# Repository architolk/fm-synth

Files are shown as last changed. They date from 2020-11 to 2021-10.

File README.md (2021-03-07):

# dXFM2

A FM synthesizer with a lot of knobs and no menu!

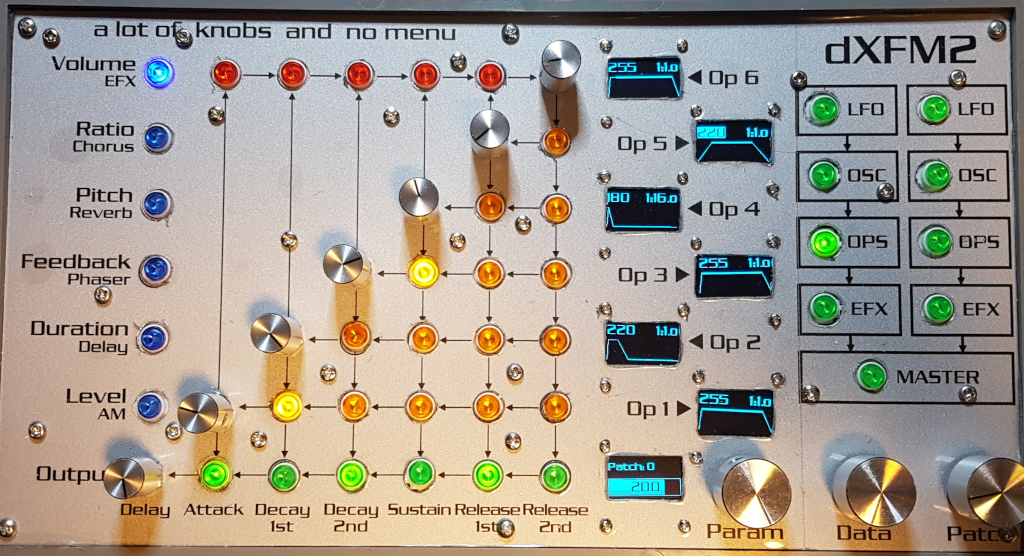
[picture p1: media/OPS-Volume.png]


Always wanted to create lush FM sounds? But to afraid of the menu-driven horrors of FM synthesizers, like the illustrious Yamaha DX7?

The dXFM2 aims to be just that: an FM synthesizer, with the physical feel of an analog synthesizer: a lot of knobs and no menu.

The dXFM2 is based on the incredible work of René Ceballos. He created the XFM2 synthesizer module, a 64-voice, 2-part, 6-operator FM synthesizer with built-in effects processor, built on an FPGA chip. You can find all the information at [www.futur3soundz.com](https://www.futur3soundz.com/xfm2). The dXFM2 complements this with the physical controls for the FPGA chip, managed by a Teensy 4.0.

## Build description

All build descriptions can be found [here](build/README.md). Please note that this is a somewhat free-format description and not intended as build instructions: most things I just found out on-the-fly, so some descriptions might not be completely correct any more.

## Concept of the synth

I always wanted to have an FM synth that I could "understand" just from looking at the display. I do understand the concepts of FM synthesis: carriers that are modulated by modulators. But in most FM synthesizers, it is not clear *which* operator is a carrier and *which* operator is a modulator, and to what extend. The dXFM2 overcomes this problem:

- Every dial corresponds to exactly one operator (the 1 knob for 1 function principle);
- A dedicated dial is used for the output of the synth;
- A green LED indicates that the operator in that column is a **carrier** (follow the arrows): the "green row" corresponds to the output of the synth;
- A yellow LED indicates that the operator in that column is a **modulator** for the operator in the corresponding row;
- A red LED indicates that the operator in that column is a **modulator** for operator 6, notably creating a feedback loop.

This LED-matrix makes the carrier-modulator algorithm visible in a what-you-see-is-what-you-get kind of way. And you can change this on the fly, just by pressing the LED (it's actually a push button).

Some other parameters are very important for the FM sound synthesis:
- The level of the operator;
- The amplitude envelope shape;
- The ratio between operators;
- Whether an operator is modulating itself (feedback).

An as you can see: every operator has its own dedicated small LED screen that displays just this information. The seventh LED screen depicts global information, or in this case: the output volume and the active patch.

## Operating the dXFM2
Although the sound of the FM synthesizer is pretty much *in your face*, the manipulation of that sound does actually involve a bit of menus. For this, you use the green LED buttons on the right side of the synthesizer, selecting a specific page. This activates a particular set of options, which you can further select by using the blue LED buttons on the left side of the synthesizer.

When you look at the green LED buttons, you see that two rows of identical options are available. The dXFM2 has two identifical FM synth units, and by selected between the left or right column, you select the unit for which you want to change a parameter.

- **[LFO](doc/LFO-menu.md)** will enable the parameter page for the low frequency oscillator;
- **[OSC](doc/OSC-menu.md)** will enable the parameter page for the sound oscillators;
- **[OPS](doc/OPS-menu.md)** will enable the parameter page for the operators (selected by default);
- **[EFX](doc/EFX-menu.md)** will enable the parameter page for the effects;
- **[MASTER](doc/MASTER-menu.md)** will enable the parameter page for some global parameters.

And if you really want to do some menu-diving, three additional dials are available:
- The **Param** dial gives you access to a regular menu. From this menu, you can change some more exotic parameters or have some extra options to ease the workflow while shaping FM sounds.
- With the **Data** dial you change some parameter value, as selected with the Param dial.
- With the **Patch** dial you activate a previously stored patch from the XFM2 memory banks (127 patches are available). Select a patch by turning the dial, and activate a patch by pushing the dial (all dials are actually push buttons as well as encoders).

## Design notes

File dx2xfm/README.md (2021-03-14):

# dx2xfm

Conversion code to read a Sysex DX7 file and convert it to XFM2 parameters.

Build: `mvn clean package`

Usage: `./dx2xfm.sh`. This expects a file dx7.syx in the same directory.

## Original DX7 Sysex parameters:

The table below give the DX7 Sysex parameters, captures from the [original DX7 manual](https://usa.yamaha.com/files/download/other_assets/9/333979/DX7E1.pdf), as is available at [the official Yamaha website](https://usa.yamaha.com/support/manuals/index.html?l=en&c=music_production&k=dx7).

| Op 6 | Op 5 | Op 4 | Op 3 | Op 2 | Op 1 | Range | Parameter |
|---|---|---|---|---|---|---|---|
| 0 | 21 | 42 | 63 | 84 | 105 | 0-99 | Op envelope rate 1 |
| 1 | 22 | 43 | 64 | 85 | 106 | 0-99 | Op envelope rate 2 |
| 2 | 23 | 44 | 65 | 86 | 107 | 0-99 | Op envelope rate 3 |
| 3 | 24 | 45 | 66 | 87 | 108 | 0-99 | Op envelope rate 4 |
| 4 | 25 | 46 | 67 | 88 | 109 | 0-99 | Op envelope level 1 |
| 5 | 26 | 47 | 68 | 89 | 110 | 0-99 | Op envelope level 2 |
| 6 | 27 | 48 | 69 | 90 | 111 | 0-99 | Op envelope level 3 |
| 7 | 28 | 49 | 70 | 91 | 112 | 0-99 | Op envelope level 4 |
| 8 | 29 | 50 | 71 | 92 | 113 | 0-99 | KB level scale breakpoint (from A-1 to C8, C3 = 27) |
| 9 | 30 | 51 | 72 | 93 | 114 | 0-99 | KB level scale, left depth |
| 10 | 31 | 52 | 73 | 94 | 115 | 0-99 | KB level scale, right depth |
| 11 | 32 | 53 | 74 | 95 | 116 | 0-3 | Left curve (0=-LIN, 1=-EXP, 2=+EXP, 3=+LIN) |
| 12 | 33 | 54 | 75 | 96 | 117 | 0-3 | Right curve (0=-LIN, 1=-EXP, 2=+EXP, 3=+LIN) |
| 13 | 34 | 55 | 76 | 97 | 118 | 0-7 | Rate scaling |
| 14 | 35 | 56 | 77 | 98 | 119 | 0-3 | AMP Mod sensitivity |
| 15 | 36 | 57 | 78 | 99 | 120 | 0-7 | Key velocity sensitivity |
| 16 | 37 | 58 | 79 | 100 | 121 | 0-99 | Operator output level |
| 17 | 38 | 59 | 80 | 101 | 122 | 0-1 | 0=Ratio, 1=Fixed pitch |
| 18 | 39 | 60 | 81 | 102 | 123 | 0-31 | Coarse frequency ratio |
| 19 | 40 | 61 | 82 | 103 | 124 | 0-99 | Fine frequency ratio (1.00 - 1.99 multiplier)|
| 20 | 41 | 62 | 83 | 104 | 125 | 0-14 | Detune (7 = 0%) |

| Nr | Range | Parameter |
|----|---|---|
| 126 | 0-99 | Pitch envelope rate 1 |
| 127 | 0-99 | Pitch envelope rate 2 |
| 128 | 0-99 | Pitch envelope rate 3 |
| 129 | 0-99 | Pitch envelope rate 4 |
| 130 | 0-99 | Pitch envelope level 1 |
| 131 | 0-99 | Pitch envelope level 2 |
| 132 | 0-99 | Pitch envelope level 3 |
| 133 | 0-99 | Pitch envelope level 4 |
| 134 | 0-31 | Algorithm |
| 135 | 0-7 | Feedback |
| 136 | 0-1 | Oscillator sync (0=off, 1=on)|
| 137 | 0-99 | LFO Speed |
| 138 | 0-99 | LFO Delay |
| 139 | 0-99 | LFO Pitch mod depth |
| 140 | 0-99 | LFO Amp mod depth |
| 141 | 0-1 | LFO Sync (0=off, 1=on) |
| 142 | 0-5 | LFO Waveform (0:TR, 1:SD, 2:SU, 3:SQ, 4:SI, 5:SH)
| 143 | 0-7 | Pitch mod sensitivity |
| 144 | 0-48 | Transpose (24 = C3) |
| 145 | ASCII | Voice name char 1 |
| 146 | ASCII | Voice name char 2 |
| 147 | ASCII | Voice name char 3 |
| 148 | ASCII | Voice name char 4 |
| 149 | ASCII | Voice name char 5 |
| 150 | ASCII | Voice name char 6 |
| 151 | ASCII | Voice name char 7 |
| 152 | ASCII | Voice name char 8 |
| 153 | ASCII | Voice name char 9 |
| 154 | ASCII | Voice name char 10 |

## Explanation of the DX7 parameters

[Understanding the DX7, Jay Chapman](https://www.muzines.co.uk/articles/understanding-the-dx7/7842) and [How to program the DX7, Bo Tomlyn](https://homepages.abdn.ac.uk/d.j.benson/pages/dx7/manuals/prgrmdx7.pdf) give a lot of useful insights.

Very detailed information about the DX7 envelope generators can be found here:
- [The Yamaha DX7 Envelope Generator, part one](https://tlbflush.org/notes/post/dx7eg1/)
- [The Yamaha DX7 Envelope Generator, part two](https://tlbflush.org/notes/post/dx7eg2/)
- [The Yamaha DX7 Envelope Generator, part three](https://tlbflush.org/notes/post/dx7eg3/)
- [The Yamaha DX7 Envelope Generator, part four](https://tlbflush.org/notes/post/dx7eg4/)

Most important conclusions from this information:
- Both envelope increase and decrease are non-lineair.
- Envelope increase is faster than envelope decrease.
- Envelope decrease is exponential, envelope increase is quadratic.

## XFM2 conversion

### Algorithm

| DX7 | XFM2 |
|-----|---|
| 134 | 1 - 6 |

- The algorithms of the DX7 need to be converted to the bitmapped version for the XFM2.
- Mark that the feedback bit (making a XFM2 operator modulates itself) needs to be included as well!
- Algorithm 4 and 6 have feedback that is not self-modulated (from 4 to 6 and from 5 to 6): so probably operator 6 won't have a feedback bit set!

### Feedback

| DX7 | XFM2 |
|-----|---|
| 135 | 7 - 12 |

- DX7 has only one feedback parameter, range 0-7
- XFM2 has a feedback parameter per operator, range 0-255
- The value from DX7 needs to be copied to the feedback parameter of the XFM2 for the operator that has feedback, according to the algorithm.
- Not tested, but assuming a lineair conversion scale: 255/7
- Not sure: is the feedback parameter used for algorithms 4 and 6, or do these algorithms use the operator output level from operator 4 (for algorithm 4) and operator 5 (for algorithm 6)? We assume the the latter: the XFM2 feedback parameter is only for self modulation!

### Oscillator keyboard sync

| DX7 | XFM2 |
|-----|---|
| 136 | 13 |

- DX7 has global oscillator sync, range 0-1
- XFM2 has bitwise oscillator sync, per operator, LSB = operator 1
- When DX7 has oscillator sync enabled, set the XFM2 oscillator sync parameter to 0b00111111 (=63)

### Operator mode

| DX7 | XFM2 |
|-----|---|
| 17,38,59,80,101,122 | 14 |

- DX7 has a parameter per operator. 0 = ratio, 1 = fixed pitch
- XFM2 has a bitwise parameter. LSB = operator 1. 0 = ratio, 1 = fixed pitch

The conversion for the coarse & fine frequency parameters are different with respect to this parameter!

### Fixed pitch parameter conversion

When using fixed pitch operator mode, the frequency is obtained on the DX7 using the following formula: COARSE * FINE:
- COARSE is a value between 0-3, corresponding to 1Hz, 10Hz, 100Hz or 1000Hz (=HZ-COARSE);
- FINE is a value between 0-99, corresponding with multipliers 1 to 9.772
- The actual formula to get the frequency for the D7 is: Hz = HZ-COARSE * (1 + (FINE * 8.772 / 99))

When using fixed pitch operator mode, the frequency is obtained on the XFM2 using the following formula: COARSE * FINE:
- COARSE is a value between 0-255, frequency is calculated using the formula Hz = COARSE * 32.7
- FINE is a value between 0-255, using the same formula as with frequency fine ratio, so: 2^(FINE/256), for [equal temperament](https://en.wikipedia.org/wiki/Equal_temperament).
- The actual formula to get the frequency for the XFM2 is: Hz = COARSE * 32.7 * 2^(FINE/256)
- An approximation for this formula is: Hz = COARSE * 32.7 * (1 + (FINE/256) * (FINE/256) * 0.34 + (FINE/256) * 0.66)
- The multiplication range for the XFM2 FINE parameter can be calculated from this: it goes from 1 to 1.9946
- Need to check: this would mean that a frequency below 32.7 is not possible using fixed pitch rate. Maybe COARSE = 0 is actually 16.35?

Conversion of coarse & fine parameters in fixed pitch mode needs to be combined: the resulting value for the XFM2 coarse parameter depends on both the coarse & fine parameters of the DX7, for reference see this table:

|DX7 Coarse | DX7 Fine | Hz | XFM2 Coarse | XFM2 Fine |
|---|---|----|---|---|
| 1 | 0 | 10 Hz | ? | ? |
| 1 | 50 | 54 Hz | 1 | 187 |
| 1 | 99 | 98 Hz | 2 | 148 |
| 2 | 0 | 100 Hz | 3 | 7 |
| 2 | 10 | 189 Hz | 5 | 53 |
| 2 | 99 | 997 Hz | 29 | 11 |
| 3 | 0 | 1000 Hz | 30 | 7 |
| 3 | 10 | 1886 Hz | 57 | 4 |
| 3 | 99 | 9772 Hz | 298 | 1 |

The correct conversion is as follows:
- XFM2-COARSE = Hz / 32.7, rounded down (not using fractions), Hz being the "correct" frequency as calculated for the DX7
- Let HZ-FINE be the fine ratio in Hz needed get to the "correct" frequency: HZ-FINE = (Hz - XFM2-COARSE) / Hz
- XFM2-FINE = 256 / Log2(1 + HZ-FINE)

**NB**: this conversion is ONLY correct for XMF2 Tuning parameter value 0 (= normal tuning = [equal temperament](https://en.wikipedia.org/wiki/Equal_temperament))

### Frequency coarse ratio

| DX7 | XFM2 |
|-----|---|
| 18,39,60,81,102,123 | 15-20 |

- Coarse frequency works the same for DX7 and XFM2
- Range of the XFM2 runs all the way up to 255, DX7 only goes to 31: XFM2 can have higher coarse frequency rates.
- A coarse frequency of 0 on the DX7 is usually depicted as ratio 0.50 (what it actually is: a sub-oscillator)

### Frequency fine ratio

| DX7 | XFM2 |
|-----|---|
| 19,40,61,82,103,124 | 21-26 |

- Fine ratio on the DX7 is a percentage of the frequency. A4 (=440 Hz) with frequency ratio 1.10 (coarse = 1, fine = 10) results in a frequency of 484. The calculation is F = Fc * (1 + Rf/100), F being the resulting frequency, Fc the frequency with only the coarse part and Rf the fine ratio parameter value.
- Fine ratio on the XFM2 is a percentage of an octave. Using [equal temperament](https://en.wikipedia.org/wiki/Equal_temperament), this means that the calculation is actually F = Fc * 2^(Rf/256). So to get the correct ratio, the value is actually fine = 35.
- The correct conversion would be: XFM2 fine = 256 / Log2(1 + Rf/100), Rf being the fine ratio parameter value of the DX7.

**NB**: this conversion is ONLY correct for XMF2 Tuning parameter value 0 (= normal tuning = [equal temperament](https://en.wikipedia.org/wiki/Equal_temperament))

### Detune

| DX7 | XFM2 |
|-----|---|
| 20,41,62,83,104,125 | 27-32 |

- DX7 detune is ranged 0-14, 0 corresponds to -7, 7 corresponds to 0, 14 corresponds to +7
- XFM2 detune is ranged 0-255, 0 corresponeds to -127, 128 corresponds to 0, 127 corresponds to +127
- DX7 detune segments an fine pitch interval of the DX7 (rang -0.007 to +0.007? Not sure..)
- XFM2 detune is ranged in cents, so an interval within a semitone of an octave (see also frequency fine ratio)
- The means: DX7 has detune with respect to frequency, XFM2 has detune with respect to semitones: same different as for frequency fine ratio. But because the intervals are so small, we will probably get away with a fixed conversion ratio.

### Levels

| DX7 | XFM2 |
|-----|---|
| 16,37,58,79,100,121 | 33 - 38 |

- Levels on the DX7 range from 0-99
- Levels on the XFM2 range from 0-255
- Unsure whether the conversion should be linear or some other function. Assumption is linear, so LEVEL * 255/99
- Maybe this info is needed? https://sound.stackexchange.com/questions/31709/what-is-the-level-of-frequency-modulation-of-many-synthesizers

DX7 Levels with respect to modulation index (from [Music: a mathematical offering, Apendix B](https://homepages.abdn.ac.uk/d.j.benson/pages/html/music.pdf), David Benson. The calculation in [Synthesis: FM pt2](https://sites.google.com/site/yalaorg/audio-music-synthesis/fmsynth/fmsynthdx) are the same, but have a higher accuracy, and this page describes the actual formula that is used:

Let:
- DX7: the parameter value (range 0-99)
- TL, the TL-number (?), TL = 99-DX7 for DX7>=20, and for lower values we have to use a look-up table (the output is non-lineair)
- I: the modulation index, I = PI * 2^((33/16) - (TL/8))

Look-up table for TL:
DX7 | 0 | 1 | 2 | 3 | 4 | 5 | 6 | 7 | 8 | 9 | 10 | 11 | 12 | 13 | 14 | 15 | 16 | 17 | 18 | 19 |
----|---|---|---|---|---|---|---|---|---|---|----|----|----|----|----|----|----|----|----|----|
TL  |127|122|118|114|110|107|104|102|100| 98| 96 | 94 | 92 | 90 | 88 | 86 | 85 | 84 | 82 | 81 |

| DX7 | Index | Original | Difference |
|-----|---|---|---|
|  0 | 0.0002 | 0? | |
| 10 | 0.0032 | 0.003 | 6,79% |
| 20 | 0.0140 | 0.013 | 7,50% |
| 30 | 0.0332 | 0.031 | 7,22% |
| 40 | 0.0791 | 0.079 | 0,07% |
| 50 | 0.1880 | 0.188 | 0,01% |
| 60 | 0.4472 | 0.446 | 0,27% |
| 65 | 0.6897 | 0.690 | 0,05% |
| 70 | 1.0636 | 1.068 | 0,41% |
| 75 | 1.6403 | 1.639 | 0,08% |
| 80 | 2.5298 | 2.512 | 0,71% |
| 85 | 3.9014 | 3.894 | 0,19% |
| 90 | 6.0168 | 6.029 | 0,20% |
| 95 | 9.2792 | 9.263 | 0,17% |
| 99 | 13.123 | 13.119 | 0,03% |

([this excel](../doc/fmsynthesis/DX7ModulationIndex.xlsx) sheet has all the individual numbers and the actual calculation).

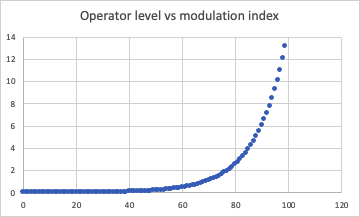
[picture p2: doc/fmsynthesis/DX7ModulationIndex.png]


The numbers differ a bit from the numbers in  *FM Theory & Applications, John Chowning*, the third column named "Original". Especially the calculated index for 0 seems a bit odd, probably the result of using an exponential function with y asymptote = 0. The DX7 would not use a function to calculate these indices, but a lookup table, so param value 0 would probably be set to modulation index 0. But as you can see from the fourth column and the graph below, the differences are very small. From param value 40, the difference is always less than 1%.

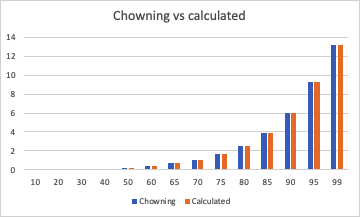
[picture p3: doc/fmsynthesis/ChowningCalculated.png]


### Key velocity sensitivity

| DX7 | XMF2 |
|-----|---|
| 15,36,57,78,99,120 | 39 - 44 |

### KB level scale

| Param | DX7 | XFM2 |
|---|-----|---|
| Breakpoint | 8,29,50,71,92,113 | 45 - 50 |
| Left depth | 9,30,51,72,93,114 | 51 - 56 |
| Right depth | 10,31,52,73,94,115 | 57 - 62 |
| Left curve | 11,32,53,74,95,116 | 63 - 68
| Right curve | 12,33,54,75,96,117 | 69 - 74 |

### Operator level envelope

| Param | DX7 | XFM2 |
|---|-----|---|
| L1 | 4,25,46,67,88,109 | 75 - 80 |
| L2 | 5,26,47,68,89 | 82 - 87 |
| L3 | 6,27,48,69,90 | 89 - 94 |
| L4 | 7,28,49,70,91,112 | 96 - 101 |
| R1 | 0,21,42,63,84,105 | 103 - 108 |
| R2 | 1,22,43,64,85,106 | 110 - 115 |
| R3 | 2,23,44,65,86,107 | 117 - 122 |
| R4 | 3,24,45,66,87,108 | 124 - 129 |

- The DX7 envelope doesn't start at 0, but at the level of L4, which most of the time will be 0.
- The XFM2 envelope starts at level L0. So to convert the levels correctly: L4 of the DX7 should also be used to calculate L0 of the XFM2:

| Param | DX7 | XFM2 |
|---|-----|---|
| L0 | 7,28,49,70,91,112 | 181 - 186 |

### Pitch envelope

| Param | DX7 | XFM2 |
|---|-----|---|
| L1 | 130 | 130 |
| L2 | 131 | 131 |
| L3 | 132 | 132 |
| L4 | 133 | 133 |
| R1 | 126 | 134 |
| R2 | 127 | 135 |
| R3 | 128 | 136 |
| R4 | 129 | 137 |

- The DX7 envelope doesn't start at 0, but at the level of L4, which most of the time will be 0.
- The XFM2 envelope starts at level L0. So to convert the levels correctly: L4 of the DX7 should also be used to calculate L0 of the XFM2:

| Param | DX7 | XFM2 |
|---|-----|---|
| L0 | 133 | 205 |

### Pitch envelope range

| DX7 | XFM2 |
|-----|---|
| - | 138 |

- The pitch envelope range defines the range of the pitch envelope on the XFM2, in octaves.
- The DX7 doesn't have this parameter. The pitch envelope range is fixed to -4 to +4 octaves (0 = -4, 50 = 0, 99 = -4)

### Pitch envelope range velocity

| DX7 | XFM2 |
|-----|---|
| - | 139 |

- The pitch envelope range velocity sets how much the pitch envelope range changes with MIDI velocity on the XFM2.
- The DX7 doesn't have this parameter. The pitch envelope range is fixed to -4 to +4 octaves.
- Leave this parameter to 0: pitch envelope range velocity is not available on the DX7.

### Operator level envelope rate key

| DX7 | XFM2 |
|-----|---|
| 13,34,55,76,97,118 | 140 - 145 |

- This parameter will make higher notes have a faster envelope than lower, bass, notes. It works rougly the same on the DX7 and XFM2.
- The operator level envelope rate key on the XFM2 works the same as other rates: 0 gives the normal, slowest envelope, 255 gives a very snappy, fast envelope (at high notes).
- The DX7 works the same way, but with a different scale: 0 gives the normal, slowest envelope, 7 gives the fasted envelope (at high notes).

### Pitch envelope rate key

| DX7 | XFM2 |
|-----|---|
| - | 146 |

- The pitch envelope rate key on the XFM2 works the same way as the operator level envelope rate key: changing the timing
- THe DX7 doesn't have this parameter. The pitch envelope timing is fixed.

### LFO Pitch depth

| DX7 | XFM2 |
|-----|---|
| 139 | 149 |

### LFO Amp depth

| DX7 | XFM2 |
|-----|---|
| 140 | 150 |

### LFO Speed

| DX7 | XFM2 |
|-----|---|
| 137 | 151 |

- The LFO speed of the DX7 might go from 0.1 Hz to 60 Hz, but other values are 3.5 Hz to 47 Hz. It seems quite linear at the bottom, but high values seems to increase the speed more than low values.
- The LFO speed of the XFM2 seems pretty linear, a multiplication of 2.76 BPM per parameter value (276 BPM for value 100, 28 BPM for value 10), but higher values also seems to increase the speed?
- The LFO's of the DX7 and XFM2 do not have the same speed range apparently, so some conversion seems to be necessary?

### LFO Sync

| DX7 | XFM2 |
|-----|---|
| 141 | 152 |

### LFO Wave

| DX7 | XFM2 |
|-----|---|
| 142 | 153 |

The DX7 and the XFM2 have the same possible wave forms for the LFO, if you would consider the S/H (Sample & Hold) waveform the same as the random waveform of the XFM2, using the following conversion table:

| Waveform | DX7 | XFM2 |
|---|-----|---|
| Triangle | 0 | 0 |
| Saw down | 1 | 3 |
| Saw up | 2 | 2 |
| Square | 3 | 1 |
| Sinus | 4 | 4 |
| S/H, Random | 5 | 5 |

### LFO Fade/Delay

| DX7 | XFM2 |
|-----|---|
| 138 | 154 |

- This parameter is called "Fade" on the XFM2 and "Delay" on the DX7. Not sure if it is the same thing.
- From the XFM2 manual, "Fade" is the time to ramp up to the specified LFO effect.
- From the DX7 manaul, "Delay" is simply that: a delay of the LFO effect.
- This assumes that the functionality is somewhat different: a ramp-up effect vs a delayed effect

### LFO Amp sensitivity

| DX7 | XFM2 |
|-----|---|
| 14,35,56,77,98,119 | 159 - 164 |

### Transpose

| DX7 | XFM2 |
|-----|---|
| 144 | 174 |

Transpose 24 = no transpose, so 24 corresponds with C4.

Midi note implementation:
- C4 = MIDI 60 = 261.63 Hz
- A4 = MIDI 69 = 440.00 Hz

### (LFO) Pitch sensitivity

| DX7 | XFM2 |
|-----|---|
| 143 | 222 - 227 |

- The DX7 pitch sensitivity parameter sets the same value for every operator.
- The XFM2 has a pitch sensitivity parameter per operator.

## Conversion reference

The table below gives a reference guide for all 154 parameters of the DX7

| DX7 | Param | XFM2 |
|-----|---|---|
| 0 | OP-6 Envelope rate 1 | 108 |
| 1 | OP-6 Envelope rate 2 | 115 |
| 2 | OP-6 Envelope rate 3 | 122 |
| 3 | OP-6 Envelope rate 4 | 129 |
| 4 | OP-6 Envelope level 1 | 80 |
| 5 | OP-6 Envelope level 2 | 87 |
| 6 | OP-6 Envelope level 3 | 94 |
| 7 | OP-6 Envelope level 4 | 101 |
| 8 | OP-6 KB level scale breakpoint | 50 |
| 9 | OP-6 KB level scale, left depth | 56 |
| 10 | OP-6 KB level scale, right depth | 62 |
| 11 | OP-6 KB level scale, left curve | 68 |
| 12 | OP-6 KB level scale, right curve | 74 |
| 13 | OP-6 Rate scaling | 145 |
| 14 | OP-6 AMP Mod sensitivity | 164 |
| 15 | OP-6 Key velocity sensitivity | 44 |
| 16 | OP-6 Operator output level | 38 |
| 17 | OP-6 Operator mode (ratio/pitch) | 14 |
| 18 | OP-6 Coarse frequency ratio | 20 |
| 19 | OP-6 Fine frequency ratio | 26 |
| 20 | OP-6 Detune | 32 |
| 21 | OP-5 Envelope rate 1 |  |
| 22 | OP-5 Envelope rate 2 |  |
| 23 | OP-5 Envelope rate 3 |  |
| 24 | OP-5 Envelope rate 4 |  |
| 25 | OP-5 Envelope level 1 |  |
| 26 | OP-5 Envelope level 2 |  |
| 27 | OP-5 Envelope level 3 |  |
| 28 | OP-5 Envelope level 4 |  |
| 29 | OP-5 KB level scale breakpoint |  |
| 30 | OP-5 KB level scale, left depth |  |
| 31 | OP-5 KB level scale, right depth |  |
| 32 | OP-5 Left curve |  |
| 33 | OP-5 Right curve |  |
| 34 | OP-5 Rate scaling |  |
| 35 | OP-5 AMP Mod sensitivity |  |
| 36 | OP-5 Key velocity sensitivity |  |
| 37 | OP-5 Operator output level |  |
| 38 | OP-5 Operator mode (ratio/pitch) |  |
| 39 | OP-5 Coarse frequency ratio |  |
| 40 | OP-5 Fine frequency ratio |  |
| 41 | OP-5 Detune |  |
| 42 | OP-4 Envelope rate 1 |  |
| 43 | OP-4 Envelope rate 2 |  |
| 44 | OP-4 Envelope rate 3 |  |
| 45 | OP-4 Envelope rate 4 |  |
| 46 | OP-4 Envelope level 1 |  |
| 47 | OP-4 Envelope level 2 |  |
| 48 | OP-4 Envelope level 3 |  |
| 49 | OP-4 Envelope level 4 |  |
| 50 | OP-4 KB level scale breakpoint |  |
| 51 | OP-4 KB level scale, left depth |  |
| 52 | OP-4 KB level scale, right depth |  |
| 53 | OP-4 Left curve |  |
| 54 | OP-4 Right curve |  |
| 55 | OP-4 Rate scaling |  |
| 56 | OP-4 AMP Mod sensitivity |  |
| 57 | OP-4 Key velocity sensitivity |  |
| 58 | OP-4 Operator output level |  |
| 59 | OP-4 Operator mode (ratio/pitch) |  |
| 60 | OP-4 Coarse frequency ratio |  |
| 61 | OP-4 Fine frequency ratio |  |
| 62 | OP-4 Detune |  |
| 63 | OP-3 Envelope rate 1 |  |
| 64 | OP-3 Envelope rate 2 |  |
| 65 | OP-3 Envelope rate 3 |  |
| 66 | OP-3 Envelope rate 4 |  |
| 67 | OP-3 Envelope level 1 |  |
| 68 | OP-3 Envelope level 2 |  |
| 69 | OP-3 Envelope level 3 |  |
| 70 | OP-3 Envelope level 4 |  |
| 71 | OP-3 KB level scale breakpoint |  |
| 72 | OP-3 KB level scale, left depth |  |
| 73 | OP-3 KB level scale, right depth |  |
| 74 | OP-3 Left curve |  |
| 75 | OP-3 Right curve |  |
| 76 | OP-3 Rate scaling |  |
| 77 | OP-3 AMP Mod sensitivity |  |
| 78 | OP-3 Key velocity sensitivity |  |
| 79 | OP-3 Operator output level |  |
| 80 | OP-3 Operator mode (ratio/pitch) |  |
| 81 | OP-3 Coarse frequency ratio |  |
| 82 | OP-3 Fine frequency ratio |  |
| 83 | OP-3 Detune |  |
| 84 | OP-2 Envelope rate 1 |  |
| 85 | OP-2 Envelope rate 2 |  |
| 86 | OP-2 Envelope rate 3 |  |
| 87 | OP-2 Envelope rate 4 |  |
| 88 | OP-2 Envelope level 1 |  |
| 89 | OP-2 Envelope level 2 |  |
| 90 | OP-2 Envelope level 3 |  |
| 91 | OP-2 Envelope level 4 |  |
| 92 | OP-2 KB level scale breakpoint |  |
| 93 | OP-2 KB level scale, left depth |  |
| 94 | OP-2 KB level scale, right depth |  |
| 95 | OP-2 Left curve |  |
| 96 | OP-2 Right curve |  |
| 97 | OP-2 Rate scaling |  |
| 98 | OP-2 AMP Mod sensitivity |  |
| 99 | OP-2 Key velocity sensitivity |  |
| 100 | OP-2 Operator output level |  |
| 101 | OP-2 Operator mode (ratio/pitch) |  |
| 102 | OP-2 Coarse frequency ratio |  |
| 103 | OP-2 Fine frequency ratio |  |
| 104 | OP-2 Detune |  |
| 105 | OP-1 Envelope rate 1 |  |
| 106 | OP-1 Envelope rate 2 |  |
| 107 | OP-1 Envelope rate 3 |  |
| 108 | OP-1 Envelope rate 4 |  |
| 109 | OP-1 Envelope level 1 |  |
| 110 | OP-1 Envelope level 2 |  |
| 111 | OP-1 Envelope level 3 |  |
| 112 | OP-1 Envelope level 4 |  |
| 113 | OP-1 KB level scale breakpoint |  |
| 114 | OP-1 KB level scale, left depth |  |
| 115 | OP-1 KB level scale, right depth |  |
| 116 | OP-1 Left curve |  |
| 117 | OP-1 Right curve |  |
| 118 | OP-1 Rate scaling |  |
| 119 | OP-1 AMP Mod sensitivity |  |
| 120 | OP-1 Key velocity sensitivity |  |
| 121 | OP-1 Operator output level |  |
| 122 | OP-1 Operator mode (ratio/pitch) |  |
| 123 | OP-1 Coarse frequency ratio |  |
| 124 | OP-1 Fine frequency ratio |  |
| 125 | OP-1 Detune |  |
| 126 | Pitch envelope rate 1 | 134 |
| 127 | Pitch envelope rate 2 | 135 |
| 128 | Pitch envelope rate 3 | 136 |
| 129 | Pitch envelope rate 4 | 137 |
| 130 | Pitch envelope level 1 | 130 |
| 131 | Pitch envelope level 2 | 131 |
| 132 | Pitch envelope level 3 | 132 |
| 133 | Pitch envelope level 4 | 133 |
| 134 | Algorithm | 1 - 6 |
| 135 | Feedback | 7 - 12 |
| 136 | Oscillator sync | 13 |
| 137 | LFO Speed | 151 |
| 138 | LFO Delay | 154 |
| 139 | LFO Pitch mod depth | 149 |
| 140 | LFO Amp mod depth | 150 |
| 141 | LFO Sync | 152 |
| 142 | LFO Waveform | 153 |
| 143 | Pitch mod sensitivity | 222 - 227 |
| 144 | Transpose | 174 |
| 145 | Voice name char 1 | - |
| 146 | Voice name char 2 | - |
| 147 | Voice name char 3 | - |
| 148 | Voice name char 4 | - |
| 149 | Voice name char 5 | - |
| 150 | Voice name char 6 | - |
| 151 | Voice name char 7 | - |
| 152 | Voice name char 8 | - |
| 153 | Voice name char 9 | - |
| 154 | Voice name char 10 | - |

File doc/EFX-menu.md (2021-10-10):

# EFX Effects menu

| Blue | 6 (Out) | 0 (Op1) | 1 (Op2) | 2 (Op3) | 3 (Op4) | 4 (Op5) | 5 (Op6) |
|---|---|---|---|---|---|---|---|
| 0 |  |  | *Bitcrusher* Depth | *Decimator* Depth | *Filter* Hi pass | *Filter* Lo pass | EFX Routing |
| 1 | *Chorus* Dry | *Chorus* LR Phase | *Chorus* Speed | *Chorus* Feedback | *Chorus* Depth | *Chorus* Mode | *Chorus* Wet |
| 2 | *Reverb* Dry | | *Reverb* Decay |  | *Reverb* Damp | *Reverb* Mode | *Reverb* Wet |
| 3 | *Phaser* Dry | *Phaser* LR Phase/Offset | *Phaser* Speed | *Phaser* Feedback | *Phaser* Depth | *Phaser* Mode/Stages | *Phaser* Wet |
| 4 | *Delay* Dry | *Delay* Multiplier/Devider | *Delay* Time/Tempo | *Delay* Feedback | *Delay* Hi/Lo pass | *Delay* Mode | *Delay* Wet |
| 5 |  | *AM* LR Phase | *AM* Speed |  | *AM* Range |  | *AM* Depth |

Chorus/Flanger is the same effect, switching between those two is done via the **Mode** parameter.

Parameter value mapping:

| Value | 0 (Op1) | 1 (Op2) | 2 (Op3) | 3 (Op4) | 4 (Op5) | 5 (Op6) | 6 (Out) |
|---|---|---|---|---|---|---|---|
| 0 | 0 | 0 | 380 | 370 | 321 | 320 | 410 |
| 1 | 360 | 366 | 363 | 365 | 364 | 362 | 361 |
| 2 | 390 | 0 | 393 | 0 | 394 | 392 | 391 |
| 3 | 310 | 318/316 | 314 | 315 | 313 | 312/317 | 311 |
| 4 | 300 | 308/309 | 303/307 | 304 | 306/305 | 302 | 301 |
| 5 | 0 | 333 | 330 | 0 | 331 | 0 | 332 |

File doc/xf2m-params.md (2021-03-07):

# XFM2 params

This page gives an overview of all XFM2 parameters. It is a cross-reference to the assignment at the physical hardware level, to be sure that every parameter is covered.

- A *italic* item in the table below for the Blue buttons indicate that this option has two different parameters you can change. You need to toggle between these two parameters (by pressing the corresponding blue button again). The one you selected is marked with a bar below the corresponding parameter.
- **Op-1 dial** corresponds to turning the Op-1 dial. **Op dials** means that the parameter contains a bitwise setting for all operators, so a particular Op dial changes the parameter with respect to the corresponding operator.
- **Op dials click** corresponds to pressing an operator dial (using it as a push button).
- **Op-1 selected** corresponds to selecting operator-1 envelope. For the operator level envelopes, you select a particular operator by pressing the corresponding operator dial. To change the particular parameter, you use the corresponding dial for that parameter (as depicted at the bottom of the synth). This might be some *other* dial than the dial that corresponds to that operator!
- Most parameters work for both Unit #1 and Unit #2: you switch between units by selecting the corresponding **green** option. The exception are some parameters that are controlled by the master mixer, as depicted in the table below:

| Blue | Assignment | Unit |
|---|---|---|
| Pitch | Velocity sensitivity | 1 |
| Feedback | Velocity sensitivity | 2 |
| Duration | Mixer | 1 |
| Level | Mixer | 2 |

| Nr | Parameter | Green | Blue | Assignment |
|----|---|---|---|---|
| 0 | NOP | - | - | - |
| 1 | Algorithm Op-1 | - | - | Orange & Red LEDs, Op-1 row |
| 2 | Algorithm Op-2 | - | - | Orange & Red LEDs, Op-2 row |
| 3 | Algorithm Op-3 | - | - | Orange & Red LEDs, Op-3 row |
| 4 | Algorithm Op-4 | - | - | Orange & Red LEDs, Op-4 row |
| 5 | Algorithm Op-5 | - | - | Orange & Red LEDs, Op-5 row |
| 6 | Algorithm Op-6 | - | - | Orange & Red LEDs, Op-6 row |
| 7 | Feedback Op-1 | OPS | Feedback | Op-1 dial |
| 8 | Feedback Op-2 | OPS | Feedback | Op-2 dial |
| 9 | Feedback Op-3 | OPS | Feedback | Op-3 dial |
| 10 | Feedback Op-4 | OPS | Feedback | Op-4 dial |
| 11 | Feedback Op-5 | OPS | Feedback | Op-5 dial |
| 12 | Feedback Op-6 | OPS | Feedback | Op-6 dial |
| 13 | Oscillator sync | OSC | *Feedback* | Op dials |
| 14 | Operator mode | OPS | Pitch | Op dials click |
| 15 | Coarse ratio Op-1 | OPS | *Ratio* | Op-1 dial |
| 16 | Coarse ratio Op-2 | OPS | *Ratio* | Op-2 dial |
| 17 | Coarse ratio Op-3 | OPS | *Ratio* | Op-3 dial |
| 18 | Coarse ratio Op-4 | OPS | *Ratio* | Op-4 dial |
| 19 | Coarse ratio Op-5 | OPS | *Ratio* | Op-5 dial |
| 20 | Coarse ratio Op-6 | OPS | *Ratio* | Op-6 dial |
| 21 | Fine ratio Op-1 | OPS | *Ratio* | Op-1 dial |
| 22 | Fine ratio Op-2 | OPS | *Ratio* | Op-2 dial |
| 23 | Fine ratio Op-3 | OPS | *Ratio* | Op-3 dial |
| 24 | Fine ratio Op-4 | OPS | *Ratio* | Op-4 dial |
| 25 | Fine ratio Op-5 | OPS | *Ratio* | Op-5 dial |
| 26 | Fine ratio Op-6 | OPS | *Ratio* | Op-6 dial |
| 27 | Detune Op-1 | OPS | Pitch | Op-1 dial |
| 28 | Detune Op-2 | OPS | Pitch | Op-2 dial |
| 29 | Detune Op-3 | OPS | Pitch | Op-3 dial |
| 30 | Detune Op-4 | OPS | Pitch | Op-4 dial |
| 31 | Detune Op-5 | OPS | Pitch | Op-5 dial |
| 32 | Detune Op-6 | OPS | Pitch | Op-6 dial |
| 33 | Level Op-1 | OPS | Volume | Op-1 dial |
| 34 | Level Op-2 | OPS | Volume | Op-2 dial |
| 35 | Level Op-3 | OPS | Volume | Op-3 dial |
| 36 | Level Op-4 | OPS | Volume | Op-4 dial |
| 37 | Level Op-5 | OPS | Volume | Op-5 dial |
| 38 | Level Op-6 | OPS | Volume | Op-6 dial |
| 39 | Velo sense Op-1 | Master | Pitch/Feedback | Op-1 dial |
| 40 | Velo sense Op-2 | Master | Pitch/Feedback | Op-2 dial |
| 41 | Velo sense Op-3 | Master | Pitch/Feedback | Op-3 dial |
| 42 | Velo sense Op-4 | Master | Pitch/Feedback | Op-4 dial |
| 43 | Velo sense Op-5 | Master | Pitch/Feedback | Op-5 dial |
| 44 | Velo sense Op-6 | Master | Pitch/Feedback | Op-6 dial |
| 45 | KB level scale breakpoint Op-1 | LFO | Pitch | Op-1 dial |
| 46 | KB level scale breakpoint Op-2 | LFO | Pitch | Op-2 dial |
| 47 | KB level scale breakpoint Op-3 | LFO | Pitch | Op-3 dial |
| 48 | KB level scale breakpoint Op-4 | LFO | Pitch | Op-4 dial |
| 49 | KB level scale breakpoint Op-5 | LFO | Pitch | Op-5 dial |
| 50 | KB level scale breakpoint Op-6 | LFO | Pitch | Op-6 dial |
| 51 | KB level scale, left depth Op-1 | LFO | *Ratio* | Op-1 dial |
| 52 | KB level scale, left depth Op-2 | LFO | *Ratio* | Op-2 dial |
| 53 | KB level scale, left depth Op-3 | LFO | *Ratio* | Op-3 dial |
| 54 | KB level scale, left depth Op-4 | LFO | *Ratio* | Op-4 dial |
| 55 | KB level scale, left depth Op-5 | LFO | *Ratio* | Op-5 dial |
| 56 | KB level scale, left depth Op-6 | LFO | *Ratio* | Op-6 dial |
| 57 | KB level scale, right depth Op-1 | LFO | *Feedback* | Op-1 dial |
| 58 | KB level scale, right depth Op-2 | LFO | *Feedback* | Op-2 dial |
| 59 | KB level scale, right depth Op-3 | LFO | *Feedback* | Op-3 dial |
| 60 | KB level scale, right depth Op-4 | LFO | *Feedback* | Op-4 dial |
| 61 | KB level scale, right depth Op-5 | LFO | *Feedback* | Op-5 dial |
| 62 | KB level scale, right depth Op-6 | LFO | *Feedback* | Op-6 dial |
| 63 | KB level scale, left curve Op-1 | LFO | *Ratio* | Op-1 dial |
| 64 | KB level scale, left curve Op-2 | LFO | *Ratio* | Op-2 dial |
| 65 | KB level scale, left curve Op-3 | LFO | *Ratio* | Op-3 dial |
| 66 | KB level scale, left curve Op-4 | LFO | *Ratio* | Op-4 dial |
| 67 | KB level scale, left curve Op-5 | LFO | *Ratio* | Op-5 dial |
| 68 | KB level scale, left curve Op-6 | LFO | *Ratio* | Op-6 dial |
| 69 | KB level scale, right curve Op-1 | LFO | *Feedback* | Op-1 dial |
| 70 | KB level scale, right curve Op-2 | LFO | *Feedback* | Op-2 dial |
| 71 | KB level scale, right curve Op-3 | LFO | *Feedback* | Op-3 dial |
| 72 | KB level scale, right curve Op-4 | LFO | *Feedback* | Op-4 dial |
| 73 | KB level scale, right curve Op-5 | LFO | *Feedback* | Op-5 dial |
| 74 | KB level scale, right curve Op-6 | LFO | *Feedback* | Op-6 dial |
| 75 | Envelope level 1, Op-1 | OPS | Level | Op-1 dial (attack) / Op-1 selected |
| 76 | Envelope level 1, Op-1 | OPS | Level | Op-1 dial (attack) / Op-2 selected |
| 77 | Envelope level 1, Op-1 | OPS | Level | Op-1 dial (attack) / Op-3 selected |
| 78 | Envelope level 1, Op-1 | OPS | Level | Op-1 dial (attack) / Op-4 selected |
| 79 | Envelope level 1, Op-1 | OPS | Level | Op-1 dial (attack) / Op-5 selected |
| 80 | Envelope level 1, Op-1 | OPS | Level | Op-1 dial (attack) / Op-6 selected |
| 81 | NOP | - | - | - |
| 82 | Envelope level 2, Op-1 | OPS | Level | Op-2 dial (decay-1) / Op-1 selected |
| 83 | Envelope level 2, Op-1 | OPS | Level | Op-2 dial (decay-1) / Op-2 selected |
| 84 | Envelope level 2, Op-1 | OPS | Level | Op-2 dial (decay-1) / Op-3 selected |
| 85 | Envelope level 2, Op-1 | OPS | Level | Op-2 dial (decay-1) / Op-4 selected |
| 86 | Envelope level 2, Op-1 | OPS | Level | Op-2 dial (decay-1) / Op-5 selected |
| 87 | Envelope level 2, Op-1 | OPS | Level | Op-2 dial (decay-1) / Op-6 selected |
| 88 | NOP | - | - | - |
| 89 | Envelope level 3, Op-1 | OPS | Level | Op-4 dial (sustain) / Op-1 selected |
| 90 | Envelope level 3, Op-1 | OPS | Level | Op-4 dial (sustain) / Op-2 selected |
| 91 | Envelope level 3, Op-1 | OPS | Level | Op-4 dial (sustain) / Op-3 selected |
| 92 | Envelope level 3, Op-1 | OPS | Level | Op-4 dial (sustain) / Op-4 selected |
| 93 | Envelope level 3, Op-1 | OPS | Level | Op-4 dial (sustain) / Op-5 selected |
| 94 | Envelope level 3, Op-1 | OPS | Level | Op-4 dial (sustain) / Op-6 selected |
| 95 | NOP | - | - | - |
| 96 | Envelope level 4, Op-1 | OPS | Level | Op-5 dial (release-1) / Op-1 selected |
| 97 | Envelope level 4, Op-1 | OPS | Level | Op-5 dial (release-1) / Op-2 selected |
| 98 | Envelope level 4, Op-1 | OPS | Level | Op-5 dial (release-1) / Op-3 selected |
| 99 | Envelope level 4, Op-1 | OPS | Level | Op-5 dial (release-1) / Op-4 selected |
| 100 | Envelope level 4, Op-1 | OPS | Level | Op-5 dial (release-1) / Op-5 selected |
| 101 | Envelope level 4, Op-1 | OPS | Level | Op-5 dial (release-1) / Op-6 selected |
| 102 | NOP | - | - | - |
| 103 | Envelope rate 1, Op-1 | OPS | Duration | Op-1 dial (attack) / Op-1 selected |
| 104 | Envelope rate 1, Op-1 | OPS | Duration | Op-1 dial (attack) / Op-2 selected |
| 105 | Envelope rate 1, Op-1 | OPS | Duration | Op-1 dial (attack) / Op-3 selected |
| 106 | Envelope rate 1, Op-1 | OPS | Duration | Op-1 dial (attack) / Op-4 selected |
| 107 | Envelope rate 1, Op-1 | OPS | Duration | Op-1 dial (attack) / Op-5 selected |
| 108 | Envelope rate 1, Op-1 | OPS | Duration | Op-1 dial (attack) / Op-6 selected |
| 109 | NOP | - | - | - |
| 110 | Envelope rate 2, Op-1 | OPS | Duration | Op-2 dial (decay-1) / Op-1 selected |
| 111 | Envelope rate 2, Op-1 | OPS | Duration | Op-2 dial (decay-1) / Op-2 selected |
| 112 | Envelope rate 2, Op-1 | OPS | Duration | Op-2 dial (decay-1) / Op-3 selected |
| 113 | Envelope rate 2, Op-1 | OPS | Duration | Op-2 dial (decay-1) / Op-4 selected |
| 114 | Envelope rate 2, Op-1 | OPS | Duration | Op-2 dial (decay-1) / Op-5 selected |
| 115 | Envelope rate 2, Op-1 | OPS | Duration | Op-2 dial (decay-1) / Op-6 selected |
| 116 | NOP | - | - | - |
| 117 | Envelope rate 3, Op-1 | OPS | Duration | Op-3 dial (decay-2) / Op-1 selected |
| 118 | Envelope rate 3, Op-1 | OPS | Duration | Op-3 dial (decay-2) / Op-2 selected |
| 119 | Envelope rate 3, Op-1 | OPS | Duration | Op-3 dial (decay-2) / Op-3 selected |
| 120 | Envelope rate 3, Op-1 | OPS | Duration | Op-3 dial (decay-2) / Op-4 selected |
| 121 | Envelope rate 3, Op-1 | OPS | Duration | Op-3 dial (decay-2) / Op-5 selected |
| 122 | Envelope rate 3, Op-1 | OPS | Duration | Op-3 dial (decay-2) / Op-6 selected |
| 123 | NOP | - | - | - |
| 124 | Envelope rate 4, Op-1 | OPS | Duration | Op-5 dial (release-1) / Op-1 selected |
| 125 | Envelope rate 4, Op-1 | OPS | Duration | Op-5 dial (release-1) / Op-2 selected |
| 126 | Envelope rate 4, Op-1 | OPS | Duration | Op-5 dial (release-1) / Op-3 selected |
| 127 | Envelope rate 4, Op-1 | OPS | Duration | Op-5 dial (release-1) / Op-4 selected |
| 128 | Envelope rate 4, Op-1 | OPS | Duration | Op-5 dial (release-1) / Op-5 selected |
| 129 | Envelope rate 4, Op-1 | OPS | Duration | Op-5 dial (release-1) / Op-6 selected |
| 130 | Pitch envelope level 1 | OSC | Level | Op-1 dial (attack) |
| 131 | Pitch envelope level 2 | OSC | Level | Op-2 dial (decay-1) |
| 132 | Pitch envelope level 3 | OSC | Level | Op-4 dial (sustain) |
| 133 | Pitch envelope level 4 | OSC | Level | Op-5 dial (release-1) |
| 134 | Pitch envelope rate 1 | OSC | Level | Op-1 dial (attack) |
| 135 | Pitch envelope rate 2 | OSC | Level | Op-2 dial (decay-1) |
| 136 | Pitch envelope rate 3 | OSC | Level | Op-4 dial (decay-2) |
| 137 | Pitch envelope rate 4 | OSC | Level | Op-5 dial (release-1) |
| 138 | Pitch envelope range | OSC | *Level* | Op-2 dial |
| 139 | Pitch envelope range velocity | OSC | *Level* | Op-4 dial |
| 140 | Envelope rate key, Op-1 | OPS | *Level* | Op-1 dial |
| 141 | Envelope rate key, Op-2 | OPS | *Level* | Op-2 dial |
| 142 | Envelope rate key, Op-3 | OPS | *Level* | Op-3 dial |
| 143 | Envelope rate key, Op-4 | OPS | *Level* | Op-4 dial |
| 144 | Envelope rate key, Op-5 | OPS | *Level* | Op-5 dial |
| 145 | Envelope rate key, Op-6 | OPS | *Level* | Op-6 dial |
| 146 | Pitch envelope rate key | OSC | *Level* | Output dial |
| 147 | NOP | - | - | - |
| 148 | NOP | - | - | - |
| 149 | LFO pitch depth | LFO | Volume | Op-5 dial |
| 150 | LFO amplitude depth | LFO | Volume | Op-6 dial |
| 151 | LFO speed | LFO | Volume | Op-2 dial |
| 152 | LFO sync | LFO | *Volume* | Op-3 dial |
| 153 | LFO wave | LFO | Volume | Op-1 dial |
| 154 | LFO fade | LFO | Volume | Op-4 dial |
| 155 | LFO pitch depth wheel | ? | ? | ? |
| 156 | LFO amp depth wheel | ? | ? | ? |
| 157 | LFO pitch depth aftertouch | ? | ? | ? |
| 158 | LFO amp depth aftertouch | ? | ? | ? |
| 159 | LFO amp sense, Op-1 | LFO | Level | Op-1 dial |
| 160 | LFO amp sense, Op-2 | LFO | Level | Op-2 dial |
| 161 | LFO amp sense, Op-3 | LFO | Level | Op-3 dial |
| 162 | LFO amp sense, Op-4 | LFO | Level | Op-4 dial |
| 163 | LFO amp sense, Op-5 | LFO | Level | Op-5 dial |
| 164 | LFO amp sense, Op-6 | LFO | Level | Op-6 dial |
| 165 | NOP | - | - | - |
| 166 | NOP | - | - | - |
| 167 | NOP | - | - | - |
| 168 | NOP | - | - | - |
| 169 | NOP | - | - | - |
| 170 | NOP | - | - | - |
| 171 | NOP | - | - | - |
| 172 | Bend range up | ? | ? | ? |
| 173 | Bend range down | ? | ? | ? |
| 174 | Transpose | Master | Volume | Op-2 dial |
| 175 | NOP | - | - | - |
| 176 | NOP | - | - | - |
| 177 | NOP | - | - | - |
| 178 | NOP | - | - | - |
| 179 | NOP | - | - | - |
| 180 | Volume | OSC | Volume | Output dial |
| 181 | Envelope level 0, Op-1 | OPS | Level | Output dial (delay) / Op-1 selected |
| 182 | Envelope level 0, Op-2 | OPS | Level | Output dial (delay) / Op-2 selected |
| 183 | Envelope level 0, Op-3 | OPS | Level | Output dial (delay) / Op-3 selected |
| 184 | Envelope level 0, Op-4 | OPS | Level | Output dial (delay) / Op-4 selected |
| 185 | Envelope level 0, Op-5 | OPS | Level | Output dial (delay) / Op-5 selected |
| 186 | Envelope level 0, Op-6 | OPS | Level | Output dial (delay) / Op-6 selected |
| 187 | Envelope rate 0, Op-1 | OPS | Duration | Output dial (delay) / Op-1 selected |
| 188 | Envelope rate 0, Op-2 | OPS | Duration | Output dial (delay) / Op-2 selected |
| 189 | Envelope rate 0, Op-3 | OPS | Duration | Output dial (delay) / Op-3 selected |
| 190 | Envelope rate 0, Op-4 | OPS | Duration | Output dial (delay) / Op-4 selected |
| 191 | Envelope rate 0, Op-5 | OPS | Duration | Output dial (delay) / Op-5 selected |
| 192 | Envelope rate 0, Op-6 | OPS | Duration | Output dial (delay) / Op-6 selected |
| 193 | Envelope level 5, Op-1 | OPS | Level | Op-6 dial (release-2) / Op-1 selected |
| 194 | Envelope level 5, Op-2 | OPS | Level | Op-6 dial (release-2) / Op-2 selected |
| 195 | Envelope level 5, Op-3 | OPS | Level | Op-6 dial (release-2) / Op-3 selected |
| 196 | Envelope level 5, Op-4 | OPS | Level | Op-6 dial (release-2) / Op-4 selected |
| 197 | Envelope level 5, Op-5 | OPS | Level | Op-6 dial (release-2) / Op-5 selected |
| 198 | Envelope level 5, Op-6 | OPS | Level | Op-6 dial (release-2) / Op-6 selected |
| 199 | Envelope rate 5, Op-1 | OPS | Duration | Op-6 dial (release-2) / Op-1 selected |
| 200 | Envelope rate 5, Op-2 | OPS | Duration | Op-6 dial (release-2) / Op-2 selected |
| 201 | Envelope rate 5, Op-3 | OPS | Duration | Op-6 dial (release-2) / Op-3 selected |
| 202 | Envelope rate 5, Op-4 | OPS | Duration | Op-6 dial (release-2) / Op-4 selected |
| 203 | Envelope rate 5, Op-5 | OPS | Duration | Op-6 dial (release-2) / Op-5 selected |
| 204 | Envelope rate 5, Op-6 | OPS | Duration | Op-6 dial (release-2) / Op-6 selected |
| 205 | Pitch envelope level 0 | OSC | Level | Output dial (delay) |
| 206 | Pitch envelope rate 0 | OSC | Duration | Output dial (delay) |
| 207 | Pitch envelope level 5 | OSC | Level | Op-6 dial (release-2) |
| 208 | Pitch envelope rate 5 | OSC | Duration | Op-6 dial (release-2) |
| 209 | LFO Pitch depth breath | ? | ? | ? |
| 210 | LFO Amp depth breath | ? | ? | ? |
| 211 | LFO Pitch depth foot | ? | ? | ? |
| 212 | LFO Amp depth foot | ? | ? | ? |
| 213 | Volume depth aftertouch | ? | ? | ? |
| 214 | Volume depth wheel | ? | ? | ? |
| 215 | Volume depth breath | ? | ? | ? |
| 216 | Volume depth foot | ? | ? | ? |
| 217 | Pitch depth aftertouch | ? | ? | ? |
| 218 | Pitch depth breath | ? | ? | ? |
| 219 | Pitch depth foot | ? | ? | ? |
| 220 | Pitch depth rnd | ? | ? | ? |
| 221 | Pan | Master | Volume | Op-1 dial |
| 222 | LFO pitch sense, Op-1 | LFO | Duration | Op-1 dial |
| 223 | LFO pitch sense, Op-2 | LFO | Duration | Op-2 dial |
| 224 | LFO pitch sense, Op-3 | LFO | Duration | Op-3 dial |
| 225 | LFO pitch sense, Op-4 | LFO | Duration | Op-4 dial |
| 226 | LFO pitch sense, Op-5 | LFO | Duration | Op-5 dial |
| 227 | LFO pitch sense, Op-6 | LFO | Duration | Op-6 dial |
| 228 | Legato (mono/poly) | Master | Volume | Op-3 dial |
| 229 | Portamento (glide) mode | Master | Volume | Op-5 dial |
| 230 | Portamento (glide) time | Master | Volume | Op-4 dial |
| 231 | NOP | - | - | - |
| 232 | NOP | - | - | - |
| 233 | NOP | - | - | - |
| 234 | NOP | - | - | - |
| 235 | NOP | - | - | - |
| 236 | Oscillator 1 wave, Op-1 | OSC | Volume | Op-1 dial |
| 237 | Oscillator 1 wave, Op-2 | OSC | Volume | Op-2 dial |
| 238 | Oscillator 1 wave, Op-3 | OSC | Volume | Op-3 dial |
| 239 | Oscillator 1 wave, Op-4 | OSC | Volume | Op-4 dial |
| 240 | Oscillator 1 wave, Op-5 | OSC | Volume | Op-5 dial |
| 241 | Oscillator 1 wave, Op-6 | OSC | Volume | Op-6 dial |
| 242 | Velocity offset | Master | Pitch/Feedback | Output dial |
| 243 | Velocity curve | - | - | - |
| 244 | Envelope loop | ? | ? | ? |
| 245 | Envelope loop segment | ? | ? | ? |
| 246 | Envelope restart | ? | ? | ? |
| 247 | NOP | - | - | - |
| 248 | NOP | - | - | - |
| 249 | NOP | - | - | - |
| 250 | NOP | - | - | - |
| 251 | Tuning | Master | Volume | Op-6 dial |
| 252 | Waveset | ? | ? | ? |
| 253 | NOP | - | - | - |
| 254 | NOP | - | - | - |
| 255 | NOP | - | - | - |
| 256 | Left level Op-1 | Master | *Duration/Level* | Op-1 dial |
| 257 | Right level, Op-1 | Master | *Duration/Level* | Op-1 dial |
| 258 | Left level, Op-2 | Master | *Duration/Level* | Op-2 dial |
| 259 | Right level, Op-2 | Master | *Duration/Level* | Op-2 dial |
| 260 | Left level Op-3 | Master | *Duration/Level* | Op-3 dial |
| 261 | Right level, Op-3 | Master | *Duration/Level* | Op-3 dial |
| 262 | Left level, Op-4 | Master | *Duration/Level* | Op-4 dial |
| 263 | Right level, Op-4 | Master | *Duration/Level* | Op-4 dial |
| 264 | Left level Op-5 | Master | *Duration/Level* | Op-5 dial |
| 265 | Right level, Op-5 | Master | *Duration/Level* | Op-5 dial |
| 266 | Left level, Op-6 | Master | *Duration/Level* | Op-6 dial |
| 267 | Right level, Op-6 | Master | *Duration/Level* | Op-6 dial |
| 268 | Oscillator 2 wave, Op-1 | OSC | Pitch | Op-1 dial |
| 269 | Oscillator 2 wave, Op-2 | OSC | Pitch | Op-2 dial |
| 270 | Oscillator 2 wave, Op-3 | OSC | Pitch | Op-3 dial |
| 271 | Oscillator 2 wave, Op-4 | OSC | Pitch | Op-4 dial |
| 272 | Oscillator 2 wave, Op-5 | OSC | Pitch | Op-5 dial |
| 273 | Oscillator 2 wave, Op-6 | OSC | Pitch | Op-6 dial |
| 274 | Oscillator wave mode , Op-1 | OSC | *Ratio* | Op-1 dial |
| 275 | Oscillator wave mode , Op-2 | OSC | *Ratio* | Op-2 dial |
| 276 | Oscillator wave mode , Op-3 | OSC | *Ratio* | Op-3 dial |
| 277 | Oscillator wave mode , Op-4 | OSC | *Ratio* | Op-4 dial |
| 278 | Oscillator wave mode , Op-5 | OSC | *Ratio* | Op-5 dial |
| 279 | Oscillator wave mode , Op-6 | OSC | *Ratio* | Op-6 dial |
| 280 | Oscillator wave ratio , Op-1 | OSC | *Ratio* | Op-1 dial |
| 281 | Oscillator wave ratio , Op-2 | OSC | *Ratio* | Op-2 dial |
| 282 | Oscillator wave ratio , Op-3 | OSC | *Ratio* | Op-3 dial |
| 283 | Oscillator wave ratio , Op-4 | OSC | *Ratio* | Op-4 dial |
| 284 | Oscillator wave ratio , Op-5 | OSC | *Ratio* | Op-5 dial |
| 285 | Oscillator wave ratio , Op-6 | OSC | *Ratio* | Op-6 dial |
| 286 | Oscillator phase , Op-1 | OSC | *Feedback* | Op-1 dial |
| 287 | Oscillator phase , Op-2 | OSC | *Feedback* | Op-2 dial |
| 288 | Oscillator phase , Op-3 | OSC | *Feedback* | Op-3 dial |
| 289 | Oscillator phase , Op-4 | OSC | *Feedback* | Op-4 dial |
| 290 | Oscillator phase , Op-5 | OSC | *Feedback* | Op-5 dial |
| 291 | Oscillator phase , Op-6 | OSC | *Feedback* | Op-6 dial |
| 292 | NOP | - | - | - |
| 293 | NOP | - | - | - |
| 294 | NOP | - | - | - |
| 295 | NOP | - | - | - |
| 296 | NOP | - | - | - |
| 297 | NOP | - | - | - |
| 298 | NOP | - | - | - |
| 299 | NOP | - | - | - |
| 300 | EFX Delay dry | EFX | Delay | Output dial |
| 301 | EFX Delay wet | EFX | Delay | Op-6 dial |
| 302 | EFX Delay mode | EFX | Delay | Op-5 dial |
| 303 | EFX Delay time | EFX | Delay | *Op-2 dial*|
| 304 | EFX Delay feedback | EFX | Delay | Op-3 dial |
| 305 | EFX Delay feedback lo filter | EFX | Delay | Op-4 dial |
| 306 | EFX Delay feedback hi filter | EFX | Delay | Op-4 dial |
| 307 | EFX Delay tempo | EFX | Delay | *Op-2 dial* |
| 308 | EFX Delay num | EFX | Delay | *Op-1 dial* |
| 309 | EFX Delay den | EFX | Delay | *Op-1 dial* |
| 310 | EFX Phaser dry | EFX | Phaser | Output dial |
| 311 | EFX Phaser wet | EFX | Phaser | Op-6 dial |
| 312 | EFX Phaser mode | EFX | Phaser | *Op-5 dial* |
| 313 | EFX Phaser depth | EFX | Phaser | Op-4 dial |
| 314 | EFX Phaser speed | EFX | Phaser | Op-2 dial |
| 315 | EFX Phaser feedback | EFX | Phaser | Op-3 dial |
| 316 | EFX Phaser offset | EFX | Phaser | *Op-1 dial* |
| 317 | EFX Phaser stages | EFX | Phaser | *Op-5 dial* |
| 318 | EFX Phaser phase | EFX | Phaser | *Op-1 dial* |
| 319 | EFX Phaser waveform | EFX | Phaser | - |
| 320 | EFX Filter low pass | EFX | EFX | Op-5 dial |
| 321 | EFX Filter high pass | EFX | EFX | Op-4 dial |
| 322 | NOP | - | - | - |
| 323 | NOP | - | - | - |
| 324 | NOP | - | - | - |
| 325 | NOP | - | - | - |
| 326 | NOP | - | - | - |
| 327 | NOP | - | - | - |
| 328 | NOP | - | - | - |
| 329 | NOP | - | - | - |
| 330 | EFX AM speed | EFX | AM | Op-2 dial |
| 331 | EFX AM range | EFX | AM | Op-4 dial |
| 332 | EFX AM depth | EFX | AM | Op-6 dial |
| 333 | EFX AM phase | EFX | AM | Op-1 dial |
| 334 | NOP | - | - | - |
| 335 | NOP | - | - | - |
| 336 | NOP | - | - | - |
| 337 | NOP | - | - | - |
| 338 | NOP | - | - | - |
| 339 | NOP | - | - | - |
| 340 | EFX FIR Impulse | - | - | - |
| 341 | NOP | - | - | - |
| 342 | NOP | - | - | - |
| 343 | NOP | - | - | - |
| 344 | NOP | - | - | - |
| 345 | NOP | - | - | - |
| 346 | NOP | - | - | - |
| 347 | NOP | - | - | - |
| 348 | NOP | - | - | - |
| 349 | NOP | - | - | - |
| 350 | EFX Waveshaper dry | - | - | - |
| 351 | EFX Waveshaper wet | - | - | - |
| 352 | EFX Waveshaper gain pre | - | - | - |
| 353 | EFX Waveshaper gain post | - | - | - |
| 354 | EFX Waveshaper shape | - | - | - |
| 355 | NOP | - | - | - |
| 356 | NOP | - | - | - |
| 357 | NOP | - | - | - |
| 358 | NOP | - | - | - |
| 359 | NOP | - | - | - |
| 360 | EFX Chorus dry | EFX | Chorus | Output dial |
| 361 | EFX Chorus wet | EFX | Chorus | Op-6 dial |
| 362 | EFX Chorus mode | EFX | Chorus | Op-5 dial |
| 363 | EFX Chorus speed | EFX | Chorus | Op-2 dial |
| 364 | EFX Chorus depth | EFX | Chorus | Op-4 dial |
| 365 | EFX Chorus feedback | EFX | Chorus | Op-3 dial |
| 366 | EFX Chorus phase | EFX | Chorus | Op-1 dial |
| 367 | NOP | - | - | - |
| 368 | NOP | - | - | - |
| 369 | NOP | - | - | - |
| 370 | EFX Decimator depth | EFX | EFX | Op-3 dial |
| 371 | NOP | - | - | - |
| 372 | NOP | - | - | - |
| 373 | NOP | - | - | - |
| 374 | NOP | - | - | - |
| 375 | NOP | - | - | - |
| 376 | NOP | - | - | - |
| 377 | NOP | - | - | - |
| 378 | NOP | - | - | - |
| 379 | NOP | - | - | - |
| 380 | EFX Bitcrusher depth | EFX | EFX | Op-2 dial |
| 381 | NOP | - | - | - |
| 382 | NOP | - | - | - |
| 383 | NOP | - | - | - |
| 384 | NOP | - | - | - |
| 385 | NOP | - | - | - |
| 386 | NOP | - | - | - |
| 387 | NOP | - | - | - |
| 388 | NOP | - | - | - |
| 389 | NOP | - | - | - |
| 390 | EFX Reverb dry | EFX | Reverb | Output dial |
| 391 | EFX Reverb wet | EFX | Reverb | Op-6 dial |
| 392 | EFX Reverb mode | EFX | Reverb | Op-5 dial |
| 393 | EFX Reverb decay | EFX | Reverb | Op-2 dial |
| 394 | EFX Reverb damp | EFX | Reverb | Op-4 dial |
| 395 | EFX Reverb D0 | EFX | Reverb | - |
| 396 | EFX Reverb D1 | EFX | Reverb | - |
| 397 | EFX Reverb D2 | EFX | Reverb | - |
| 398 | NOP | - | - | - |
| 399 | NOP | - | - | - |
| 400 | NOP | - | - | - |
| 401 | NOP | - | - | - |
| 402 | NOP | - | - | - |
| 403 | NOP | - | - | - |
| 404 | NOP | - | - | - |
| 405 | NOP | - | - | - |
| 406 | NOP | - | - | - |
| 407 | NOP | - | - | - |
| 408 | NOP | - | - | - |
| 409 | NOP | - | - | - |
| 410 | EFX Routing | EFX | EFX | Op-6 dial |
| 411 | Output level | Master | Volume | *Output dial* |
| 412 | Gain | Master | Volume | *Output dial* |
| 413 | NOP | - | - | - |
| 414 | NOP | - | - | - |
| 415 | NOP | - | - | - |
| 416 | NOP | - | - | - |
| 417 | NOP | - | - | - |
| 418 | NOP | - | - | - |
| 419 | NOP | - | - | - |
| 420 | Control 1 max | ? | ? | ? |
| 421 | Control 1 min | ? | ? | ? |
| 422 | Control 2 max | ? | ? | ? |
| 423 | Control 2 min | ? | ? | ? |
| 424 | Control 3 max | ? | ? | ? |
| 425 | Control 3 min | ? | ? | ? |
| 426 | Control 4 max | ? | ? | ? |
| 427 | Control 4 min | ? | ? | ? |
| 428 | NOP | - | - | - |
| 429 | NOP | - | - | - |
| 430 | NOP | - | - | - |
| 431 | NOP | - | - | - |
| 432 | NOP | - | - | - |
| 433 | NOP | - | - | - |
| 434 | NOP | - | - | - |
| 435 | NOP | - | - | - |
| 436 | NOP | - | - | - |
| 437 | NOP | - | - | - |
| 438 | NOP | - | - | - |
| 439 | NOP | - | - | - |
| 440 | NOP | - | - | - |
| 441 | NOP | - | - | - |
| 442 | NOP | - | - | - |
| 443 | NOP | - | - | - |
| 444 | NOP | - | - | - |
| 445 | NOP | - | - | - |
| 446 | NOP | - | - | - |
| 447 | NOP | - | - | - |
| 448 | NOP | - | - | - |
| 449 | NOP | - | - | - |
| 450 | Arp mode | ? | ? | ? |
| 451 | Arp tempo | ? | ? | ? |
| 452 | Arp tempo fine | ? | ? | ? |
| 453 | Arp division | ? | ? | ? |
| 454 | Arp octaves | ? | ? | ? |
| 455+ | NOP | - | - | - |

Parameters 455-511 are not in use.

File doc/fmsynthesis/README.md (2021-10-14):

# FM Synthesis explained

## Sources

- https://www.futur3soundz.com/wavetable-synthesis
- https://en.wikipedia.org/wiki/Frequency_modulation_synthesis
- http://www.soundonsound.com/sos/apr00/articles/synthsecrets.htm
- https://www.soundonsound.com/techniques/more-frequency-modulation
- http://ccrma.stanford.edu/software/snd/snd/fm.html
- https://homepages.abdn.ac.uk/d.j.benson/pages/html/music.pdf

## Theory - simple FM (one carrier, one modulator)

Let:
- Fc: the frequency of the carrier
- Fm: the frequency of the modulator
- C: The frequency-ratio of the carrier (we will only use a value of C=1)
- M: The frequency-ratio of the modulator
- I: The modulation index

The "side band order" k=0,1,2,3,..

To compute the actual frequency spectrum, we need to consider the sidebands from the original carrier frequency Fc. The 0th order sideband is the frequency Fc. Sideband orders range from k=0,1,2,3,.. Both left sidebands (frequencies to the left of the carrier frequency) and right sidebands (frequencies to the right of the carrier frequency) occur. The actual frequencies of such a sideband is related to the modulation frequency: Fc ± k*Fm

You only need to calculate the I+2 order sideband, all other sidebands will have negligible amplitudes.

The amplitude of a particular order sideband k is calculated using the Bessel function of the same order k of the modulation index:

Amplitude = BesselJ(k,I)

A sideband corresponds to a frequency, so we get the amplitude for that frequency. But we have some things to consider:
- Sideband at frequency 0 is actually a DC offset, so if such a sideband would occur we can ignore this sideband. This frequency only occurs for M = C / r, with r = 1,2,3,... For M>=C this only occurs at M = C.
- Bessel functions with order above 3 can have negative results, so the calculated amplitude is actually negative.
- Odd sidebands at negative frequency have a phase shift of 180 degrees, so as these sidebands are sinoid curves, this phase shift can also be represented by switching the amplitude sign, mainting the same phase as all other sidebands: negative amplitudes become positive, positive amplitudes become negative.
- Sidebands at negative frequencies are actually sidebands at the same positive frequency, but with another phase shift of 180 degrees: another sign switch.

[This excel spreadsheet](fmsynthesis.xlsx) calculates the correct sideband frequencies and amplitudes for a give carrier frequency, modulation ratio and modulation index (for modulation ratio >= 1).

For better understanding of the frequency of the sideband, it is more intuitive to depict them as a ratio of the carrier frequency: R1=Fc, the carrier frequency, R2 = 2*Fc, etc.

| M | Frequencies | First 8 frequency ratios |
|---|---|---|
| 1 | Fc(1 ± k) | 1,2,3,4,5,6,7,8 |
| 2 | Fc(1 ± 2k) | 1,3,5,7,9,11,13 |
| 3 | Fc(1 ± 3k) | 1,2,4,5,7,8,10,11 |
| 4 | Fc(1 ± 4k) | 1,3,5,7,9,11,13 |
| 5 | Fc(1 ± 5k) | 1,4,6,9,11,14,16,19 |
| 6 | Fc(1 ± 6k) | 1,5,7,11,13,17,19,23 |
| 7 | Fc(1 ± 7k) | 1,6,8,13,15,20,22,27 |
| 8 | Fc(1 ± 8k) | 1,7,9,15,17,23,25,31 |

Observe that we have already "mirrored" the negative frequencies to positive frequencies, resulting in extra frequency ratios if M is odd and larger than 1.

Some observations:
- Only M=1 will give us all harmonic frequency components
- When M has an even value, only odd harmonic frequency components are available
- M=2 and M=4 have the same possible frequency components (all odd ratio's)
- Higher values of M (from M=4) won't have frequency components between 2 and M-1

### Some observations how M and I change the timbre of the sound

- I = 0 disables the modulation completely (as expected), so M doesn't matter;
- The larger I, the more sidebands have relevant amplitudes
- M = 1 will have all harmonic frequency components (1,2,3,..)
- The larger M, the greater the gap between frequency components (for example: M=2 will only have odd harmonic frequency components: 1,3,5,7)
- The larger M, the higher the frequency with the last relevant amplitude.

This means that we have two ways of obtaining a "higher" tembre:
- Increasing I (more sidebands, so the last relevant one will have a higher frequency);
- Increasing M (larger gap between sideband frequencies, so the last relevant one will have a higher frequency).

### Frequency spectrum analysis

A pure wave (for example 440 Hz) can be displayed in the time domain as a sinoid wave. The same wave can also be displayed in the frequency domain: plotting the frequency bands at which (in)harmonic overtones of the root frequency are displayed. In the examples below both the frequency domain graph and the time domain graphs are displayed.

In FM, the frequency domain graph can be calculated using Bessel functions, as described above. But you can also "calculate" the frequency domain graph from the time domain graph using Fourier transforms. Using Fourier transforms, you could actually "analyse" any available sound and using the results, calculate the appropriate values for carriers and modulators as described in [this article](http://www.javelinart.com/FM_Synthesis_of_Real_Instruments.pdf).

The Matlab script [fourier.m](fourier.m) will create a frequency domain graph from any FM created sound wave with one carrier and one modulator. It also contains the calculation of sideband frequencies and amplitudes, so you can compare the two different ways to achieve the same result. You can use the open source tool GNU Octave (https://octave.org) to execute this script.

## Examples

### Sawtooth-like (M=1, I=1.3)
Fc = 440, Fm = 440, C = 1, M = 1, I = 1.3

`y = sin(x + 1.3 * sin(x))` ([show math](https://www.wolframalpha.com/input/?i=y%3Dsin%28x%2B1.3*sin%28x%29%29))

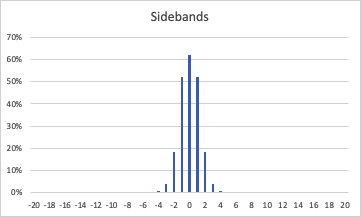
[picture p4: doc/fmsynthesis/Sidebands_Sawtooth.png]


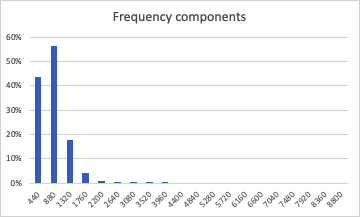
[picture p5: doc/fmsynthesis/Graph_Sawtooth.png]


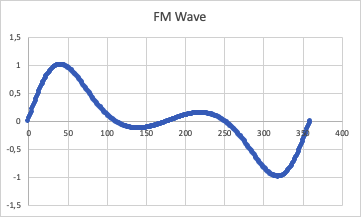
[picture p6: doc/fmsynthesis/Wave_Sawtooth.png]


### Square-like (M=2, I=1,3)
Fc = 440, Fm = 440, C = 1, M = 1, I = 1,3

`y = sin(x + 1.3 * sin(2x))` ([show math](https://www.wolframalpha.com/input/?i=y%3Dsin%28x%2B1.3*sin%282x%29%29))

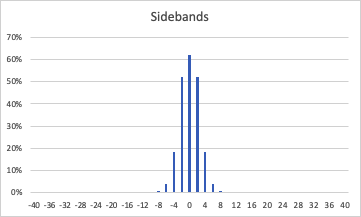
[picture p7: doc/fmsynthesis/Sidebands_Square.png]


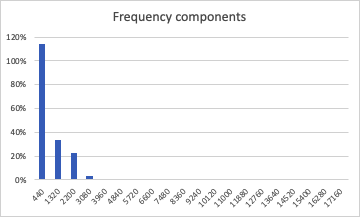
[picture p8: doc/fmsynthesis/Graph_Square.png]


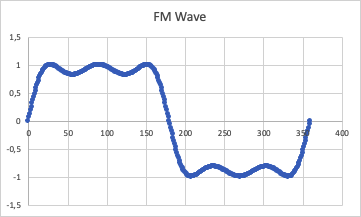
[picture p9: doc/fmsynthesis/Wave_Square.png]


### M=1, I=0 (no modulation)
Fc = 440, Fm = 440, C = 1, M = 1, I = 0

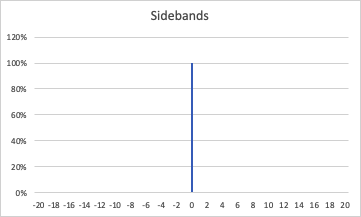
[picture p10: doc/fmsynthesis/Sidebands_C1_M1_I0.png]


No sidebands, because I=0

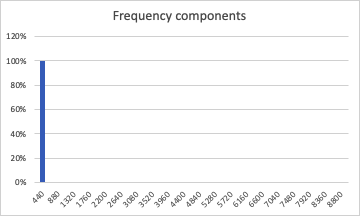
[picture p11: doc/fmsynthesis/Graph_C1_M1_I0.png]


Because I=0, the modulation ratio doesn't matter: only one frequency component at R1 with amplitude 100%.

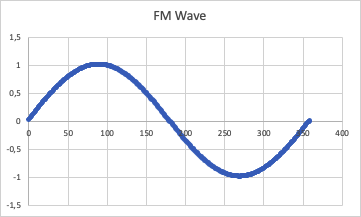
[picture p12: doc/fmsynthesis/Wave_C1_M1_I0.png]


### M=1, I=1
Fc = 440, Fm = 440, C = 1, M = 1, I = 1

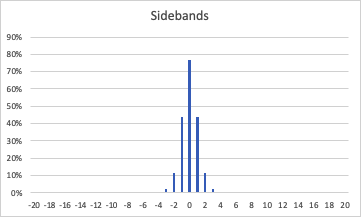
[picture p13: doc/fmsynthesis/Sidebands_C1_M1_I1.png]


Sidebands at 0, ±1, ±2, ±3, ...

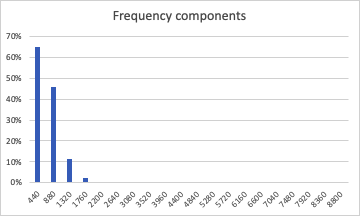
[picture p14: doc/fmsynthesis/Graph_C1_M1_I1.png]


Frequency components with amplitude larger than 10% at R1, R2 and R3 (440,880,1320)

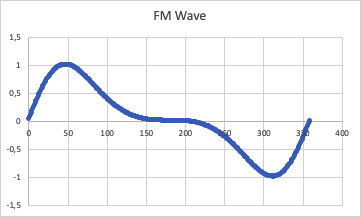
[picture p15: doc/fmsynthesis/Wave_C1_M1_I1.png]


### M=1, I=2

Fc = 440, Fm = 440, C = 1, M = 1, I = 2

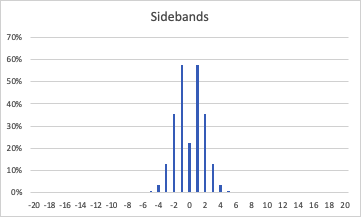
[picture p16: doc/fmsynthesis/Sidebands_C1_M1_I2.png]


Sidebands at 0, ±1, ±2, ±3, ...

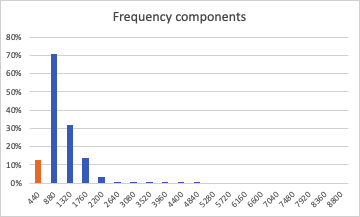
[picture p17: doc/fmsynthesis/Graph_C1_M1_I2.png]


Frequency components with amplitude larger than 10% at R1, R2, R3, R4 (440,880,1320,1760). The frequency component at R1 is depicted in orange: it has a negative amplitude (phase shifted 180 degrees).

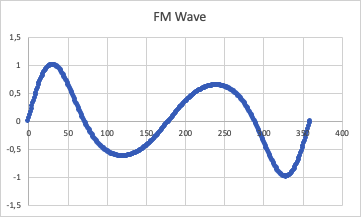
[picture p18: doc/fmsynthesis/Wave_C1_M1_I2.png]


### M=1, I=5

Fc = 440, Fm = 440, C = 1, M = 1, I = 5

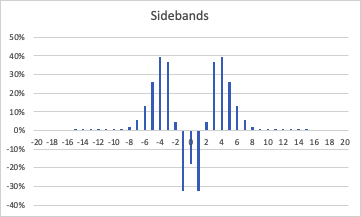
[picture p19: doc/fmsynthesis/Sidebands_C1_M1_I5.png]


Sidebands at 0, ±1, ±2, ±3, ...

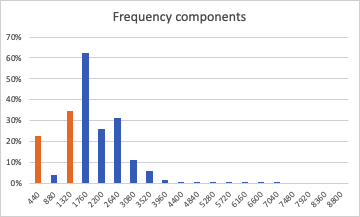
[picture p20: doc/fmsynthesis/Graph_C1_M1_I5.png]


Frequency components with amplitude larger than 10% at R1, R3, R4, R5, R6, R7 (440,1320,1760,2200,2640,3080)

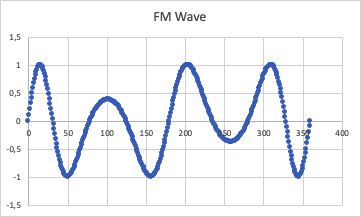
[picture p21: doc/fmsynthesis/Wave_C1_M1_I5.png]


### M=2, I=1
Fc = 440, Fm = 880, C = 1, M = 2, I = 1

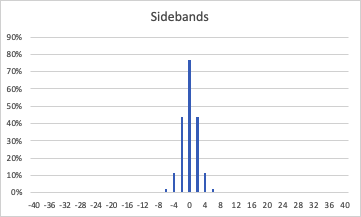
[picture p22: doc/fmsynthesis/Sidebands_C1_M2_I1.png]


Sidebands at 0, ±2, ±4, ±6, ...

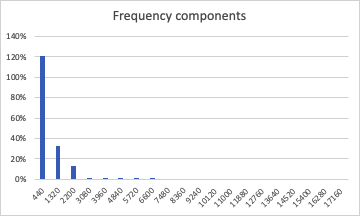
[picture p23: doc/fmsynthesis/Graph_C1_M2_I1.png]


Frequency components with amplitude larger than 10% at R1, R3 (440,1320)

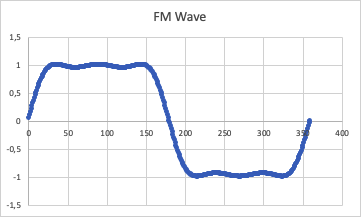
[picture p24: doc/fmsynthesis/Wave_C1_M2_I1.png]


### M=2, I=2
Fc = 440, Fm = 880, C = 1, M = 2, I = 2

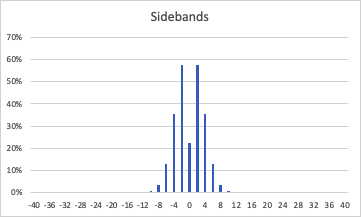
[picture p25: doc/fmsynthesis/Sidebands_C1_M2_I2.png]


Sidebands at 0, ±2, ±4, ±6, ...



Frequency components with amplitude larger than 10% at R1, R3, R5, R7 (440,1320,2200,3080)



### M=2, I=5
Fc = 440, Fm = 880, C = 1, M = 2, I = 5



Sidebands at 0, ±2, ±4, ±6, ...



Frequency components with amplitude larger than 10% at R1, R3, R5, R9,R11,R13 (440,1320,2200,3960,4840,5720)



### M=3, I=1
Fc = 440, Fm = 1320, C = 1, M = 3, I = 1



Sidebands at 0, ±3, ±6, ±9, ...



Frequency components with amplitude larger than 10% at R1,R2,R3,R4,R5 (440,880,1760,2200,3080)



### M=3, I=2
Fc = 440, Fm = 1320, C = 1, M = 3, I = 2



Sidebands at 0, ±3, ±6, ±9, ...



Frequency components with amplitude larger than 10% at R1, R2, R4 (440,880,1760,2200,3080,4400)



### M=3, I=5
Fc = 440, Fm = 1320, C = 1, M = 3, I = 5



Sidebands at 0, ±3, ±6, ±9, ...



Frequency components with amplitude larger than 10% at R1, R2, R4, R5, R7 (440, 880, 1760, 2200, 3080)



## Theory - feedback FM

Feedback FM is actually easier to calculate than "simple" FM:

- Only positive sidebands will occur: k = 1,2,3,..
- The amplitude is calculated using the formula: Amplitude = 2 * BesselJ(k,I * k) / (I * k)
- This function won't work for I = 0 (division by zero), but interestingly, the whole function resolved to 0 for k>1 and to 1 for k=1 (as you would expect: just a regular sinoid wave at feedback level zero).

[This excel spreadsheet](fmfeedback.xlsx) calculates the correct sideband frequencies and amplitudes for a give carrier frequency and modulation index (=feedback ratio), for modulation index < 1.3).

Some interesting things can be said about this spreadsheet:
- Because only the first 20 sidebands are calculated, the calculated wave from the sidebands is a bit "blocky" with respect to the real calculated FM wave. With feedback: higher level sideband DO realy add up!
- From around modulation index 1.3, negative frequencies occur at the highest feedback levels. This introduces noise in the calculated FM wave, but not in the sidebands: they still add up nicely (although resulting in a wave with an increasingly lower amplitude).

## Examples

Only the frequency components graph is displayed, the sidebands are always the same as the frequency components.

### I = 0.5
Fc = 440, C = 1, I = 0.5

`y = sin(x + 0.5 * sin(y))` ([show math](https://www.wolframalpha.com/input/?i=y+%3D+sin%28x+%2B+0.5+*+sin%28y%29%29))





### I = 1.0





### I = 1.2





### I = 1.4





The wave above is from the excel and only shows the calculated spots, not a line. The burst of noise is actually the oscillator going very rapidly going between two extreme values, that's why two separate lines are visible. Using Octave, we can plot a graph that depicts a little bit better what is going on (see [feedback.m](feedback.m) for the script).



The summed wave from the calculated sideband amplitudes look very well-behaved, but is probably very wrong (not resembling the sound that is actually heard).



The noise burst is the result of the sampling rate of digital synthesizers. It is the reason that Yamaha originally used an averaging filter for the feedback, using not only the previous value, but actually the average between the previous two values, which will make the noise burst disappear. The explanation is mentioned in [this patent](https://patents.google.com/patent/US4249447A/en), as is visible in the graph below, using the same parameters, but with the average filter (see [feedback-filter.m](feedback-filter.m) for the script).



Interestingly the "pure" math equation results in a graph that is actually "not possible" from a sound perspective (it goes "back in time"):

`y = sin(x + 1.4 * sin(y))` ([show math](https://www.wolframalpha.com/input/?i=y+%3D+sin%28x+%2B+1.4+*+sin%28y%29%29))

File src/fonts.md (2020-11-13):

# Fonts

De Adafruit library geeft de mogelijkheid om nieuwe fonts toe te voegen:

https://learn.adafruit.com/adafruit-gfx-graphics-library/using-fonts

Om deze te gebruiken moet je eerst de git repo van Adafruit GFX ophalen:

```
git clone git@github.com:adafruit/Adafruit-GFX-Library.git
```

Vervolgens ga je naar de `fontconvert` map en compileer je de code:

```
make
```

Tenslotte zorg je er voor dat de executable `fontconvert` en het truetype bestand in dezelfde directory staan, en kies je:

```
fontconvert myfont.ttf 12 > myfont12pt7b.h
```

Dit zorgt voor een bitmap font ter grootte van 12pt, vergelijkbaar kun je ook kleinere en grotere bitmaps maken.

Voor de synth fonts gebruiken we het volgende font: http://www.fonts101.com/fonts/view/Graffiti/56682/Dungeon

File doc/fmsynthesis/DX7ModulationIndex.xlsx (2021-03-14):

Param | Index |  | TL | Param | Chowning | Calculated | Difference
0 | 0.0002 | 0.0002183599859 | 127 | 10 | 0.003 | 0.003203791839 | 6.79%
1 | 0.0003 | 0.0003367571341 | 122 | 20 | 0.013 | 0.0139750391 | 7.50%
2 | 0.0005 | 0.0004762465063 | 118 | 30 | 0.031 | 0.03323843185 | 7.22%
3 | 0.0007 | 0.0006735142682 | 114 | 40 | 0.079 | 0.07905475931 | 0.07%
4 | 0.001 | 0.0009524930125 | 110 | 50 | 0.188 | 0.1880249645 | 0.01%
5 | 0.0012 | 0.001235230614 | 107 | 60 | 0.446 | 0.4472012511 | 0.27%
6 | 0.0016 | 0.00160189592 | 104 | 65 | 0.69 | 0.6896786106 | 0.05%
7 | 0.0019 | 0.001904986025 | 102 | 70 | 1.068 | 1.063629819 | 0.41%
8 | 0.0023 | 0.002265422935 | 100 | 75 | 1.639 | 1.640341422 | 0.08%
9 | 0.0027 | 0.002694057073 | 98 | 80 | 2.512 | 2.529752298 | 0.71%
10 | 0.0032 | 0.003203791839 | 96 | 85 | 3.894 | 3.901411379 | 0.19%
11 | 0.0038 | 0.00380997205 | 94 | 90 | 6.029 | 6.016798863 | 0.20%
12 | 0.0045 | 0.00453084587 | 92 | 95 | 9.263 | 9.279172341 | 0.17%
13 | 0.0054 | 0.005388114145 | 90 | 99 | 13.119 | 13.12273137 | 0.03%
14 | 0.0064 | 0.006407583678 | 88
15 | 0.0076 | 0.0076199441 | 86
16 | 0.0083 | 0.008309607964 | 85
17 | 0.0091 | 0.00906169174 | 84
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

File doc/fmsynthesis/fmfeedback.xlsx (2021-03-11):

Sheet: Blad1
 | Frequency | Ratio
Carrier | 440 | 1
Feedback | 1
Position | Frequency | Ratio | Amplitude | Pos | Neg
1 | 440 | 1 | 88.01011714% | 88.01011714% | 0%
2 | 880 | 2 | 35.28342075% | 35.28342075% | 0%
3 | 1320 | 3 | 20.60419098% | 20.60419098% | 0%
4 | 1760 | 4 | 14.05645332% | 14.05645332% | 0%
5 | 2200 | 5 | 10.44562188% | 10.44562188% | 0%
6 | 2640 | 6 | 8.194562128% | 8.194562128% | 0%
7 | 3080 | 7 | 6.673816278% | 6.673816278% | 0%
8 | 3520 | 8 | 5.586374662% | 5.586374662% | 0%
9 | 3960 | 9 | 4.775124058% | 4.775124058% | 0%
10 | 4400 | 10 | 4.149722133% | 4.149722133% | 0%
11 | 4840 | 11 | 3.65480018% | 3.65480018% | 0%
12 | 5280 | 12 | 3.254669712% | 3.254669712% | 0%
13 | 5720 | 13 | 2.925367324% | 2.925367324% | 0%
14 | 6160 | 14 | 2.650248478% | 2.650248478% | 0%
15 | 6600 | 15 | 2.417417887% | 2.417417887% | 0%
16 | 7040 | 16 | 2.218164919% | 2.218164919% | 0%
17 | 7480 | 17 | 2.045975419% | 2.045975419% | 0%
18 | 7920 | 18 | 1.89588759% | 1.89588759% | 0%
19 | 8360 | 19 | 1.764060459% | 1.764060459% | 0%
20 | 8800 | 20 | 1.647477738% | 1.647477738% | 0%
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

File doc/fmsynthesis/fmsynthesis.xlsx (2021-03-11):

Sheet: Blad1
 | Frequency | Ratio
Carrier | 440 | 1
Modulator | 1320 | 3
Modulation index | 2
Position | Frequency | Ratio | Amplitude | Pos | Neg
1 | 440 | 1 | 22.38907819% | 22.38907819% | 0%
2 | 880 | 2 | 57.67248079% | 57.67248079% | 0%
3 | 1760 | 4 | 57.67248079% | 57.67248079% | 0%
4 | 2200 | 5 | -35.28342075% | 0% | 35.28342075%
5 | 3080 | 7 | 35.28342075% | 35.28342075% | 0%
6 | 3520 | 8 | 12.894325% | 12.894325% | 0%
7 | 4400 | 10 | 12.894325% | 12.894325% | 0%
8 | 4840 | 11 | -3.399571981% | 0% | 3.399571981%
9 | 5720 | 13 | 3.399571981% | 3.399571981% | 0%
10 | 6160 | 14 | 0.7039629756% | 0.7039629756% | 0%
11 | 7040 | 16 | 0.7039629756% | 0.7039629756% | 0%
12 | 7480 | 17 | -0.1202428972% | 0% | 0.1202428972%
13 | 8360 | 19 | 0.1202428972% | 0.1202428972% | 0%
14 | 8800 | 20 | 0.01749440749% | 0.01749440749% | 0%
15 | 9680 | 22 | 0.01749440749% | 0.01749440749% | 0%
16 | 10120 | 23 | 0% | 0% | 0%
17 | 11000 | 25 | 0.002217955229% | 0.002217955229% | 0%
18 | 11440 | 26 | 0% | 0% | 0%
19 | 12320 | 28 | 0.0002492343435% | 0.0002492343435% | 0%
20 | 12760 | 29 | 0% | 0% | 0%
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

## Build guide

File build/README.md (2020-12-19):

# fm-synth
An FM synth based on XFM2 (sounds) and Teensy (operation)

Goal of this project:
- Use an XFM2 for sound creation
- Interact via serial communication between the XFM2 and a teensy (4.0)
- Use the Teensy to drive seven OLED displays for displaying all information about the synthesizer
- Use the Teensy to monitor 9 rotary encoders (that also include a push button)
- Use the Teensy to drive a lot of LED's (42 in total)
- Use the Teensy to monitor a lot of push buttons (also 42)

We use a lot of multiplexer to get this done:
- A TCA9548A to multiplex the different OLED displays (all displays use 3C as I2C address...)
- A MAX7219CNG to drive a max total of 42 LED's
- A 74HCT125 to levelshift between the Teensy and the LED driver
- Two MCP23017 to monitor the rotary encoders (2 ports for the encoder, 1 port for the button). These MCP23017 will create an interupt after which you can read the level of a particular encoder

## Individual parts

- [Power PCB](power-source.md)
  - 5x7 PCB
- [Teensy PCB](teensy-pcb.md)
  - 5x7 PCB
- [XFM2 and DAC](XFM2.md)
  - 6x8 PCB
- [TCA9548A and OLEDs](TCA9548A-OLEDs.md)
  - 5x7 PCB
  - 6x8 PCB
- [MCP23017s](MCP23017s.md)
  - 5x7 PCB
- [LED Panels](LED-panels.md)
  - 15x9 PCB
    - Panel 1 (12x5)
    - Panel 2 (10x2.2)
  - 15x9 PCB
    - Panel 3 (12x2.2)
    - Panel 4 (10x4)
  - 7x9 PCB
    - Panel 5 (6x5.5)
  - 15x9 PCB
    - Panel 6 (10x6.1)

Total PCB count:
- 4x PCB 5x7
- 2x PCB 6x8
- 1x PCB 7x9
- 3x PCB 15x9

## Overview

The diagram below depicts all components. Power is supplied by a regulator, delivering 5V to the LED driver and 4.7V to the Teensy and XFM2. This way, the USB can still be used to power the Teensy OR the XFM2 if we need to maintain the program on one of these MCU's. Normally, we don't use the USB ports...

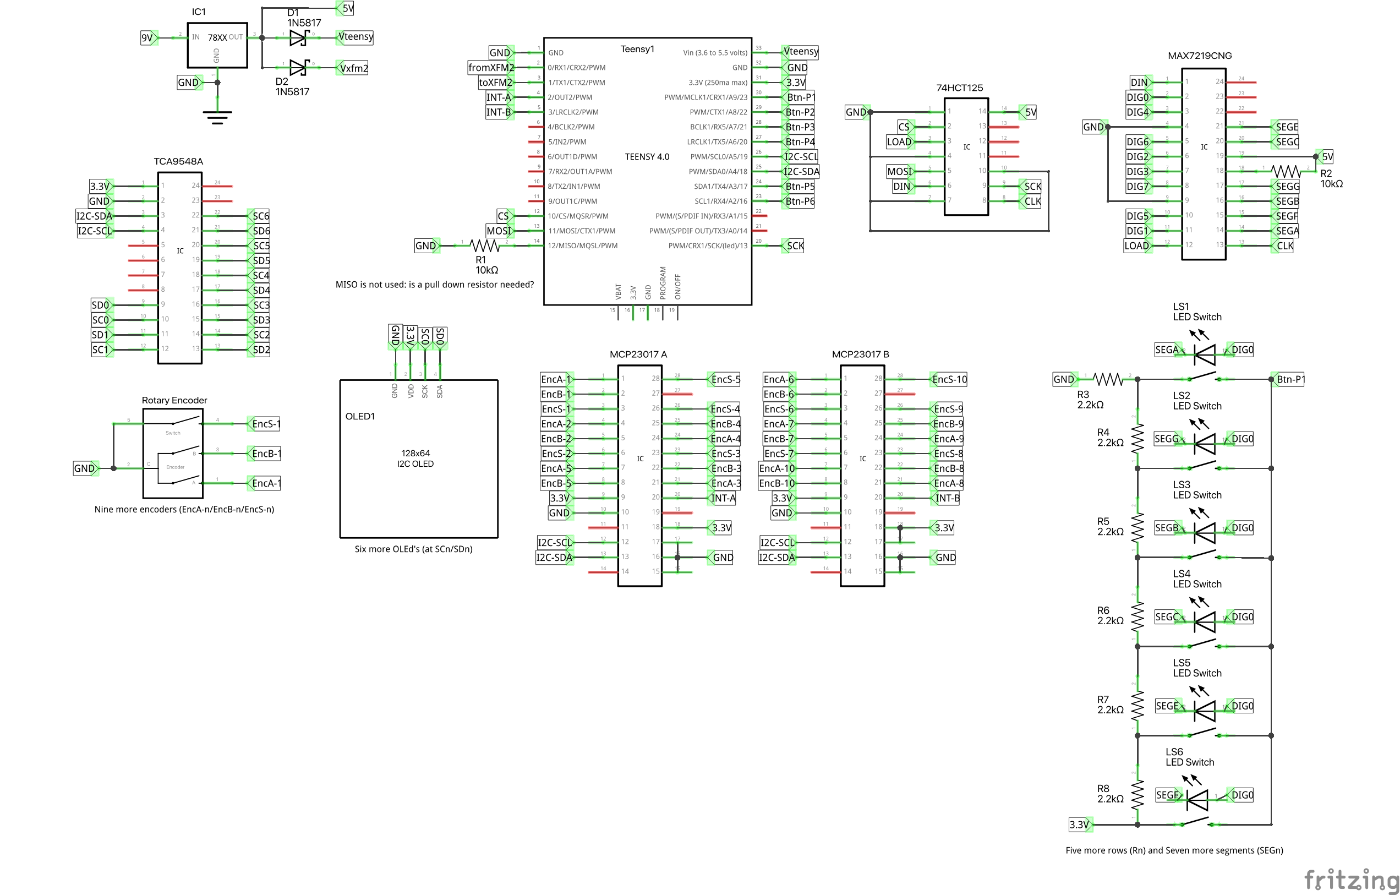
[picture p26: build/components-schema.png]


The main IC's are distributed over three separate PCB's:
- Power
- Teensy
- XFM2

The TCA9548A is directly fixed to front panel, as are the zeven OLED screens. The screens, TCA9548A and Teensy are connected using a special-made jumper cable, displayed below:

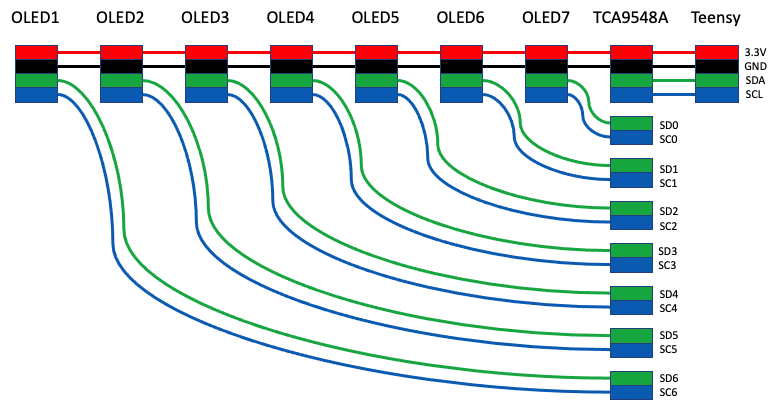
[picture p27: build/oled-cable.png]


The MAX7219CNG and 74HCT125 IC's are placed on panel 1, with six LED toggle switches. The other panels (2,3,4,5) are connected to this pain panel via a 8-pin jumper cable. From panel 1 a 6-pin jumper cable runs back to the Teensy. The other panels have a 2-pin connection back to the teensy.

The MCP23017 IC's are places on a separate PCB. A 6-pin jumper cable runs back to the Teensy. The rotary encoders are connected directly to the MCP23017s, using in total 31 jumper cables (3 per rotary encoder, 10 encoders in total, plus ground).

The picture below depicts the schema for the Teensy PCB, showing all connections to the other boards.

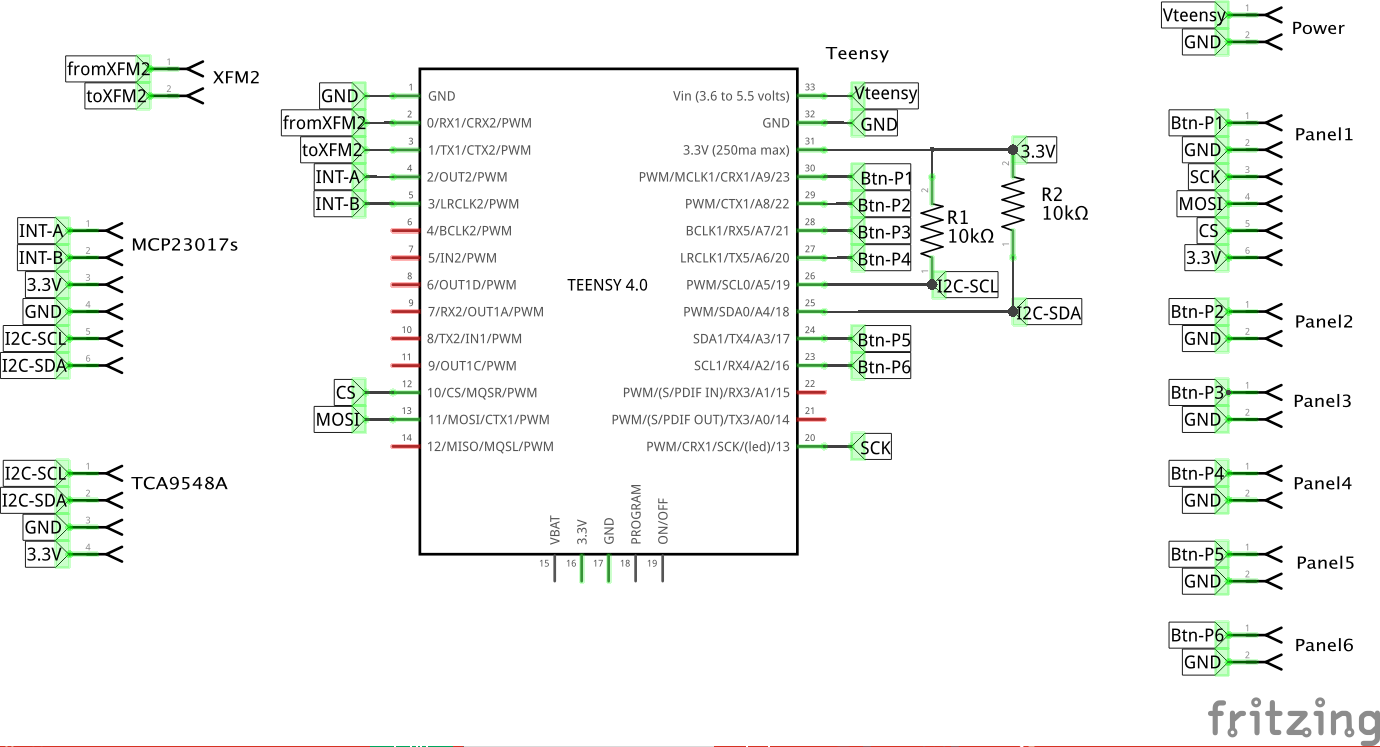
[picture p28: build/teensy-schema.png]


The Teensy itself is placed on a 5x7 PCB:

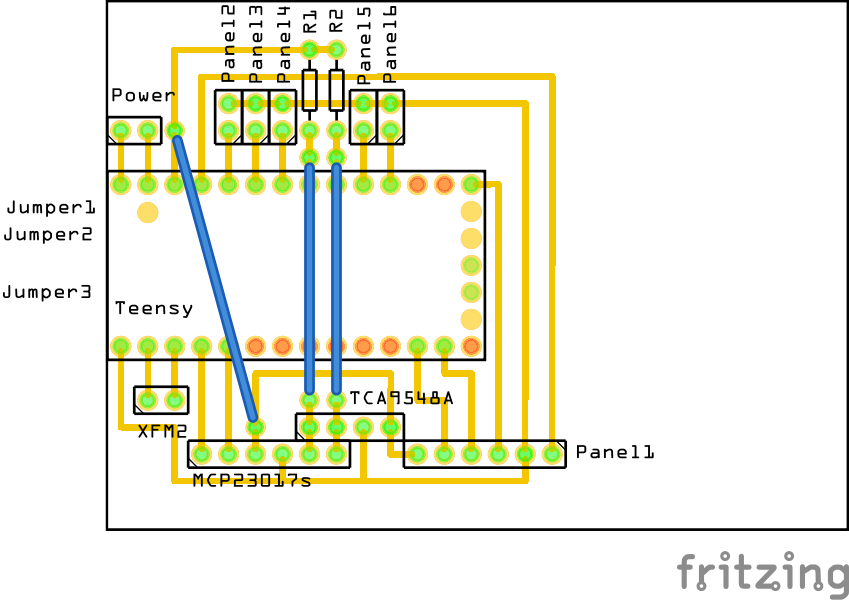
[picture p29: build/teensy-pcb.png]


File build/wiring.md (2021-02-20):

# Wiring instructions

The wiring could be done from the schematics, but just to be sure: here are some instructions, with photo's!

Buttons to analog input:
- Teensy most left: blue/green wire to panel with red buttons (blue to closest outside of panel)
- Teensy: white/black wire to top of panel with orange buttons (black to closest outside of panel)
- Teensy: purple/white wire to middle of panel with orange buttons (white wire to closest to other connector on same panel)
- Teensy: black/white wire to bottom of panel with orange buttons (black to closest outside of panel)
- Teensy most right red/brown wire to panel with green buttons (red to closest middle of panel)

Screens to Teensy:
- Yellow wire = Vin

Encoders:
(from top - red wires to bottom)
Top pins:
- Most left: blue - green - yellow: to 4th encoder
- Skip one pin
- green: to 5th encoder
- brown - rede - white: to 1th encoder (topmost encoder)

Next row:
- Most left: orange - brown - rede: to 6th encoder
- blue - yellow: to 5th encoder
- blue - purple - white: to 2th encoder

Next row:
- Most left: orange - brown - red: to 7th encoder (bottom encoder)
- skip one pin
- yellow: to 10th encoder (most right encoder)
- green - yellow - orangje: to 3th encoder

Next row:
- Most left: black: to 7th encoder
- black: to 8th encoder
- white - brown - red: to 8th encoder
- white - purple - blue: to 9th encoder
- green - orange: to 10th encoder

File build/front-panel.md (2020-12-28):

# Front panel

The front panel is made up of the following elements:

- Panels #1 to #6, fitting tightly together. Will probably fit them using screws, need to find out...
- A panel containing the MCP23017s, fitted to the front panel via two screws
- The OLED screens and PCBs, fitted to the front panel via four screws for every OLED screens. The PCBs are attached to the OLED screens via the headers, so no screws needed.
- The 10 rotary encoders, using the nuts and screw wire of the encoder itself.

Not all encoders are displayed: some are obscured by the PCB's (which need to be cut into shape!)

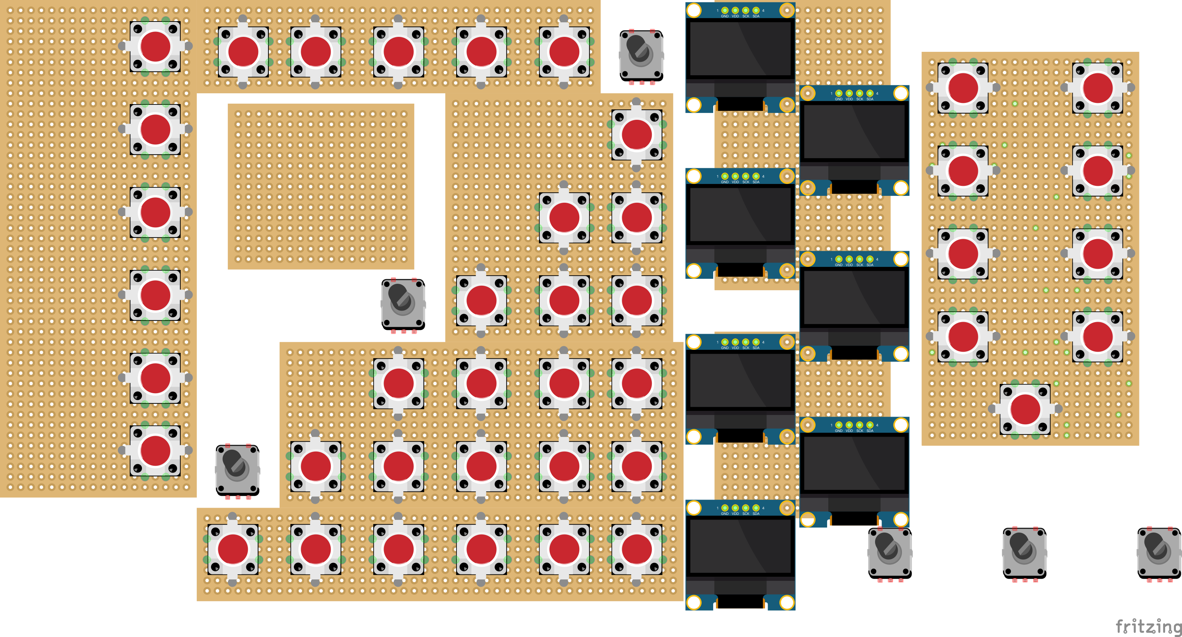
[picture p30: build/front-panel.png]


The buttons are placed at the right spot, but because the pins are not actually on the correct place, the allignment isn't correct.

## Dimensions

As most elements are attached to PCB screens, the dimensions of the front panel is best measured in "dots" of 0.1x0.1 inch, or 2.54x2.54 mm.

Most important are the dimensions of the tactle LED button, as depicted below:

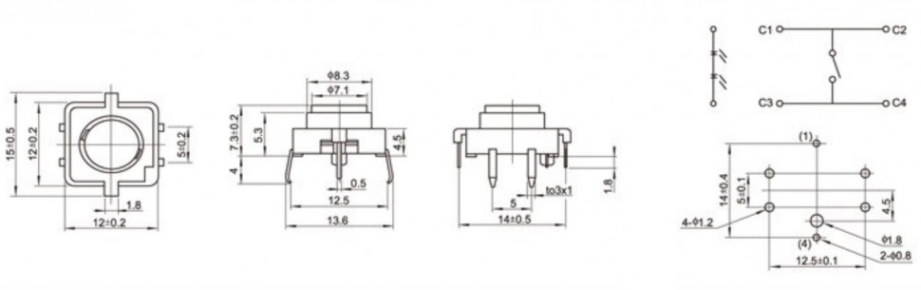
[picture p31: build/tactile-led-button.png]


The placement of the pins is not quite breadboard friendly, but it is just possible to place the pins according to the figure below. This means bending in the switch pins a bit inside. Be careful: the LED pins are quite fragile!

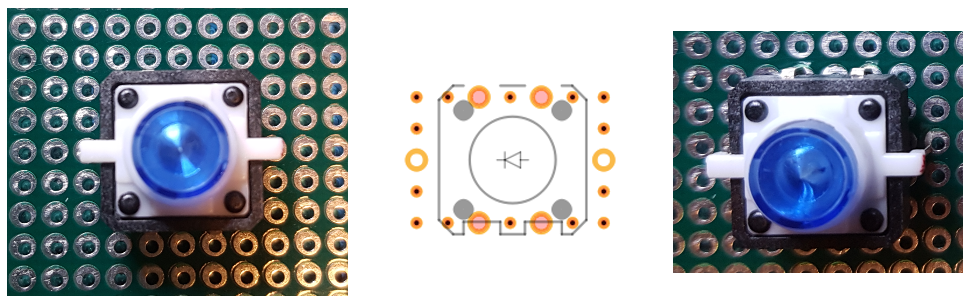
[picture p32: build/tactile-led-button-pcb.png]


Doing it this way, the button itself is exactly in the middle of a 7x7 dot rectangle. This means that if you rotate the button, the centre of the button doesn't move.

The distance between two buttons is 8 dots, so exactly 20.32 mm

The dimensions of the OLED screen are 10x10 dots, overlapping the dot area a bit, so you need 7 dots between two leds and 4 dots on each side of the leds. The holes for the screws are in the corners of the 10x10 matrix, so 9x2,54 = 22,86 mm apart.

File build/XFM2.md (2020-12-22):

# XFM2 board

Het XFM2 board bestaat uit de CMOD-A7-35T breadboard friendly bordje, plus de UDA1334a I2C stereo DAC bordje. Deze wordt aangesloten conform de beschrijving op https://www.futur3soundz.com. Anders dan op die beschrijving, doen we ook nog:

1. Een externe power input mogelijkheid (directe kabeltjes)
2. Stereo audio-out vanaf de DAC naar een dual jack output
3. Een RX/TX serial port mogelijkheid voor verbinding van de Teensy met de XFM2
4. De MIDI-in zit niet op de PBC, maar hiervoor wordt ook een afzonderlijke kabel gemaakt.

Het schema ziet er als volgt uit:

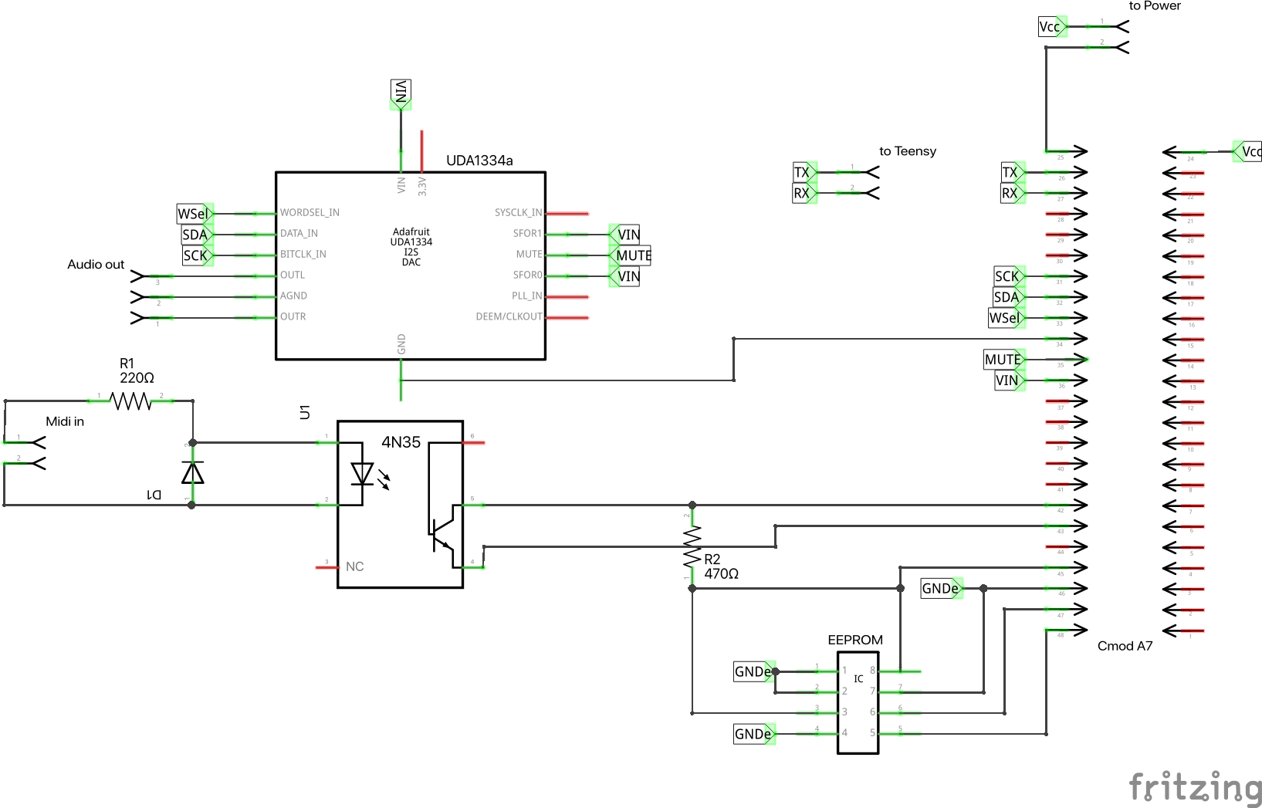
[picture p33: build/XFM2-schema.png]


## PCB

De PCB ziet er als volgt uit. We gebruiken:

- PCB 60x80 mm
- Minimale aantal pins: 19x24

Omdat het PCB aan de bovenkant direct moet beginnen met holes, omdat we zowel de mini-USB als mini-jack willen kunnen gebruiken, moeten we het PCB afsnijden. Hierdoor zijn de verbindingsgaten aan de voorkant niet bruikbaar. De oplossing is om extra gaten te boren:

- Rechtsboven
- Linksmidden (linksvoor kan niet, daar is geen ruimte genoeg)
- Links en rechtsonder

Het PCB kan in principe aan de onderkant ook een stukje korter gemaakt worden, of we gebruiken de gaten die daar al zitten.

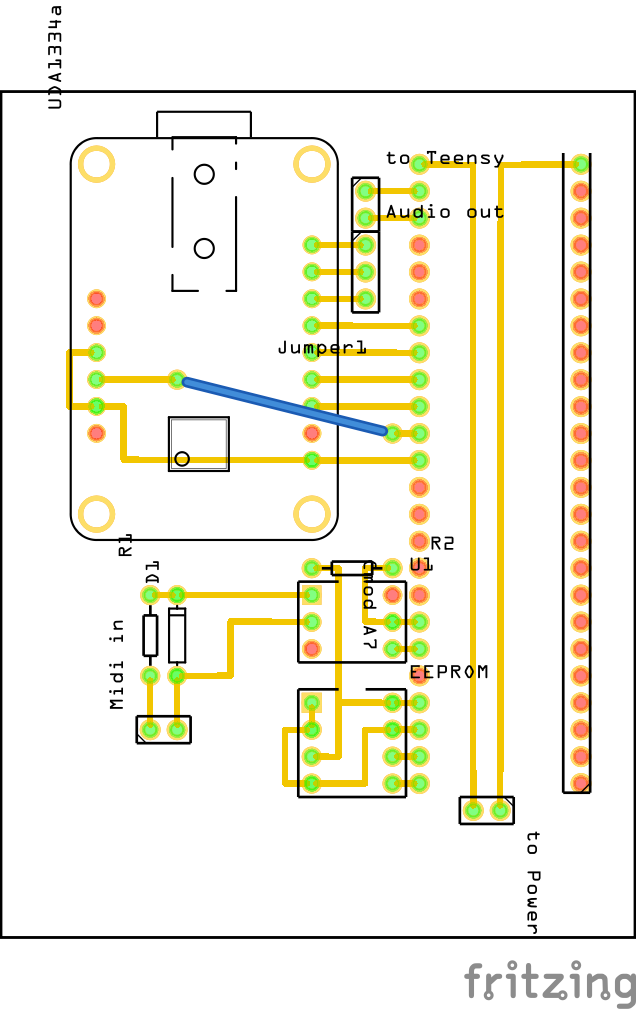
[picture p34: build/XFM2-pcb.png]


Merk op dat de "to Power" header feitelijk gewoon de draden zijn naar de powerconnector.

## BOM

- 1x PCB 6x8
- CMOD A7 35T
- UDA1334a
- 24LC1025 memory
- 8 pins IC voetje
- 4N35 optocoupler
- 1N4148 diode
- 220 Ohm resistor
- 470 Ohm resistor
- 1x 5-pin male header (2 pins to Teensy, 3 pins for audio out)
- 1x 2-pin male header (for midi-in)
- 1x JST power cable

## Installatie
De installatie volgens de website van de XFM2 gaat vrij straight-forward. Wel handig om in Realterm de display op uint8 te zetten, dan krijg je nummertjes terug in plaats van letters. In mijn geval was de com-poort nummer 6 (dat is te zien in Realterm), dus COM6 bij installatie met XLoad.

## Resultaat
Onderstaande afbeelding geeft het resultaat. Merk op dat de MIDI poort via een jumper-kabeltje is aangesloten, op de volgende manier:

- GROEN (4, vcc pin) gaat naar de weerstand
- GEEL (5, data-pin) gaat naar de diode

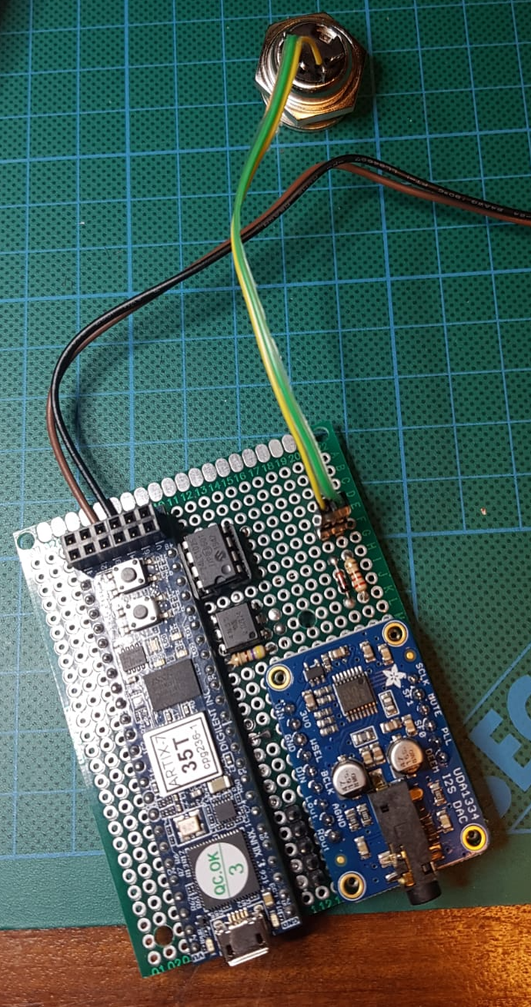
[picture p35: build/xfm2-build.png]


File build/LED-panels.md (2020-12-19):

# LED Panels

LED Panel #1 contains the blue LEDs, and the MAX7219CNG and the 74HCT125 ICs.

From panel #1 the connections are made to the other panels (#2 to #6), as depicted in the schema:

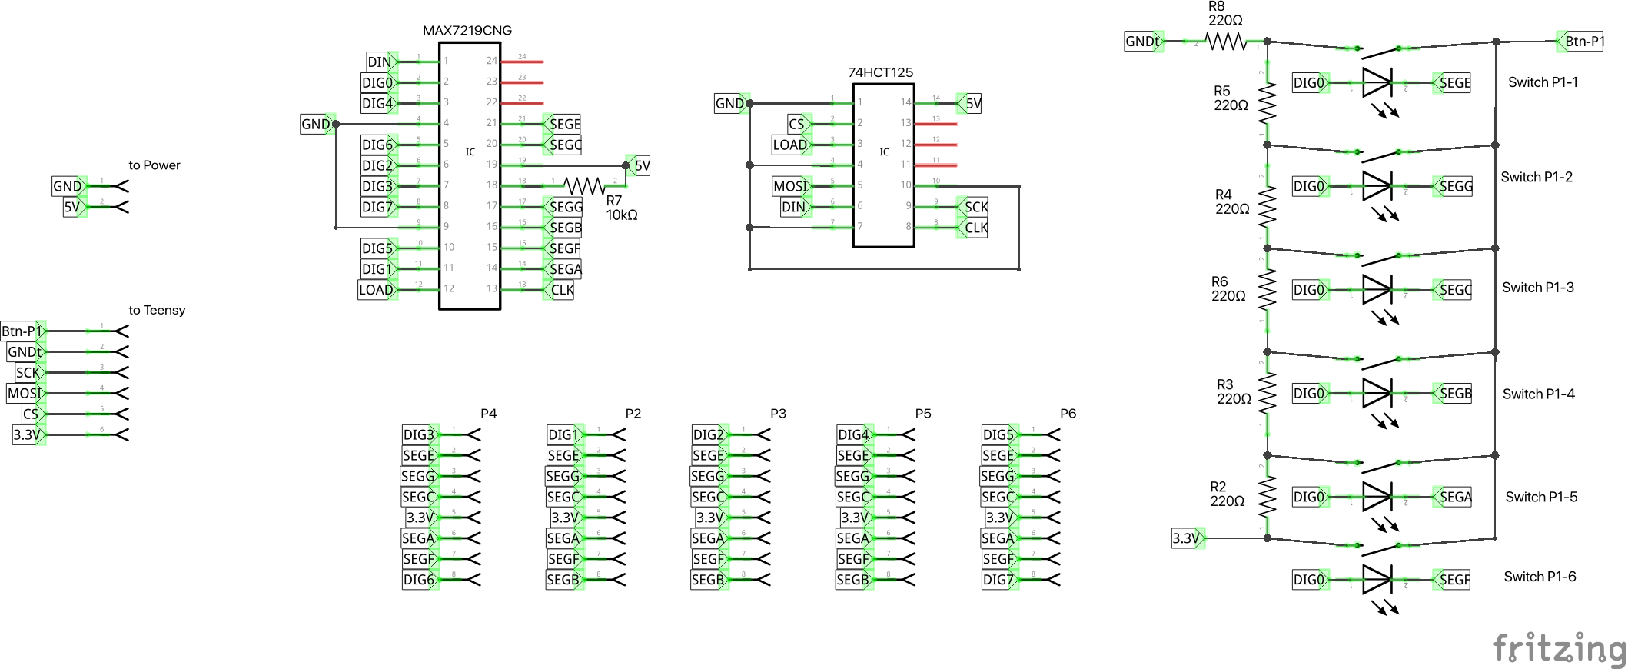
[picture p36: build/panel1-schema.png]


We use female-female jumper cables to connect all panels together. 8-pin cables to connect all panels and a 6-pin cable to connect the panel #1 PCB to the Teensy PCB.

## PCBs

PCB panels may not be correct: placement of diodes should be common cathode! At this moment, they are common anode :-). But the switch is bidirectional, so you can just rotate the switches.

### Panel #1

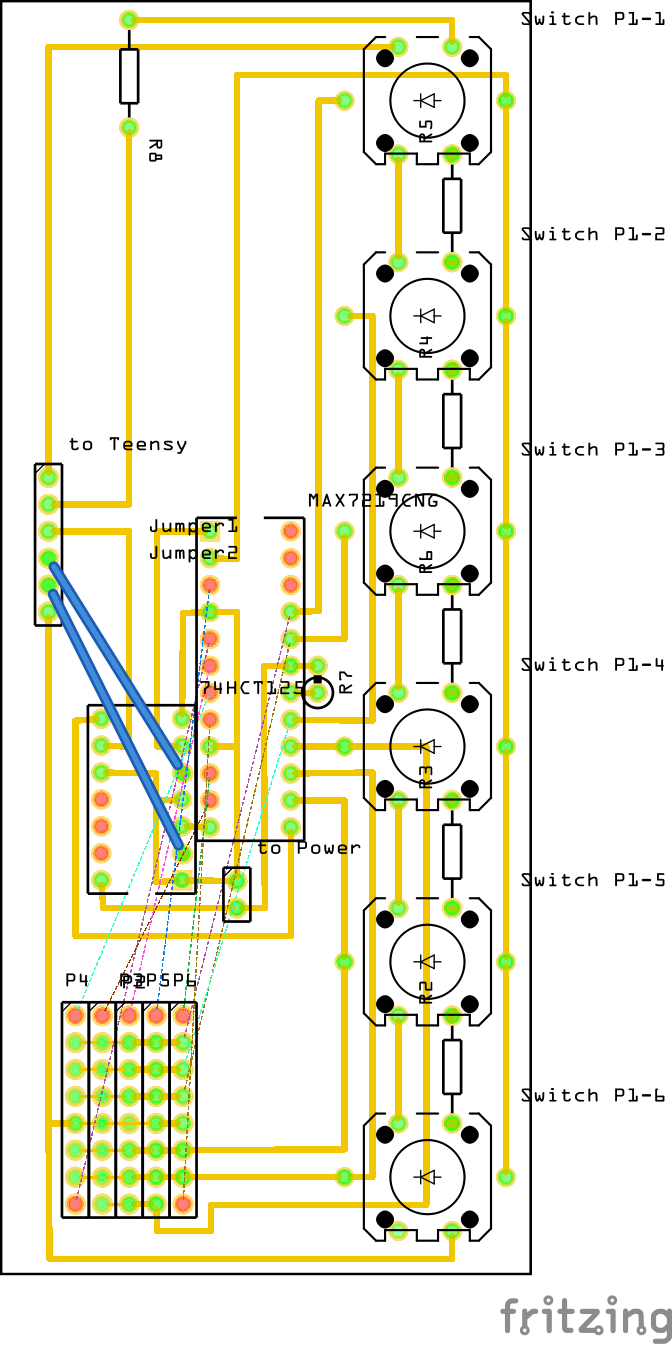
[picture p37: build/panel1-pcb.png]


Some jumper cables are not placed to not cloud the pcb, the dotted lines mark which jumper cables should be placed.

### Panel #2

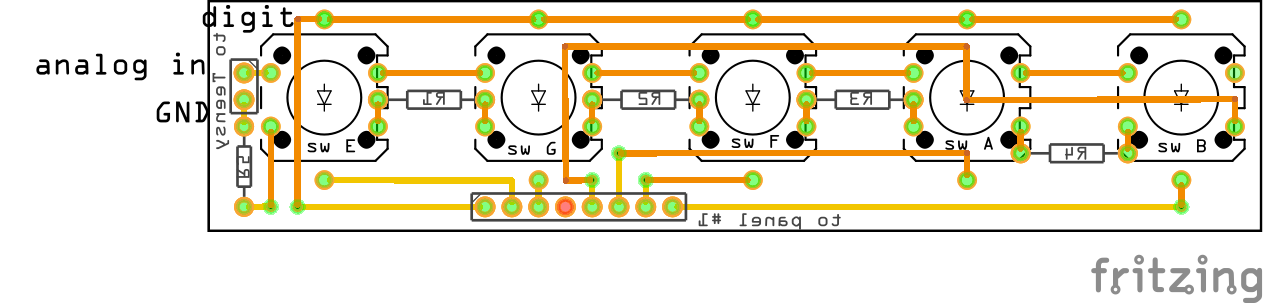
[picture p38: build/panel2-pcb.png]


The switches are on one side of the PCB, the header is on the other side. The resistors are also on the back.

Soldering the PCB in this order:
1. Solder routing wires on back & front (wires to the headers are on the front, others are on the back!)
2. Solder resistors (and use resistor wire to make routing complete)
3. Plug in switches and solder all connections
4. Finish with the two connection wires that are on the front and connected to the switches

## BOM

For panel #1:

- 1x PCB 12x5 (cut from a 15x9 PCB / 54x34 pins)
  - Pin count: 47x18
- 1x MAC7219CNG
- 1x 74HCT125
- 1x 24-pin IC socket
- 1x 14-pin IC socket
- 1x JCT power cable
- 1x male header 6 pins (to teensy)
- 1x female-female jumper cable 6 pins (to teensy)
- 5x male header 8 pins (to all other panels)
- 5x female-female jumpber cable 8 pins (to all other panels)
- 6x blue tactle LED button
- 6x 1.5kOhm resistor (9 kOhm total)

For panel #2:

- 1x PCB 10x2.2 (cut from a 15x9 PCB / 54x34 pins)
  - Pin count: 38x8
- 1x male header 8 pins (from panel #1)
- 5x red tactle LED button
- 1x male header 2 pins (to teensy)
- 5x 2.2kOhm resistor (11 kOhm total)

For panel #3:

- 1x PCB 12x2.2
  - Pin count: 46x8
- 1x male header 8 pins (from panel #1)
- 6x green tactle LED button
- 1x male header 2 pins (to teensy)
- 6x 1.5kOhm resistor (9 kOhm total)

For panel #4:

- 1x PCB 10x4
  - Pin count: 38x15
- 1x male header 8 pins (from panel #1)
- 9x orange tactle LED button
- 1x male header 2 pins (to teensy)
- 9x 1kOhm resistor (9 kOhm total)

For panel #5:

- 1x PCB 6x5.5
  - Pin count: 23x21
- 1x male header 8 pins (from panel #1)
- 6x orange tactle LED button
- 1x male header 2 pins (to teensy)
- 6x 1.5 kOhm resistor (9 kOhm total)

For panel #6:

- 1x PCB 10x6.1
  - Pin count: 37x20
- 1x male header 8 pins (from panel #1)
- 9x green tactle LED button
- 1x male header 2 pins (to teensy)
- 9x 1 kOhm resistor (9 kOhm total)

Resistor total:
- 1 kOhm: 9+9 = 18
- 1.5 kOhm: 6+6+6 = 18
- 2.2 kOhm: 5

Panels total:
- 1x PCB 12x5 (cut from a 15x9 PCB / 54x34 pins)
  - Pin count: 47x18
- 1x PCB 10x2.2 (cut from a 15x9 PCB / 54x34 pins)
  - Pin count: 38x8
- 1x PCB 12x2.2 (cut from a 15x9 PCB / 54x34 pins)
  - Pin count: 46x8
- 1x PCB 10x4 (cut from a 15x9 PCB / 54x34 pins)
  - Pin count: 38x15
- 1x PCB 10x6.1 (cut from a 15x9 PCB / 54x34 pins)
  - Pin count: 37x23

- 1x PCB 6x5.5 (cut from 7x9 or 6x8 board)
  - Pin count: 24x22

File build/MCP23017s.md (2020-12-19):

# MCP23017

We have two MCP23017 to interface with all encoders. These chips are placed on a separate PCB that is fixed to the frontpanel. We have exactly one spot that fits :-). The PCB is a 5x7 PCB that is cut to 5x4 size, so we need to drill two extra holes.

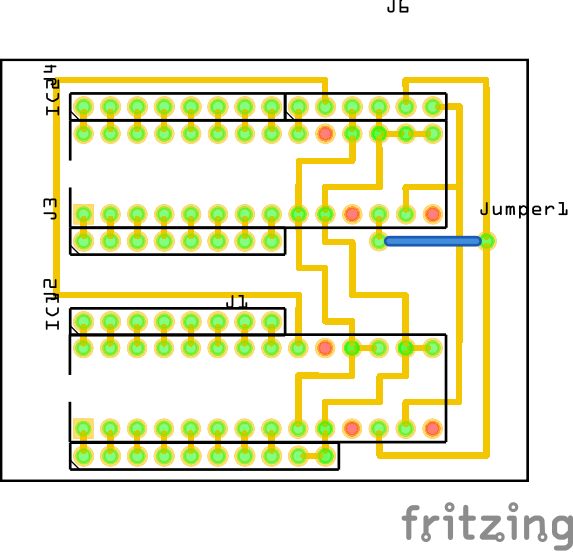
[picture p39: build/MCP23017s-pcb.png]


Dimensions:
- Minimal pins: 15 x 17
- Minimal dimensions: 44 x 38

At these dimensions, it is almost impossible to screw the board to the front panel. It would be better to have a little bit more room to drill some extra holes outside the dimensions above (maybe 44 x 50 would be perfect - if that is possible)

## BOM
- 1x 5x7 PCB
- 2x MCP23017
- 2x 28pin IC socket
- 3x female header 8pins (using male jumper cable to all encoders)
- 1x female header 10pins (this one has to extra GND pins)
- 1x male header 6pins (to Teensy PCB)
- 1x female-female jumper cable 6pins (to Teensy PCB)
- 1x male or female 1pin (for ground to all encoders)

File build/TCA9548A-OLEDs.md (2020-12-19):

# OLEDs and TCA9548A multiplexer

De OLEDs worden via een TCA9548A multiplexer verbonden met de Teensy. Reden is dat alle OLEDs op hetzelfde I2C adres zitten, dus een enkele bus gaat niet werken.

De TCA9548A heeft 8 afzonderlijke I2C bussen, dus je kunt maximaal 8 OLEDs aansturen.

Onderstaand figuur geeft het schema voor de verbindingen.

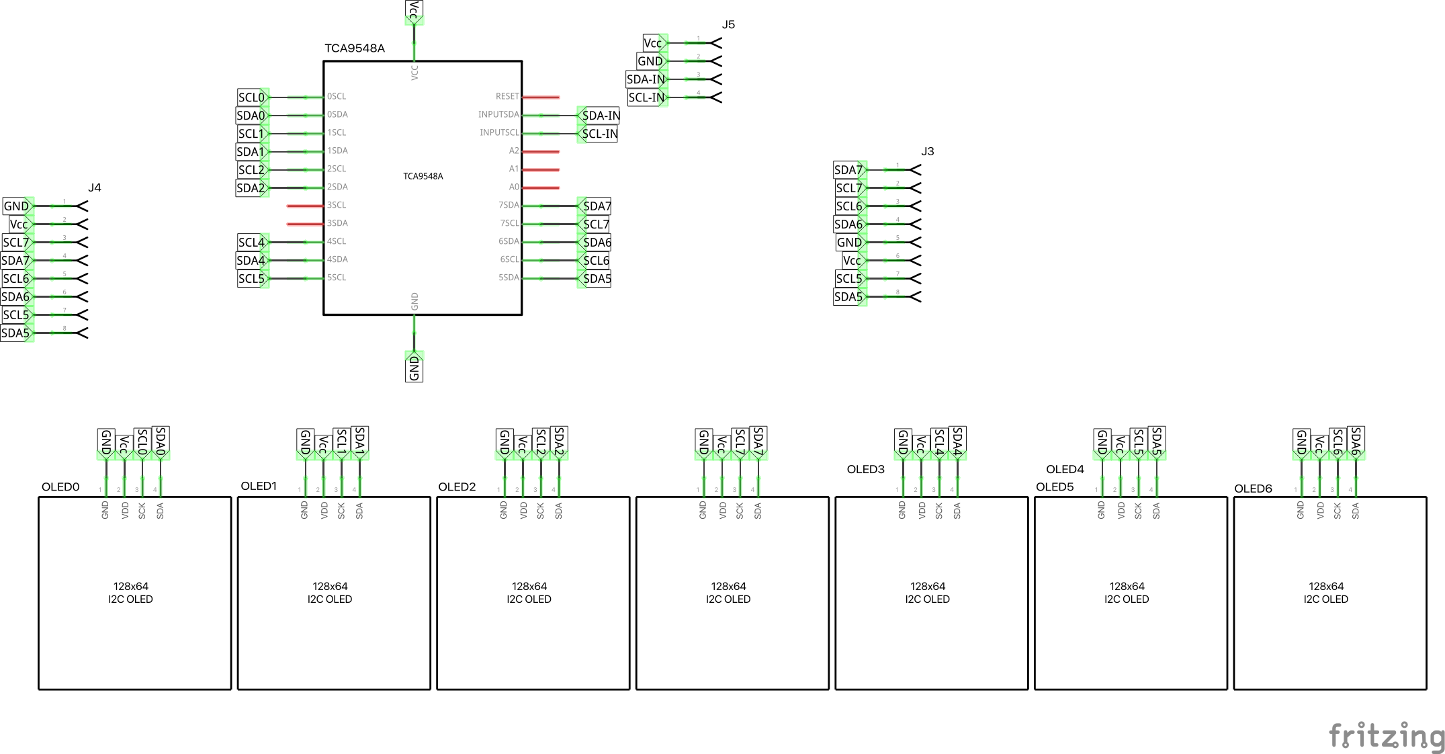
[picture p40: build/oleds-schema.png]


Het idee is om alle OLEDs direct op het frontpanel te bevestigen. Vervolgens hebben we twee PCBs (5x7 en 6x8) die female headers hebben waarop de OLEDs aangesloten kunnen worden. Op die manier "klik" je eigenlijk de PCB's op de OLEDs. De twee PCB's worden verbonden met een custom 8x8 female header kabel. Op de grootste PCB zit ook de TCA9548A multiplexer (op de andere kant dan de female headers). Aan deze kant zit ook weer een male header (4 pins), waarmee de TCA9548A verbonden is met de Teensy.

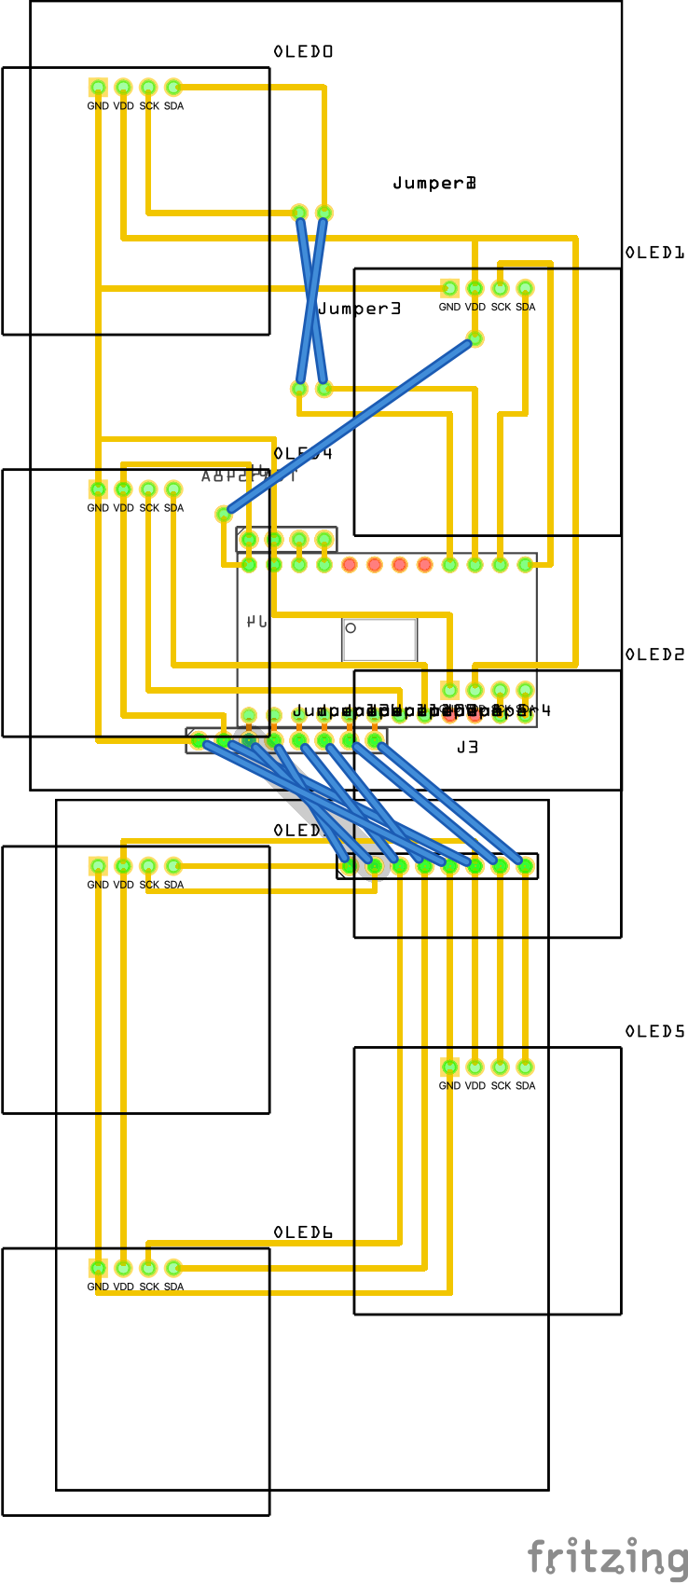
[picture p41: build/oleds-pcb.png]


Unsure: do we need pull-up resistors for the I2C lines? Not a problem to add to the board, but unsure...

Minimum dimensions for the board:
- PCB 5x7 cm: 18x17
- PCB 6x8 cm: 18x27

The OLED screens are fixed to the front panel, the PCB board are attached to the OLED screens via the female headers, this means that we don't have to use the screw holes of the PCBs.

## BOM

- 1 TCA9548A
- 7 OLEDs
- 1 PCB 5x7
- 1 PCB 6x8
- 7 female headers 4 pins
- 1 male header 4 pins
- 2 male headers 8 pins
- 1 custom female wire 8 pins

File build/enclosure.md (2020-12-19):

# Enclosure

For the enclosure we use a [TEKO 364.8 enclosure](teko-3648.pdf).

On the left side of the enclosure, we will have three sockets:
- A mini USB socket for the XFM2;
- A mini stereo jack socket for the audio-out;
- A mini USB socket for the Teensy.

We need 60 + 5 + 50 = 115 mm space to house the PCB's on which these sockets are placed, to that's OK.

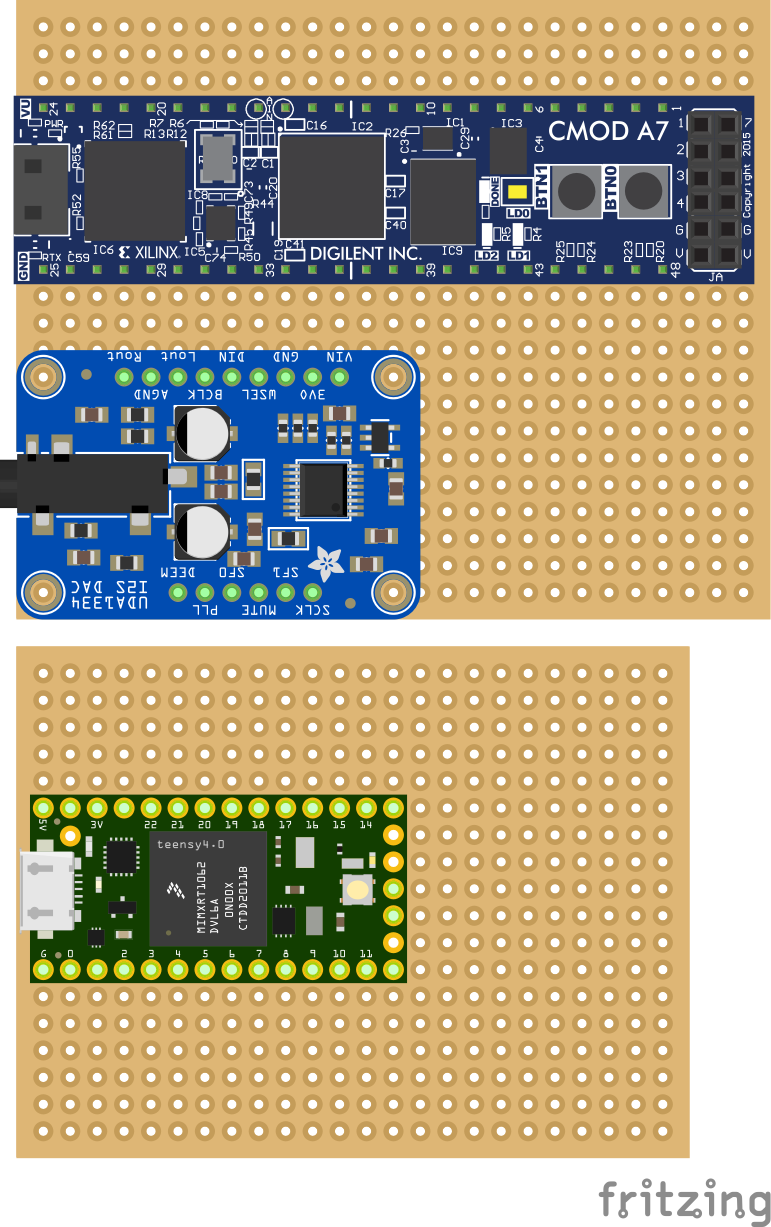
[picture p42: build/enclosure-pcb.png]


On the back side of the enclosure, we will also have three sockets:
- A MIDI out socket, connected to the XFM2;
- A dual mono-jack socket, connected to the DAC;
- A power socket, connected to the power PCB.

In normal operation, you only use the back sockets, in prototyping situation, you only use the side sockets.

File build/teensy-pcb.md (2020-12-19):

# Teensy PCBs

The Teensy PCB only holds the Teensy, plus a lot of connectors. We may put the Teensy PCB and the Power PCB on the same PCB?

The schema is as follows:



We use (again...) a 5x7 PCB to hold the Teensy:



We need to cut the PCB very tightly, because we need ground and 5V to be connnected, BUT also directly outside the PCB, because we want to be able to use the mini USB! This also means that we have to drill some extra holes to fix the Teensy PCB to the enclosure.

Minimal pins on the PCB: 17x17

## BOM

- 1x 5x7 PCB
- 1x Teensy 4.0
- 1x Power JST cable
- 2x male headers 6pins
- 1x male header 4pins
- 5x male headers 2 pins (or 2x 2x3 pins female - if we use male jumper cable)
- 5x female-female 2 pins jumper cable (or male/male??) => need to make, or use individuals...
- 1x male header 2pins

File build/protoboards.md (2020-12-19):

# Protoboards

## 50 x 70 mm

Aantal holes: 18 x 24

Aanwezig: 8

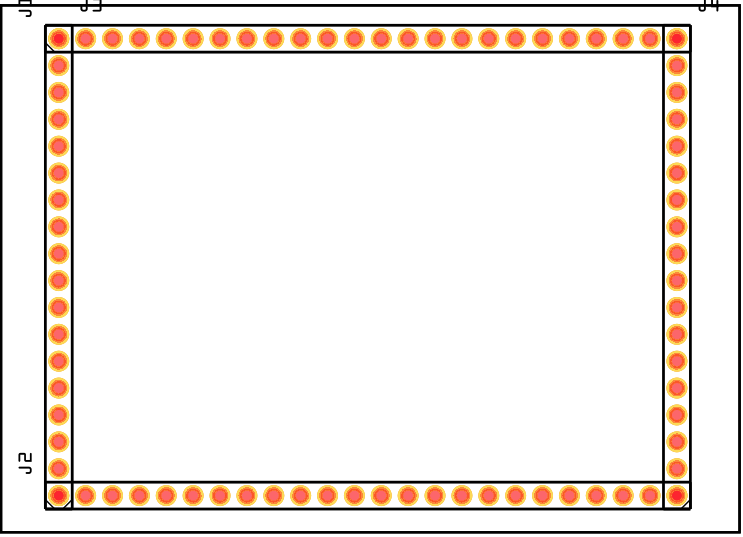
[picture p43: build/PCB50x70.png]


## 60 x 80 mm

Aantal holes: 22 x 27

Aanwezig: 2

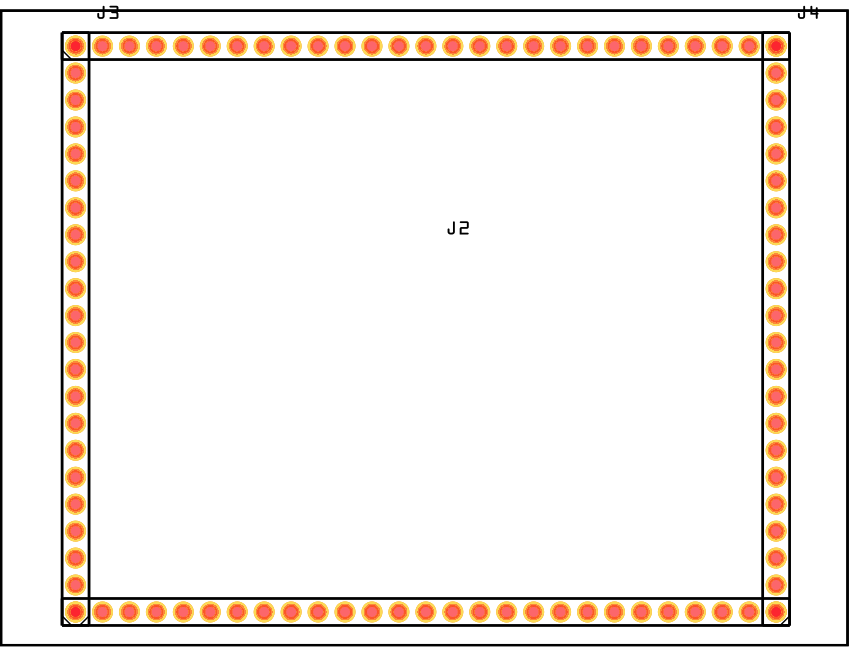
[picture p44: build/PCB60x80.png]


## 70 x 90 mm

Aantal holes: 26 x 31

Aanwezig: 2

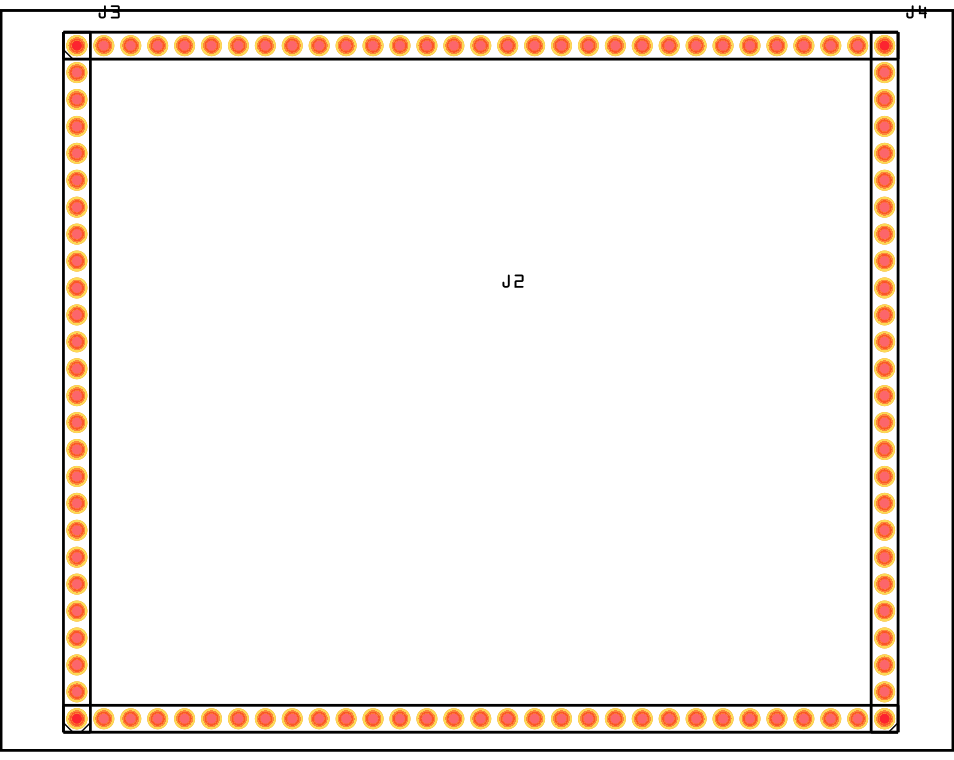
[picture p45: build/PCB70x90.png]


## 90 x 150 mm

Aantal holes: 34 x 54

Aanwezig: 4

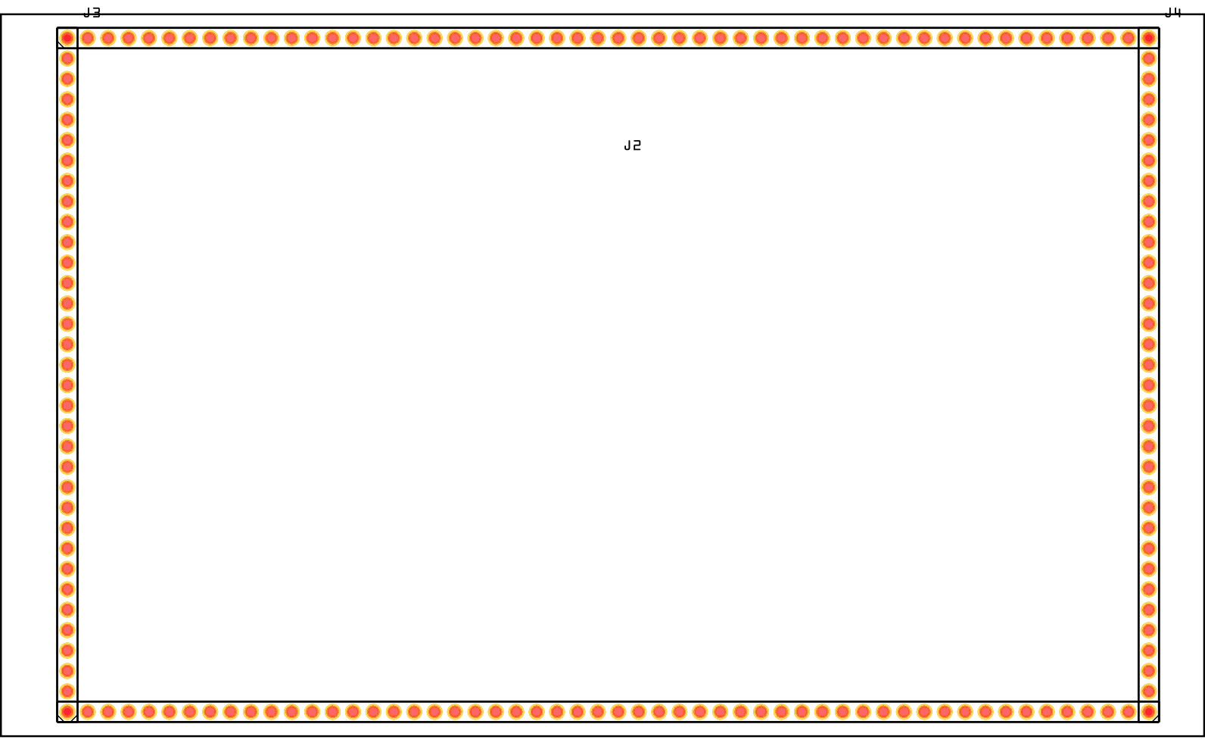
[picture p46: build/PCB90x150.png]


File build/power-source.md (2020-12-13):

# Power source

Power comes from a 9V wall transformer. Anything between 8V and 12V is probably OK (see 7805 datasheet).

See the diagram below for the actual circuit.

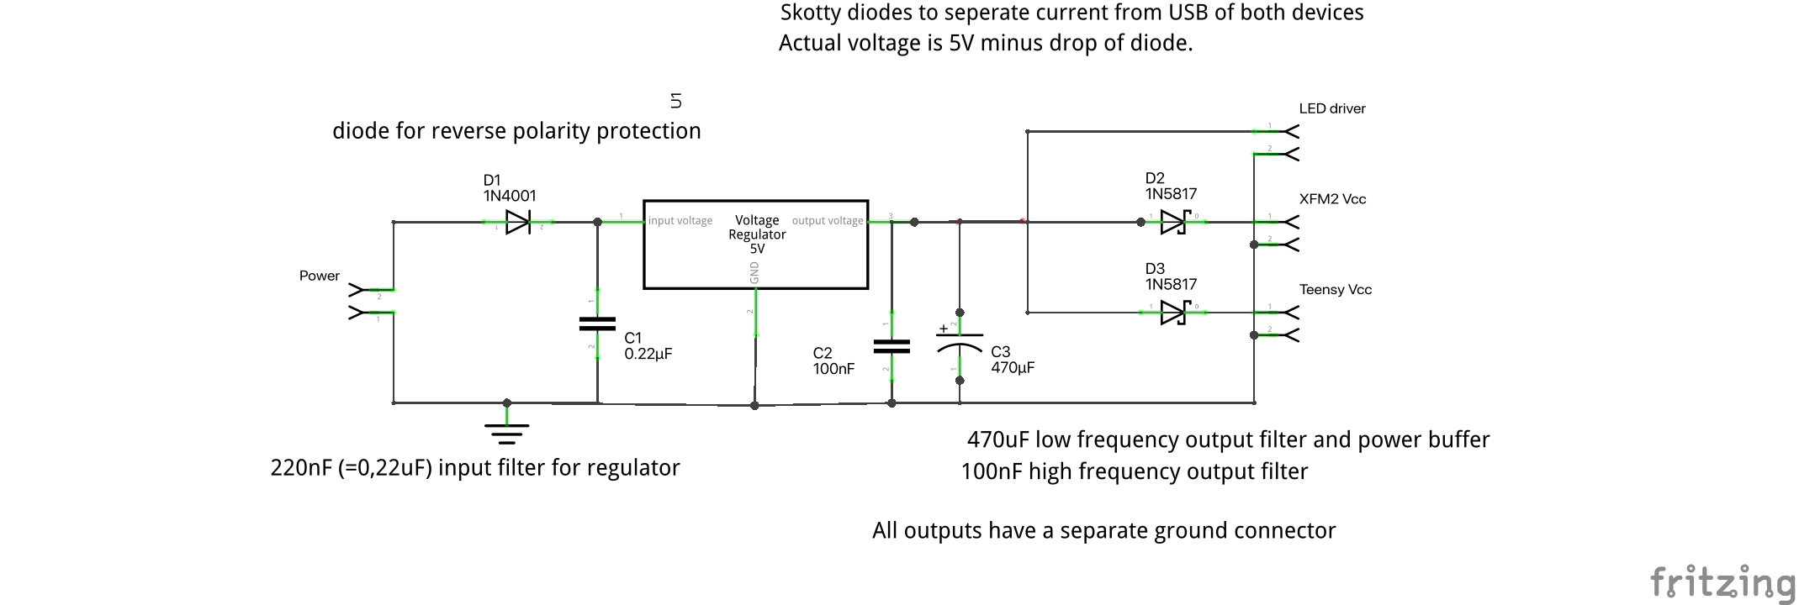
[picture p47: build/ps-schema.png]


## Components explained

### Regulator
* A normal 7805 5V regulator is used.

### Diodes
* A rectifier diode is used before the voltage regulator to protect the circuit from reverse polarity. The voltage drop is about 0.7V, so the actual voltage going into the voltage regulator is Vin - 0.7V. So we are pretty flexibel with the input voltage, as long as it is 0.7V above the minimum specified in the 7805 datasheet.
* A skotty diode is used between the ouputs to the XFM2 and the Teensy. These diodes are necessary, because we want to power the XFM2 and the Teensy from USB, and we don't want any voltage going into the rest of the circuit (or back into the voltage regulator). The diode will drop the voltage from the regulator a bit. We probably get around 4.7V into the XFM2 and the Teensy. This is according to specifications (and actually this is the specified way to have both XFM2 and Teensy dual powered!).
  * XFM2: https://reference.digilentinc.com/reference/programmable-logic/cmod-a7/reference-manual
  * Teensy: https://www.pjrc.com/teensy/external_power.html

### Capacitors
* A 470uF capacitor is used as a low frequency filter of the output of the voltage regulator and (maybe more important) a powerbuffer when a lot of current is drawn from the regulator. Probably overkill, but we don't want the CPU's to go down because we light up the christmas tree of LED's :-).
* A 100nF capacitor high frequency filter for the output of the regulator and a 220nF capacitor high frequency filter for the input of the regulator are used according to spec (actually a 330nF is specified, but that we don't have...). This makes the output of the regulator a bit more stable.

## breadboard
Bottom of the breadboard is the input voltage (9V, or whatever), Top of the breadboard is the output voltage (5V)

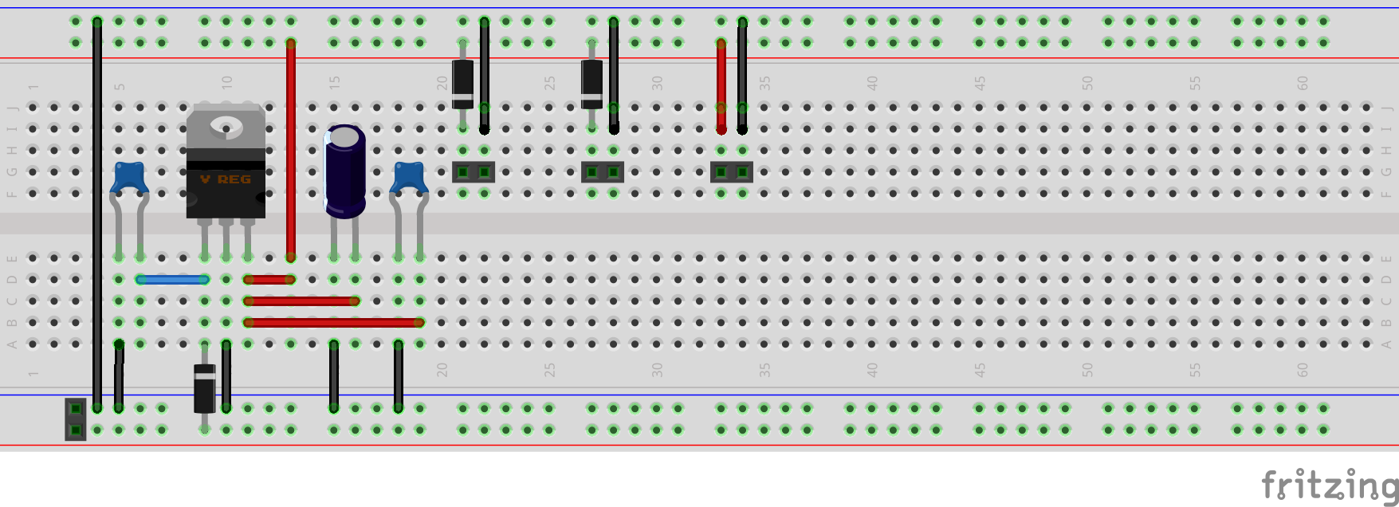
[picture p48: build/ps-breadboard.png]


## PCB
The input for the power regulator comes from a socket mounted into the enclosure. So we have two pads on the PCB marked Vin and GND.

The output to the other circuits is via 2 male sockets. Every circuit (XFM2, Teensy, LED driver) has its own 2 pins: Vcc and GND. The LED driver gets 5V, the XFM2 and Teensy 5V minus the drop of the skotty diode (about 4.8V).

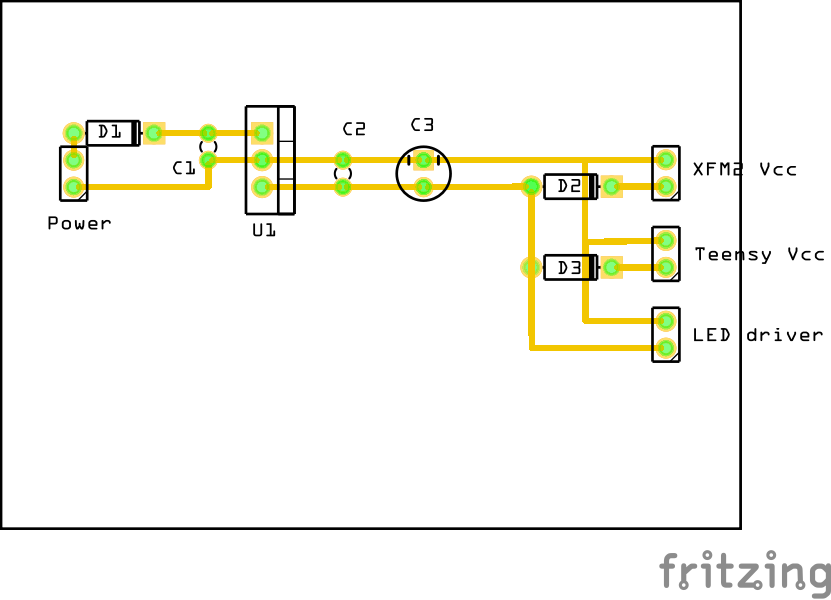
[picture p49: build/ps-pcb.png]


The 5x7 PCB is a bit to large, no problem: room enough, and using this PCB we can use the screw holes.

## Power consumption

* The OLED screens consume around 25mA all pixels enabled. This will however never happen. Normal consumption will max 10mA and min 1,6mA (seee: https://www.youtube.com/watch?v=MF3Qfimeo3c).
* Teensy 4.0 consumes around 100mA (see: https://www.pjrc.com/store/teensy40.html)
* The 3.3V pin of the Teensy 4.0 is specified at 250mA max, so we are within specifications running all OLED screen via the Teensy 3.3V
* The LED driver uses the main power directory, so no issues here. In the MAX7219 datasheet is specifies that typical operation with all LEDs on, 330mA is used. But we don't use all LED's, and they are never all on, so typical use will be far less.
* The XFM2 will probably be also max 500mA, but normal operation is probably between 100mA and 250mA, so no problems.
* The 7805 maxes at 1.5A, but will probably heat up a bit, so 1000mA is probably a safe bet (the Teensy has a 500mA fuse)

Using a 1A wall transistor at 9V is probably more than enough...

## BOM

- 1x 7805 Power regulator 5V
- 1x 470uF capacitor
- 1x 100nF capacitor
- 1x 220nF capacitor
- 2x Skotty diode 20V
- 1x power rectifier diode
- 3x JST male 2-pin connectors
- 1x 5x7 PCB

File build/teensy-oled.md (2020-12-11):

# Teensy-OLED

## Elektronica

Het schema voor de Teensy kun je [hier](teensy40.md) vinden.

Daaruit blijkt de volgende opbouw:
- Pin 1 is Ground (gelabeld "G")
- Pin 25 is SDA-0 (gelabeld "18")
- Pin 26 is SCL-0 (gelabeld "19")
- Pin 31 is 3.3V (gelabeld "3V")

Daarmee is ook duidelijk hoe we ze moeten verbinden:
- Ground met GND op de OLED
- SDA-0 met SDA op de OLED
- SCL-0 met SCK op de OLED
- 3.3V met VDD op de OLED

Merk op dat op een Arduino dit vrij vergelijkbaar is:
- Arduino GND met GND op de OLED
- Arduino A4 met SDA op de OLED (A4 is ook pin 25 op de Teensy)
- Arduino A5 met SCK op de OLED (a5 is ook pin 26 op de Teensy)
- Arduino 5V met VDD op de OLED

Merk op dat daarmee de OLED op 5V draait met de Arduino, en op 3.3V op de Teensy.

Tenslotte is het van belang om twee 10K pull-up resistors te verbinden met SDA en SCK. Pull-up resistors zijn noodzakelijk bij een I2C bus. Dergelijke pull-up resistors kunnen al op een bordje zitten waarop het OLED scherm zit, maar dit is niet altijd het geval. Onduidelijk is ook of dit voor dit schermpje zo is, maar het lijkt van niet: dus deze ook afzonderlijk toevoegen.

Zie ook: https://electronics.stackexchange.com/questions/102611/what-happens-if-i-omit-the-pullup-resistors-on-i2c-lines
Hoewel de wire library de interne pull-ups van de Arduino/Teensy activeert, zijn deze te groot (50K?). Dus dan werken 10K beter. Of wellicht 4.7K nog iets beter. Uiteindelijk is het een verhouding tussen R en C, waarbij C toeneemt als je meer draadjes of elementen toevoegd aan de I2C bus. En aangezien we nogal wat OLEDs willen toevoegen, is de kans groot dat we de pull-ups nog wat lager willen doen. Zie https://www.ti.com/lit/an/slva689/slva689.pdf?ts=1607667801873 voor een mooie uitleg over het bepalen van de waarde voor R.

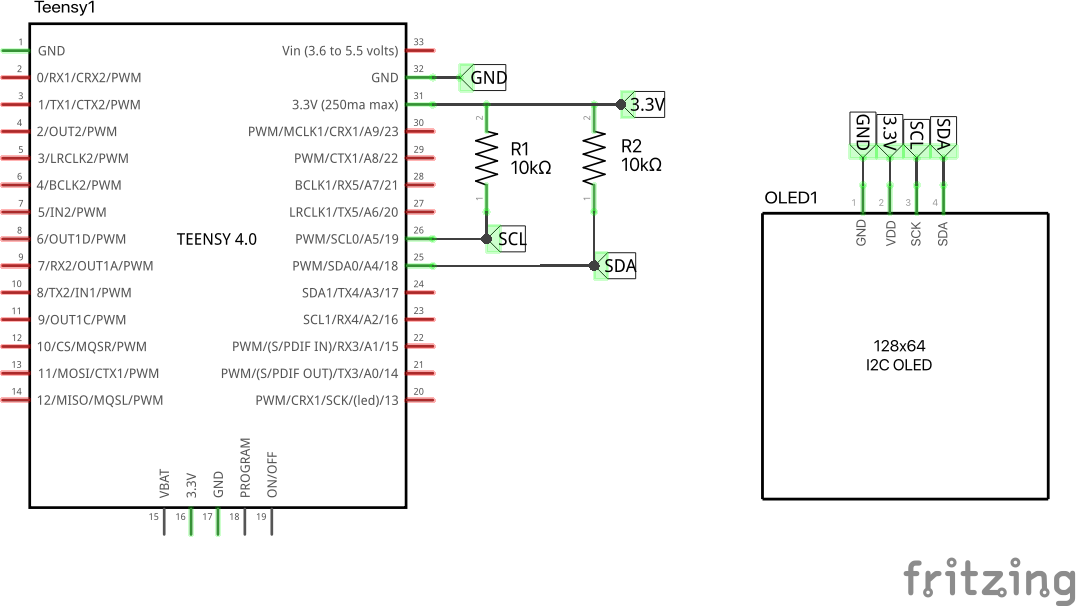
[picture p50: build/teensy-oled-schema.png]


Het resultaat ziet er dan op een breadboard als volgt uit:
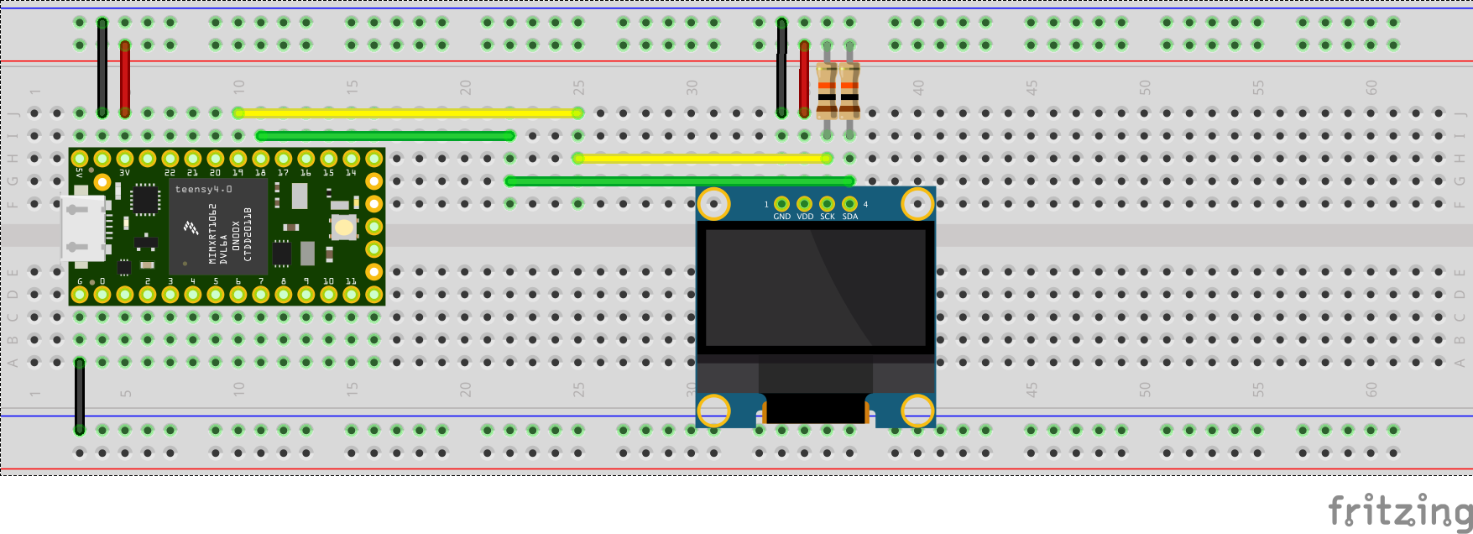
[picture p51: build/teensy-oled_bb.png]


## Op zoek naar de I2C client
Een I2C client werkt op een bepaald adres. Zonder dit adres te weten, zal de client niet weten wat hij moet doen, en zal dus het OLED schermpje niets laten zien.

Op https://playground.arduino.cc/Main/I2cScanner/ is een I2C scanner te vinden, die zal vertellen op welk adres de OLED display zit. In ons geval is dit 0x3C.

## Adafruit SSD1306 library
De pagina op tinytronics toont aan dat de OLED display werkt met de u2g2 library. Deze werkt "from ground up", en biedt bovendien een softwarematige I2C library (die vrij traag is). Het is echter wel een handige om problemen te vinden. De library werkt zowel voor de Arduino Uno als de Teensy 4.0, mits bij die laatste de SDA-0/SCL-0 pins worden gebruikt (de Teensy 4.0 heeft meerdere I2C bussen).

We willen echter de SSD1306 library gebruiken: deze werkt voor onze display, maar heeft als voordeel dat deze de Wire library gebruikt, die weer van belang is als we straks de I2C multiplexer gaan gebruiken. Beter nu dan alvast de goede library gebruiken!

Het voorbeeld dat bij deze library staat werkt voor deze display (gebruik het 128x64 I2C voorbeeld), maar in plaats van 3D moet 3C gekozen worden voor het I2C-adres van de display.

Het plan is dus nu om voor 1 OLED display een mooie user interface te maken!

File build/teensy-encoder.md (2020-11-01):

# Teensy encoder

We use an encoder with 5 pin:
- Pin A: output 1 (left pin)
- Pin C: common (middle pin)
- Pin B: output 2 (right pin)
- Pin D: switch left
- Pin E: switch right

The switch is a "normal" push button, so we can do the following:
- VCC to pin D
- Pull-down resistor on pin E
- Read value of pin E via digital IN
(je krijgt dan HIGH als er op de button wordt gedrukt)

Kan ook andersom:
- Ground to Pin D
- Pull-up resistor on pin E
- Read value of pin E via digital IN
(je krijgt dan LOW als er op de button wordt gedrukt)

The encoder werkt als volgt:

Hier staat het wel aardig: http://www.bartvenneker.nl/Arduino/index.php?art=0016
- Pin C gaat naar GND
- Pin A naar Digital input 2
- Pin B naar Digital input 3

(inputs 2 en 3 zijn interuptable)

Inmiddels ook een aardige gevonden, die ook debouncing doet in de software: hierdoor geen hardware aanpassingen nodig!

=> Dit kan ik dan later ook gebruiken bij de MCP23017
    -> Die werkt ook met een interupt

Hier staat het goed uitgelegd: https://www.best-microcontroller-projects.com/mcp23017.html

Deze lijkt ook wel aardig, en met een library: https://github.com/blemasle/arduino-mcp23017/blob/master/examples/PortCopyOnInterrupt/PortCopyOnInterrupt.ino

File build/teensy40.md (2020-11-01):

# Teensy 4.0

Onderstaand figuur geeft de pin layout van de Teensy 4.0 weer. Zie ook https://www.pjrc.com/store/teensy40.html voor de bron.

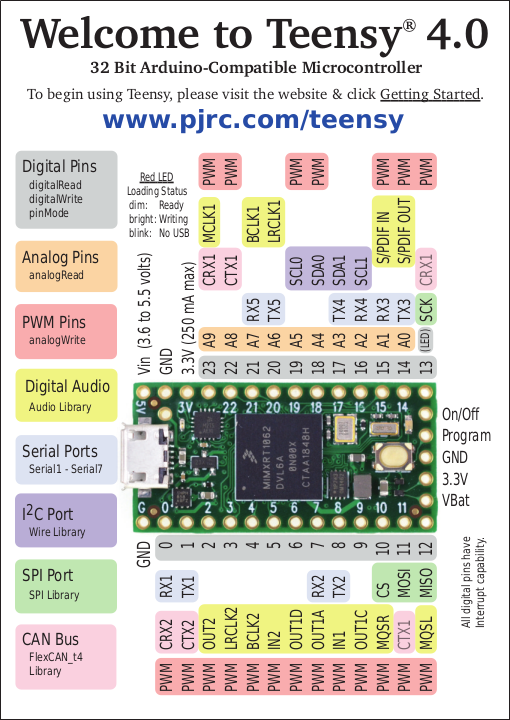
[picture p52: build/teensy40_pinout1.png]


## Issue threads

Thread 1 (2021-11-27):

Hanging up

craigyjp, 2021-11-27:
I built this interface and I find that it will lock up at random times. Usually when turning the encoders. But it can also happen when pressing buttons. Did you have any issues like this when operating your build.

architolk, 2021-11-28:
Whow! the whole interface? Kudo's! I remember that I had a couple of timing issues, mostly relate to the encoders. I did a lot of testing with the individual components (look into the /src directory for different .ino files), before creating the whole interface. I don't think the hardware should be a problem (the encoders or the multiplexers), but the Teensy MCU and the software (and the libraries in use) can cause problems. I haven't experienced any problems myself in this final build. I suggest to make some small test scripts and upload them to the teensy to find out what the problem exactly is.
The "button" in the encoder itself is in the same part of the hardware as the encoders themselves, but if you have lock-up problems in the LED-buttons as well, than it must be in the Teensy itself, or two unrelated problems, as these two parts of the interface are totally separated (the encoders work via the multiplexer, the buttons via the analog inputs). There might be a problem in the software of the Teensy, as this is all just prototyping, but as I haven't experienced these problems lately, I don't know what that might be...

craigyjp, 2021-11-28:
When I compile the code I get some messages regarding the method of reading the registers, it complains about the method used. Other than that everything is ok with the compilation. A few things to not e is that you did not implement anyway to save the patches from what I can see, also things like the arpeggiator and layer modes are not available. It would be nice if the editor could enable them.

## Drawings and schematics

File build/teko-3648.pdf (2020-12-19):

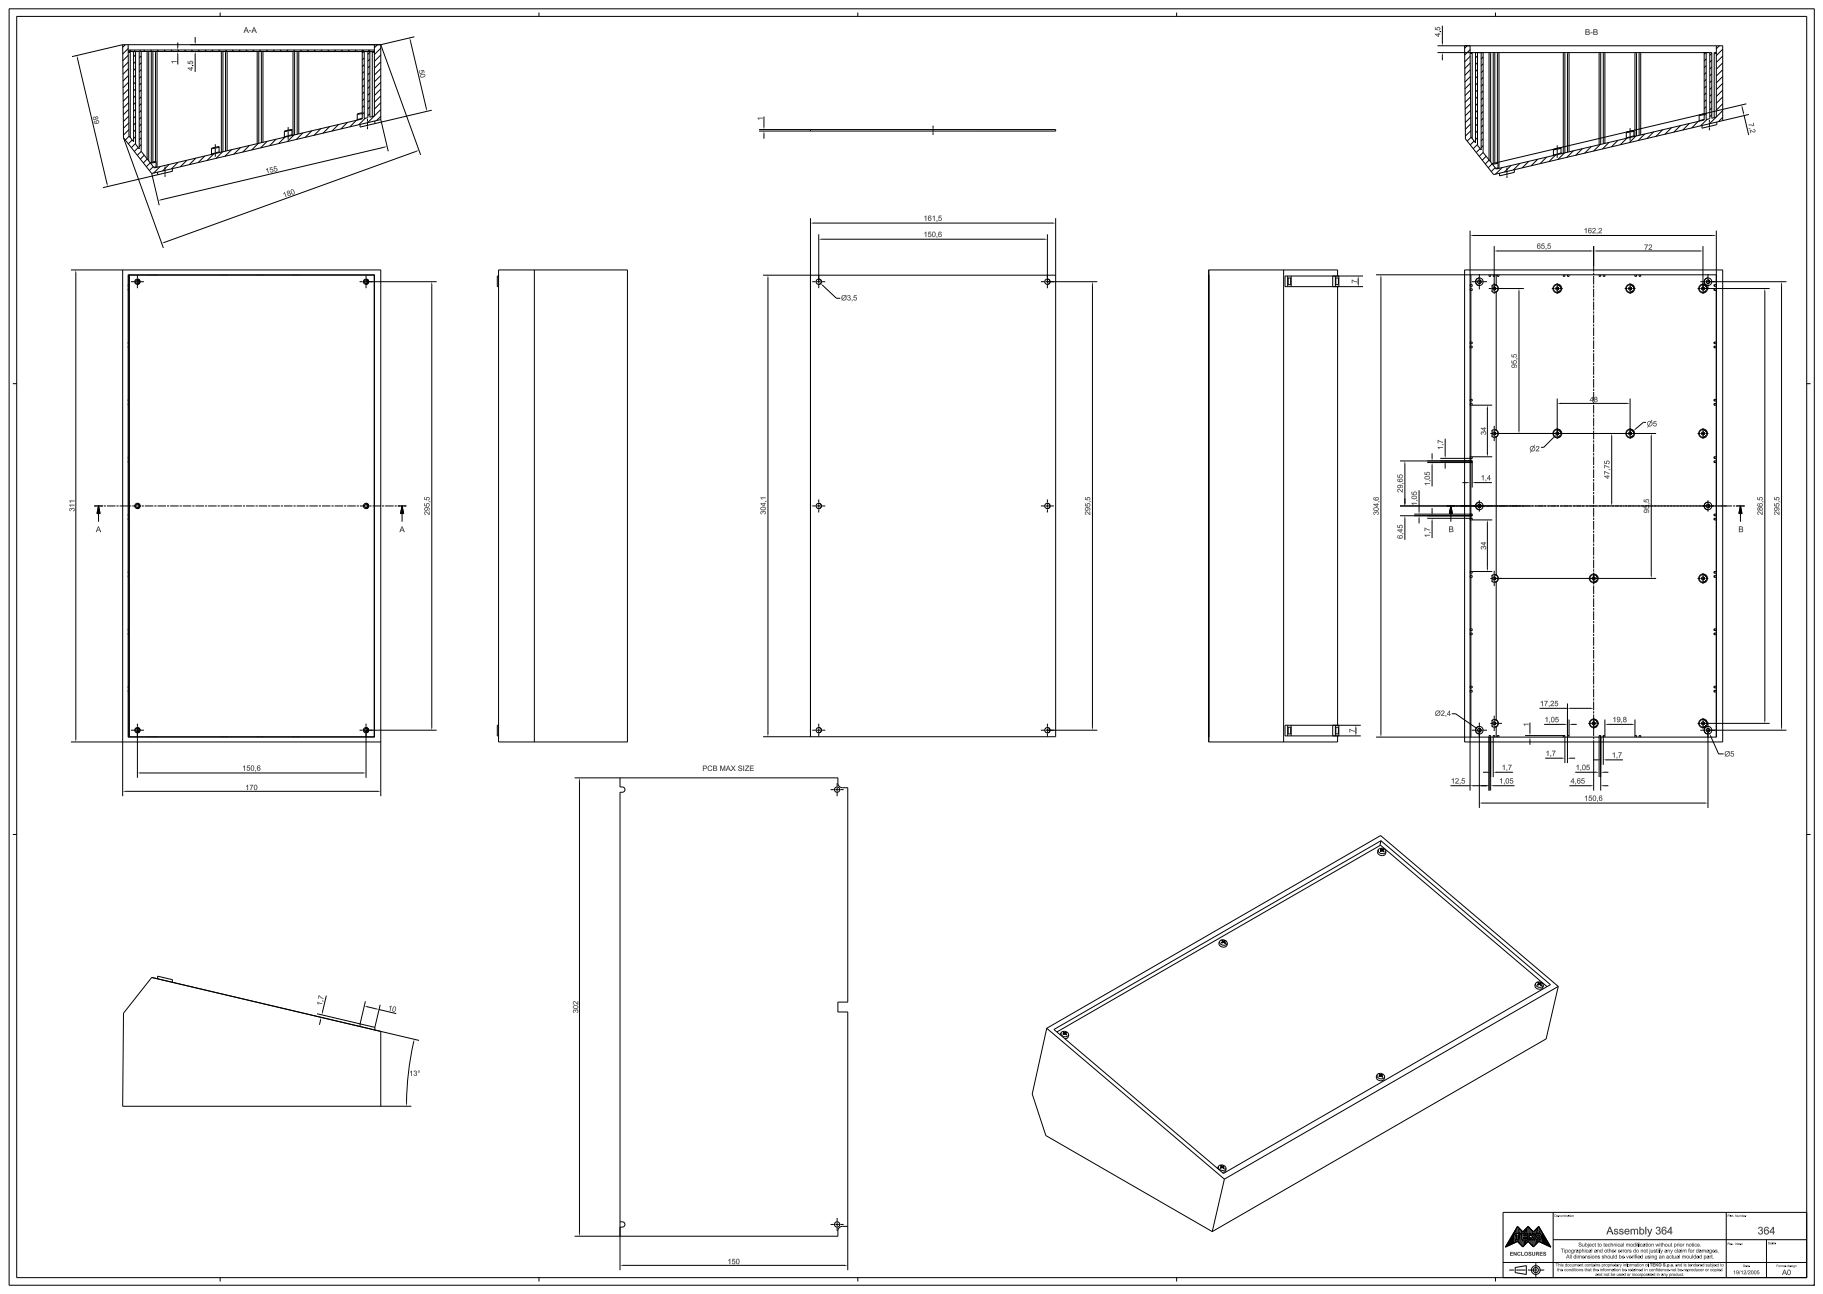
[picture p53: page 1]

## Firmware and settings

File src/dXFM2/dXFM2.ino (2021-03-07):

/*
*  dXFM2 synthesizer main module
*
*  this is the main module for the dXFM2 synthesizer
*  the individual IC's are controled from submodules
*  this module will set the pinout and start of the SPI and I2C libraries
*
*/
#include "SPI.h"
#include <Wire.h>
#include <Adafruit_GFX.h>
#include <Adafruit_SSD1306.h>
#include <Fonts/Dungeon9pt7b.h>
#include <Fonts/Dungeon12pt7b.h>

#define NO_ERROR 0
#define ERR_UNIT 1
#define ERR_DUMP 2
#define ERR_LOAD 3
#define ERR_INIT 4

#define BLUE_VOLUME 0
#define BLUE_RATIO 1
#define BLUE_PITCH 2
#define BLUE_FEEDBACK 3
#define BLUE_DURATION 4
#define BLUE_LEVEL 5
#define BLUE_LEDS 6

#define GREEN_LFO 0
#define GREEN_OSC 1
#define GREEN_OPS 2
#define GREEN_EFX 3
#define GREEN_MASTER 4
#define GREEN_LFO_UNIT2 5
#define GREEN_OSC_UNIT2 6
#define GREEN_OPS_UNIT2 7
#define GREEN_EFX_UNIT2 8

#define DISPLAY_NORMAL 0
#define DISPLAY_OVERVIEW 1
#define DISPLAY_MENU 2

#define PARAMTYPE_DEFAULT 0
#define PARAMTYPE_TOGGLE 1
#define PARAMTYPE_CLICK 2
#define PARAMTYPE_LEDCLICK 3
#define PARAMTYPE_ENV 4

#define ENVMODE_ADDSRR 0
#define ENVMODE_RATE 1
#define ENVMODE_ADSR 2
#define ENVMODE_ASR 3

//Go back to the overview display after 2 seconds
#define DISPLAYPERIOD 2000

//Set this to the targetted serial interface
//Serial = USB serial, for debugging
//Serial1 = XFM2 serial, for real-live purpose
#define HWSERIAL Serial1

//Need to put the typedef here, for function's sake...
typedef struct {
  uint8_t unit; //the unit that is selected
  uint16_t param; //the parameter that is selected
} param_type;

//Typedef for envelope
//dly = time for the envelope to start
//r1 = rate of the attack phase (0 = slow, 255 = fast)
//r2 = rate of the decay-1 phase
//r3 = rate of the decay-2 phase
//r4 = rate of the release-1 phase
//r5 = rate of the release-2 phase
//l0 = level at start of the envelope
//l1 = level after the attack phase
//l2 = level after the decay-1 phase
//l3 = level after the decay-2 phase (= sustain level)
//l4 = level after the release-1 phase
//l5 = level after the release-2 phase (= end level)
typedef struct {
  uint8_t rate[6];  //dly, r1, r2, r3, r4, r5
  uint8_t level[6]; //l0, l1, l2, l3, l4, l5
} env_type;

const uint8_t MAXPIN_LOAD = 10; //LOAD pin for Teensy of the MAX7219CNG chip

//Default menu: OSC of unit 1, Volume
uint8_t greenSelect = 2;
uint8_t blueSelect = 0;
uint8_t operatorSelect = 0; //Selected operator, often the same as operator used, except for envelopes
uint8_t operatorUsed = 0; //Operator actually used
uint8_t toggleMode = 0; //Sets the toggle mode
uint8_t patchSelect = 0; //The active patch
bool patchChanged = false; //True if the patch is changed without saving it
bool dx7LegacyMode = false; //Don't go into legacy mode! (it's not allowed ;-))

uint8_t displayMode = DISPLAY_OVERVIEW; //Sets the overview mode (extra information, is temporarilly set to DISPLAY_NORMAL whenever you hit a button)
unsigned long lastChange = 0; //Sets the time when you last hit a button

//Set to true when an interrupt arrives: don't do anything till the interrupt is processed (or bad things will happen due to concurrency!!!)
bool rotating = false;

void setup() {
  setupParams();
  setupMenu();

  //We begin with the LEDs, splash them and continu with the OLED screens
  pinMode(MAXPIN_LOAD, OUTPUT); //MAXPIN_LOAD is defined in the submodule
  SPI.begin();
  setupLEDButtons(); //setup instructions for the LED buttons
  splashLEDs(); //default splash screen for the LEDs

  //Next, we initialize the MCP23017 for the encoders
  Wire.begin();
  setupEncoders();

  //Next, we splash the OLED screens
  setupScreens();
  splashScreens();

  //Start serial interface
  HWSERIAL.begin(500000);

  delay(1000); //one seconds splash screen

  //Start communication with the XFM2
  uint8_t errorCode = initXFM2();
  if (errorCode>0) {
    showError(errorCode);
    delay(2000);
  }

  initLEDs(); //Initialize LEDs to startup position
  initScreens(); //Initialize OLED screens to startup position

  doMenuChange(); //Set OLED screens to current menu
}

void loop() {
  rotating = false;
  scanLEDButtons();
  delay(50); //Some delay to mitigate bouncing, should be done with timer and not a delay - whatever for now!
  if (!rotating && blueSelect==0) {
    //Only check this when not rotating!
    if (millis() - lastChange > DISPLAYPERIOD) {
      //Some time has past
      if (displayMode!=DISPLAY_OVERVIEW) {
        //displaymode wasn't overview, so make it active and show the new screens (if any)
        noInterrupts(); //Can't have interrupts now!
        displayMode = DISPLAY_OVERVIEW;
        doMenuChange();
        interrupts();
      }
    }
  }
}

//Reset the last change, so the displaymode will be set to DISPLAY_NORMAL for the DISPLAYPERIOD
void resetLastChange() {
  displayMode = DISPLAY_NORMAL;
  lastChange = millis();
}

//A LED button was pressed, respond!
void doLEDButtonPressed(uint8_t row, uint8_t col, uint8_t menu, uint8_t btn) {
  resetLastChange();
  if (menu==7) {
    //Blue menu toggle
    toggleLEDRow(row,col,menu,btn);
    if (blueSelect==btn) {
      toggleMode = 1-toggleMode; //Same blue button selected, so toggle
    } else {
      toggleMode = 0; //Different button selected, so toggle to mode 0
    }
    blueSelect = btn;
    //Respond to menu change
    doMenuChange();
  } else {
    if (menu>7) {
      //Green menu toggle (a bit of a hack: buttons might not have the correct value, but we don't use that anyway...)
      clearLEDRow(5);
      clearLEDRow(7);
      toggleLEDRow(row,col,menu,btn);
      //Respond to menu change
      toggleMode = 0;
      greenSelect = btn;
      doMenuChange();
    } else {
      //Operator matrix set/unset
      toggleLED(row,col,menu,btn);
      toggleLEDParamValueBit(menu,btn);
      if (menu==6) {
        //Do change for carriers
        activateChange(greenSelect,BLUE_LEDS,0,btn,0);
      } else {
        //Do change for modulators
        activateChange(greenSelect,BLUE_LEDS,0,menu,0);
      }
    }
  }
}

//An encoder was used, respond!
void doEncoderUsed(uint8_t encoder, bool clicked, uint8_t value) {
  if (encoder<7) {
    resetLastChange();
    uint8_t paramType = getParamType(greenSelect,blueSelect,operatorSelect,encoder,0);
    if (paramType==PARAMTYPE_ENV) {
      if (clicked) {
        if (encoder<6) { //Only operator encoders can be selected, ignore clicking the output-operator
          uint8_t oldSelected = operatorSelect;
          operatorSelect = encoder;
          showDisplay(oldSelected); //Reset the display that is no longer selected
          for (uint8_t op=0; op<7; op++) {
            //Set encoder to the correct value for that operator
            setEncoderValue(op,getParamValue(greenSelect,blueSelect,operatorSelect,op,0));
          }
        }
      } else {
        if (blueSelect==BLUE_LEVEL && toggleMode==1) {
          operatorSelect = encoder;
          operatorUsed = encoder;
          setParamValue(greenSelect,blueSelect,operatorSelect,encoder,1,value);
          activateChange(greenSelect,blueSelect,operatorSelect,encoder,1);
        } else {
          operatorSelect = operatorSelect<6 ? operatorSelect : 0; //Failsafe to make sure that output is not selected
          operatorUsed = encoder;
          setParamValue(greenSelect,blueSelect,operatorSelect,encoder,0,value);
          activateChange(greenSelect,blueSelect,operatorSelect,encoder,0);
        }
        if (blueSelect==BLUE_DURATION) {
          if (encoder==1 && toggleMode==1) {
            //In duration and toggleMode=1, decay-1 will also change release-1, making it an ASR envelope (for plucked sounds)
            setParamValue(greenSelect,BLUE_DURATION,operatorSelect,4,0,value);
            activateChange(greenSelect,BLUE_DURATION,operatorSelect,4,0);
          }
          if (encoder==4 && toggleMode==1) {
            //In duration and toggleMode=1, release-1 will also change decay-1, making it an ASR envelope (for plucked sounds)
            setParamValue(greenSelect,BLUE_DURATION,operatorSelect,1,0,value);
            activateChange(greenSelect,BLUE_DURATION,operatorSelect,1,0);
          }
          if (encoder==3) {
            //In duration, sustain will also change the L2 level, making it a regular ADSR envelope (actually an ADSRR...)
            setParamValue(greenSelect,BLUE_LEVEL,operatorSelect,1,0,value);
            activateChange(greenSelect,BLUE_LEVEL,operatorSelect,1,0);
          }
        }
      }
    } else {
      if (paramType==PARAMTYPE_LEDCLICK) {
        if (clicked) {
          operatorUsed = encoder;
          operatorSelect = encoder;
          toggleParamValueBit(greenSelect,blueSelect,operatorSelect,encoder,1,encoder+1); //Operator 1 = bit 1
          activateChange(greenSelect,blueSelect,operatorSelect,encoder,1);
        } else {
          operatorUsed = encoder;
          operatorSelect = encoder;
          setParamValue(greenSelect,blueSelect,operatorSelect,encoder,0,value);
          activateChange(greenSelect,blueSelect,operatorSelect,encoder,0);
        }
      } else {
        if (paramType==PARAMTYPE_CLICK) {
          if (clicked) {
            operatorUsed = encoder;
            operatorSelect = encoder;
            toggleParamValueBit(greenSelect,blueSelect,operatorSelect,encoder,1,encoder); //Operator 1 = bit 0
            activateChange(greenSelect,blueSelect,operatorSelect,encoder,1);
          } else {
            operatorUsed = encoder;
            operatorSelect = encoder;
            setParamValue(greenSelect,blueSelect,operatorSelect,encoder,0,value);
            activateChange(greenSelect,blueSelect,operatorSelect,encoder,0);
          }
        } else { //PARAMTYPE_DEFAULT or PARAMTYPE_TOGGLE
          operatorUsed = encoder;
          operatorSelect = encoder;
          setParamValue(greenSelect,blueSelect,operatorSelect,encoder,toggleMode,value);
          activateChange(greenSelect,blueSelect,operatorSelect,encoder,toggleMode);
        }
      }
    }
    //A bit of a hack, better if this is done via paramType
    if (greenSelect==GREEN_OSC && (blueSelect==4 || (blueSelect==5 && toggleMode==0))) {
      showDisplay(6);
    } else {
      /*
      if (greenSelect==GREEN_EFX && blueSelect==BLUE_VOLUME && operatorSelect==4) {
        showDisplay(3);
      } else {
        showDisplay(operatorSelect);
      }*/
      showDisplay(operatorSelect);
      /*
      DISABLED: Was necessary to have a screen per effect, we now go back to a screen per dial!
      if (greenSelect==GREEN_EFX) {
        showDisplay(5-blueSelect);
        if (blueSelect==0) {
          showDisplay(6);
        }
      } else {
        showDisplay(operatorSelect);
      }
      */
    }
  } else {
    if (encoder==9) {
      resetLastChange();
      if (clicked) {
        //Laden van een programma
        clearAlgoLEDs(); //Algorithm LEDs will be off during loading process
        patchSelect = value;
        if (xfm2LoadPatch(patchSelect)) {
          if (xfm2GetActiveProgram(0)) {
            updateLEDs();
            patchChanged = false;
            doMenuChange();
          } else {
            showError(ERR_DUMP);
          }
        } else {
          showError(ERR_LOAD);
        }
      } else {
        //Toggle door de programma's heen
        showPatchMenu(value);
      }
    } else {
      if (encoder==7) {
        //Param encoder used, show correct menu page
        resetLastChange();
        displayMode = DISPLAY_MENU;
        showParamMenu(value,getMenuParamdata(value));
        setEncoderValue(8,getMenuParamdata(value));
        setEncoderMax(8,getMenuMaxValue(value));
      } else {
        if (encoder==8) {
          if (displayMode==DISPLAY_MENU) {
            if (clicked) {
              //Data encoder clicked, execute menu item
              resetLastChange();
              displayMode = DISPLAY_MENU;
              executeParamMenu(getEncoderValue(7),value);
            } else {
              //Data encoder used, show correct value for menu item
              resetLastChange();
              displayMode = DISPLAY_MENU;
              setMenuParamdata(getEncoderValue(7),value);
              showParamMenu(getEncoderValue(7),value);
            }
          } else {
            //Show param menu, we want to change something!
            resetLastChange();
            displayMode = DISPLAY_MENU;
            showParamMenu(getEncoderValue(7),value);
            setEncoderValue(8,getMenuParamdata(getEncoderValue(7)));
          }
        }
      }
    }
  }
}

//Starts the serial communication to activate a change
//Maybe this can be part of setParamValue and toggleParamValueBit, but for now...
void activateChange(uint8_t green, uint8_t blue, uint8_t selOp, uint8_t usedOp, uint8_t toggle) {
  param_type param = getParam(green,blue,selOp,usedOp,toggle);
  patchChanged = true; //You changed something!!
  xfm2SetParameter(param.param,getParamValueQuick(param));
}

// Menu change, all screens are affected!
void doMenuChange() {
  operatorUsed = 0; //Reset operator used
  for (uint8_t op=0; op<7; op++) {
    //Set encoder to the correct value for that operator
    setEncoderValue(op,getParamValue(greenSelect,blueSelect,operatorSelect,op,toggleMode));
    setEncoderMax(op,getParamMax(greenSelect,blueSelect,operatorSelect,op,toggleMode));
    showDisplay(op);
  }
}

void startDemo() {
  for (uint8_t screen=0; screen<7; screen++) {
    showScreenBorder(screen);
  }
}

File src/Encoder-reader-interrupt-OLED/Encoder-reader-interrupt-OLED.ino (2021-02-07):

/*
* Test of all encoders
*
* NB: Chip will NOT be reset when new code is uploaded, so please: disconnect before re-upload code!!!
*
* Pin layout:
* - Pin 1 (closed to pins from encoder) INT chip A -> To pin 2 of Teensy
* - Pin 2 INT chip B -> To pin 3 of Teensy
* - Pin 3 3.3V -> To 3V pin of Teensy
* - Pin 4 GND -> To GND pin of Teensy
* - Pin 5 SCL -> To pin 19 of Teensy, using 4.7K pull-up resistor
* - Pin 6 SDA -> To pin 18 of Teensy, using 4.7K pull-up resistor
*
* Important structure is encoder, this is the last used encoder
* and encoders[encoder], which gives you the values of the last used encoder:
* - buttonPressed: true as long as a button is pressed (hold down)
* - buttonClick: true when a button is pressed (but released immediatly thereafter)
* - value: the current value of the encoder, range 0 - 255 (as used by the XFM2)
*
* TODO: speedup the increments of the encoder, depending on the "speed" of the turn
*/

//#include <SPI.h>
#include <Wire.h>
#include <Adafruit_GFX.h>
#include <Adafruit_SSD1306.h>
#include <Fonts/Dungeon9pt7b.h>
#include <Fonts/Dungeon12pt7b.h>

#define SCREEN_WIDTH 128 // OLED display width, in pixels
#define SCREEN_HEIGHT 64 // OLED display height, in pixels
#define OLED_RESET -1 //Share reset with Arduino reset pin
Adafruit_SSD1306 display(SCREEN_WIDTH, SCREEN_HEIGHT, &Wire, OLED_RESET);

const uint8_t GPPUA = 0x0C; //Pull-up resistor PortA
const uint8_t GPIOA = 0x12; //GPIO register PortA
const uint8_t INTCAPA = 0x10; //GPIO values at time of the interupt PortA
const uint8_t IOCON = 0x0A; //Configuration
const uint8_t GPINTENA = 0x04; //Interupt settings PortA
const uint8_t INTFA = 0x0E; //Interrupt flag register PortA

const uint8_t MCP23017[2] = {0x20,0x24};

int8_t encoder = -1; //Encoder that is used, range 0-9, -1 means: no encoder used
typedef struct {
  bool buttonPressed; //true when button is pressed, remains true while button is pressed
  bool buttonClick; //true when button is clicked, only true ones every button press (resets after button release)
  uint8_t value;
} encoder_type;
encoder_type encoders[10]; //Encoder values 0-9

bool rotating = false; //debounce management

// 0 = PortA of IC 0x20
// 1 = PortA of IC 0x24
// 2 = PortB of IC 0x20
// 3 = PortB of IC 0x24
uint8_t portsValue[4] = {0,0,0,0};
uint8_t portsValueOld[4] = {0,0,0,0};

typedef struct {
  uint8_t encPort;
  uint8_t encAbit;
  uint8_t encBbit;
  uint8_t btnPort;
  uint8_t btnBit;
} encoderBits_type;                      //0           1           2           3           4           5           6           7           8           9
const encoderBits_type encoderBits[10] = {{1,1,0,1,2},{2,5,6,2,7},{2,4,3,0,4},{0,0,2,0,1},{1,5,6,1,7},{2,2,1,2,0},{0,6,7,0,5},{3,7,6,3,5},{3,3,4,3,2},{3,0,1,1,4}};

bool encoderALastValue[10];

typedef struct {
  uint8_t port;
  uint8_t mask;
  uint8_t encoder;
} encoderMask_type;
const encoderMask_type encoderMask[12] = {{3,B11100000,7},{3,B00011100,8},{3,B00000011,9},
                                          {1,B00000111,0},{1,B00010000,9},{1,B11100000,4},
                                          {2,B11100000,1},{2,B00011000,2},{2,B00000111,5},
                                          {0,B00000111,3},{0,B00010000,2},{0,B11100000,6}};

void setupEncoders() {
  for (int i=0; i<10; i++) {
    encoders[i].buttonPressed = false;
    encoders[i].buttonClick = false;
    encoders[i].value = 0;
    encoderALastValue[i] = LOW;
  }
}

void setupMCP23017(uint8_t portOffset) {
  Wire.beginTransmission(MCP23017[portOffset]);
  Wire.send(IOCON);
  Wire.send(0b01000000); //Enable sequential addresses, 16-bit mode, mirror interupts, active-low interupt
  Wire.send(0b01000000); //Enable sequential addresses, 16-bit mode, mirror interupts, active-low interupt
  Wire.endTransmission();

  //Default mode of the MCP23017 is GPIO pins as input, so we don't need to set this up

  //Configure pull-ups
  Wire.beginTransmission(MCP23017[portOffset]);
  Wire.send(GPPUA);
  Wire.send(0b11111111); //Pull-ups for Port-A
  Wire.send(0b11111111); //Pull-ups for Port-B
  Wire.endTransmission();

  //Configure interupts
  Wire.beginTransmission(MCP23017[portOffset]);
  Wire.send(GPINTENA);
  Wire.send(0b11111111); //Interrupts for Port-A
  Wire.send(0b11111111); //Interrupts for Port-B
  Wire.endTransmission();
  //INTCOND and DEFVAL remain at default positions, meaning pins are compared to previous pin value
}

void reactToEncoder() {
  //This function is called whenever an encoder is used
  //It should look at the value of encoders[encoder]
  if (encoder>=0) {
    showValue(encoders[encoder].value);
  }
}

void doInterruptA() {
  if ( rotating ) delay (1);  // wait a little until the bouncing is done
  scanEncoders(0);
  rotating = false;
}

void doInterruptB() {
  if ( rotating ) delay (1);  // wait a little until the bouncing is done
  scanEncoders(1);
  rotating = false;
}
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

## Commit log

2020-11-01 Update beschrijving OLED en encoder
    [teensy-oled.fzz]
2020-11-02 Tekst toegevoegd over pull-up resistors
2020-12-06 Added circuits
    [Analog button selector.fzz, Power source regulator.fzz, buttons-red-ic.fzz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]
2020-12-06 Added power consumption details
2020-12-06 Added components description
    [Components.fzz, MCP23017s.fzz]
2020-12-08 Update interfaces
    [Components.fzz, MCP23017s.fzz, Teensy.fzz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]
2020-12-08 added connections
    [MCP23017s.fzz]
2020-12-11 Schema toegevoegd
    [teensy-oled.fzz]
2020-12-13 Added TCA9548A OLEDs solution
    [TCA9548A-OLEDs.fzz]
2020-12-13 Added BOM
2020-12-13 Added BOM to power pcb
    [Power source regulator.fzz]
2020-12-13 Added teensy pcb doc
2020-12-13 Added missing pcbs
    [MCP23017s.fzz, buttons-red.fzz]
2020-12-13 GND female headers added
    [MCP23017s.fzz]
2020-12-13 Added panel2
    [buttons-blue-ic.fzz, buttons-red.fzz]
2020-12-13 Detailed pcb wiring
    [buttons-red.fzz, buttons.fzz, panel6.fzz]
2020-12-14 Added panels 4,5,6
    [panel4.fzz, panel5.fzz, panel6.fzz]
2020-12-19 Added PCB dimensions
    [XFM2.fzz]
2020-12-19 Update power routing
    [XFM2.fzz]
2020-12-19 Added enclosure specs
    [Teensy.fzz, enclosure-pcb.fzz]
2020-12-19 Added PCB count
2020-12-19 Made specs for front panel
    [TCA9548A-OLEDs.fzz, buttons-blue-ic.fzz, front-panel.fzz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]
2020-12-19 Added BOM to XFM2 specs
2020-12-22 Added build
    [XFM2.fzz]
2020-12-22 Updated OLED panel dimension - start on pull ups
    [TCA9548A-OLEDs.fzz, front-panel.fzz]
2020-12-28 Changed to current result
    [TCA9548A-OLEDs.fzz]
2021-01-14 Updated panels
    [buttons-blue-ic.fzz, front-panel.fzz, panel3-4.fzz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]
2021-01-15 Panel 2 and 5
    [panel2-5.fzz]
2021-01-16 Aangepast aan pcb
    [panel2-5.fzz]
2021-01-17 set to pcb
    [MCP23017s.fzz, panel2-5.fzz]
2021-01-25 Added simple rotary encoder test
2021-01-31 Added full 10 encoders test
2021-01-31 Added pin layout
2021-02-02 First version OLED and encoders
2021-02-07 Added first button and led test
2021-02-07 Update power pcb
    [Power source regulator.fzz]
2021-02-07 Added scan to button test
2021-02-07 Added encoders
2021-02-10 Fix for LFO menu
    [Menus.ino]
2021-02-11 Changed menu to Display: more correct name
    [Displays.ino]
2021-02-14 Added first try for LEDs
2021-02-14 Added LED parameter setters
2021-02-14 First part of setting LEDs via params
2021-02-15 Added paramater initialization for LEDs
2021-02-15 Fixed feedback display and added output gain display
    [Displays.ino, LEDButtons.ino, Params.ino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]
2021-02-15 Fixed algo matrix setters
    [XFM2.ino, dXFM2.ino]
2021-02-17 Revert back to higher res
    [Screens.ino, Waves.ino]
2021-02-19 Added encoder max values and wave display
2021-02-20 Added wiring instructions
2021-02-23 Added pitch envelope display
2021-02-24 First try for effects, range for pitch envelope
2021-02-25 First try for filter curve
2021-02-25 Optimized filter curve
2021-02-25 moved fritzing files
    [Analog button selector.fzz, Components.fzz, MCP23017s.fzz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]
2021-02-26 Fixed sync display: 1 = sync
    [Screens.ino]
2021-02-27 Optimized conversion, fixed some errors and changed patch defs
    [Patches.ino]
2021-02-27 Changed patch structure and added missing patches
    [Patches.ino]
2021-02-28 Incorred wave shape: shape 4 and 5 are swapped
    [Waves.ino]
2021-02-28 Updated key scale display and fixed pitch display
    [Displays.ino, Params.ino, Screens.ino]
2021-02-28 Optimized fixed pitch calculation
    [Screens.ino]
2021-03-01 Algo LEDs off during load process
2021-03-04 Added some extra spec for fixed ratio calculation and conversion
    [Screens.ino]
2021-03-04 Added correct conversion rate for fixed pitch
2021-03-04 Correct calculation of fine pitch, using log functions - both ratio and fixed pitch
    [Patches.ino]
2021-03-06 Fixed ADSR and ASR modes
    [dXFM2.ino]
2021-03-06 Added first version missing efx parameters
    [Displays.ino, Screens.ino]
2021-03-11 Added fm synthesis spreadsheet
    [fmsynthesis.xlsx]
2021-03-11 Small change to graph display
    [fmsynthesis.xlsx]
2021-03-11 Add feedback
    [fmfeedback.xlsx]
2021-03-14 Added some more calculation on the modulation level vs modulation index
    [DX7ModulationIndex.xlsx]
2021-03-14 Added correct calculation
    [DX7ModulationIndex.xlsx]
2021-03-15 Added info on feedback filter
